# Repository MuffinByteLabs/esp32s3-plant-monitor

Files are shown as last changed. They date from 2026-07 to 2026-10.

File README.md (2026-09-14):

# ESP32-S3 Plant Monitor — Rev A

**Ray Malik** · [muffinbytelabs.com](https://muffinbytelabs.com) · [muffinbytelabs@gmail.com](mailto:muffinbytelabs@gmail.com)

A solo hardware project taken the whole way: requirements → schematic capture → 4-layer layout → DFM → fab and assembly order → bring-up. Every schematic, review, waiver and decision in this repo is my own work.

Wi-Fi plant monitor: soil moisture, temperature / humidity / pressure, and ambient light, USB-C powered with 1-cell LiPo charging and automatic USB↔battery hand-over. Native-USB programming, no bridge chip. KiCad 10 hierarchical schematic, **4-layer board** (signal / GND / GND / signal, JLC04161H-7628), 62.5 × 44.5 mm, ordered fabricated and assembled at JLCPCB on **2026-08-21**.

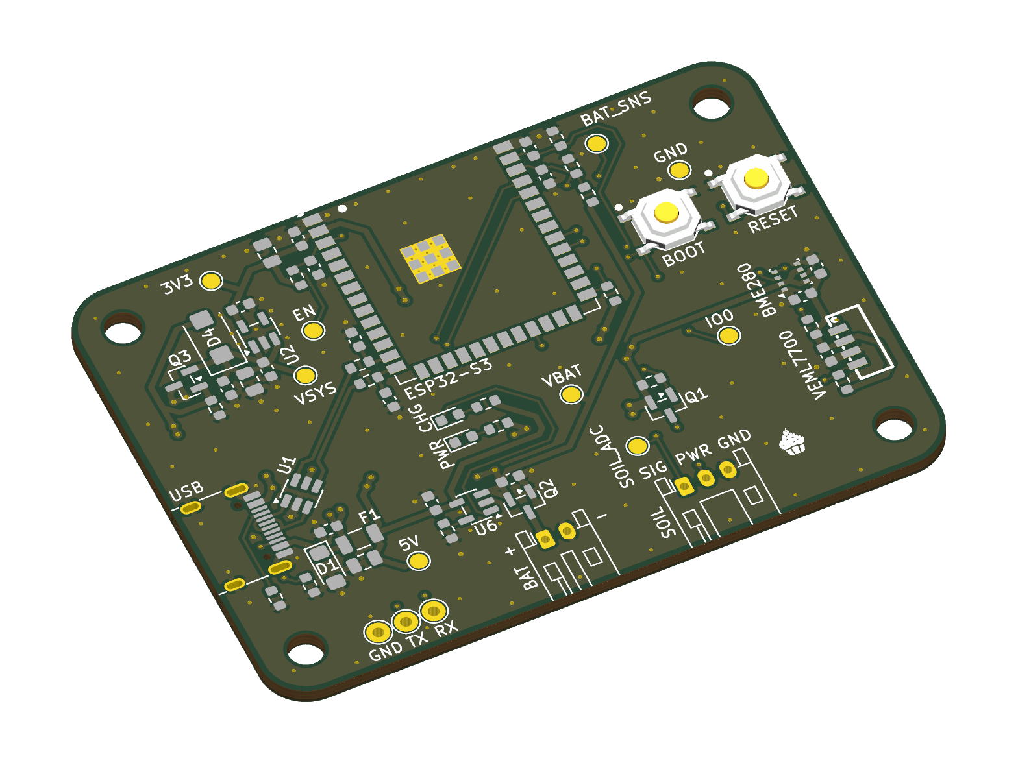
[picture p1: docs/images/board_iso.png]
ESP32-S3 Plant Monitor Rev A — 3D render


| | |
|---|---|
| **MCU** | ESP32-S3-WROOM-1-N8, native USB — no bridge chip |
| **Sensors** | BME280 (temperature / humidity / pressure) · VEML7700 (ambient light) · DFRobot SEN0193 capacitive soil probe |
| **Power** | USB-C 5 V → PPTC + TVS → AP2112K-3.3 (600 mA) · MCP73831 1S LiPo charger · discrete USB↔battery load share, hand-over in ≈50–100 ms |
| **Sleep** | ≈210 µA as built (≈90 µA with the power LED unfitted) ⇒ ~100 days on a 500 mAh cell |
| **Board** | 62.5 × 44.5 mm · 4-layer, JLC04161H-7628 · 1.6 mm · lead-free HASL · 404 track segments, 154 vias |
| **Verification** | 6 written reviews · 20 packages / 69 placements checked against datasheets |
| **Built** | 5 boards fabricated + assembled for ≈$49 after coupons, every part pre-stocked in the JLC library |
| **Tools** | KiCad 10 · JLCPCB Standard PCBA |

## Start here

Everything below opens in the browser — no KiCad install, no downloads.

| | |
|---|---|
| 📐 **[Schematic (PDF, 8 sheets)](docs/ESP32S3_PlantMonitor_RevA_Schematic.pdf)** | The whole design, plotted from the board file that was ordered |
| 📄 **[Design document](docs/ESP32S3_Plant_Monitor_Final_Design_Document.md)** | Every component and why it is there, written to be read by someone who is not a PCB engineer |
| 🔍 **[Design reviews — 6 on file](docs/reviews/)** | Real review records with findings, severities and fixes. The pre-fab review caught **3 blocking errors** — floating USB-C ground pins, a missing battery-sense chain, and a stale BOM — all resolved before ordering |
| 🧭 **[What I'd change in Rev B](docs/RevB_Upgrade_Plan.md)** | Ranked upgrades with a three-way charger-IC comparison and a costed path from 210 µA to 15–35 µA |
| 🧪 **[Engineering notes](docs/Engineering_Notes.md)** | Bench measurements: soil calibration, the three-layer battery-protection analysis, the hand-over walkthrough |
| 🏭 **[Frozen manufacturing package](fabrication/revA/)** | The exact gerber zip, BOM and CPL uploaded to JLCPCB, beside [`ORDER_NOTES.md`](fabrication/revA/ORDER_NOTES.md) — every setting the board was ordered with |
| 🔧 **[Bring-up guide](docs/BringUp_Guide.md)** | First-power procedure, expected voltages, probe points, troubleshooting |
| 🖨 **[Fab layer plots (PDF)](docs/ESP32S3_PlantMonitor_RevA_FabLayers.pdf)** | All four copper layers, both silks, mask and paste — what the fab actually receives |

| Top | Bottom |
|---|---|
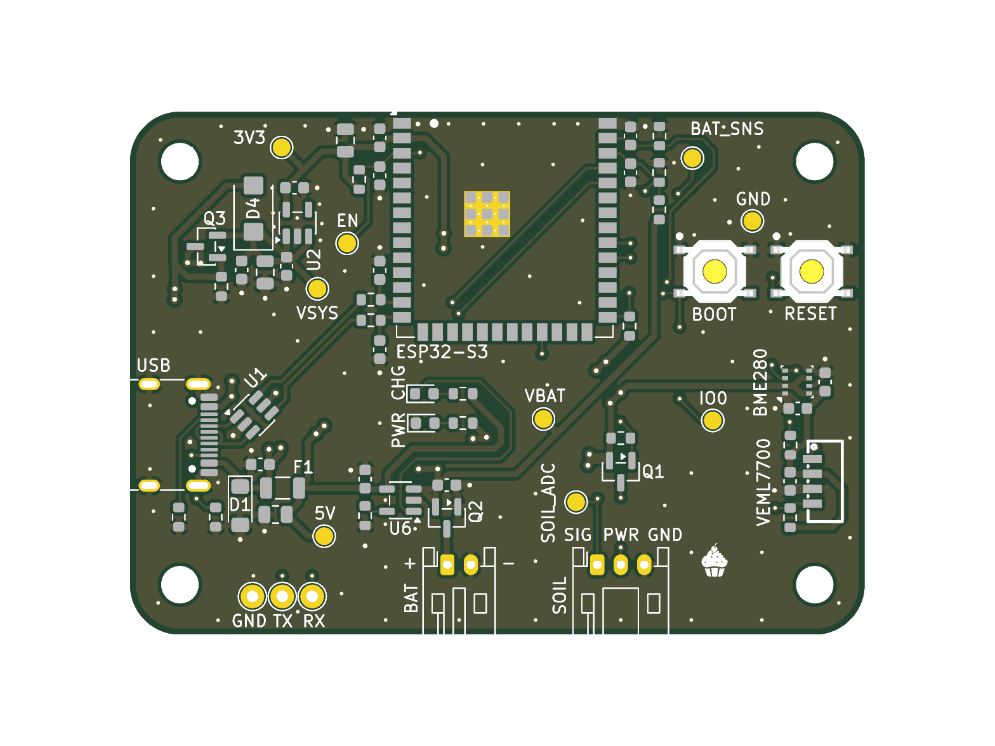
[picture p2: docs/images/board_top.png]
Top
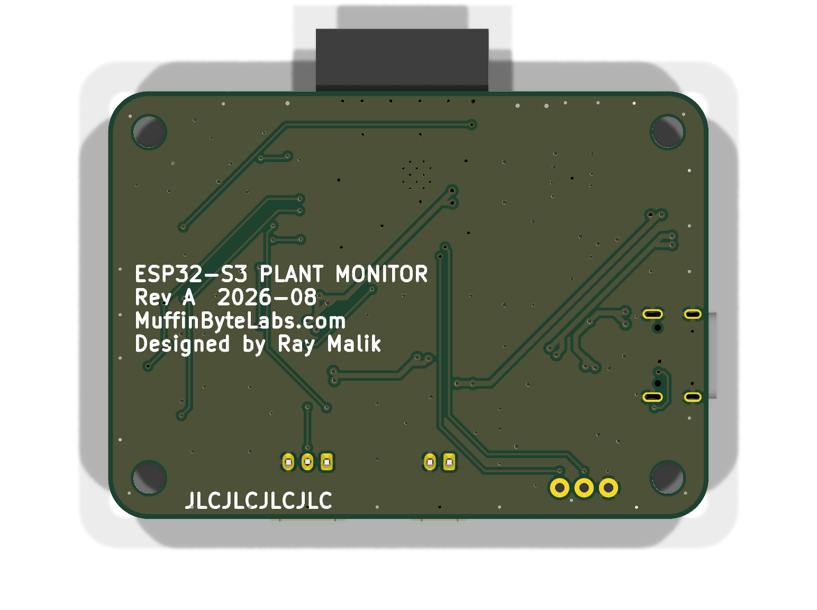
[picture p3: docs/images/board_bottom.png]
Bottom
|  |  |

## What this board demonstrates

- **4-layer discipline** — dual unbroken ground planes, zero signals on the inner layers, a via at every decoupler, stitching around the antenna keep-out.
- **RF module integration** — antenna nose overhanging the board edge, all-layer keepout, ground ring, and a panel-rail instruction written into the fab remark so breakaway tabs cannot sit under the overhang.
- **USB 2.0 pair** at ≈90 Ω coupled geometry, length-matched, no vias, ESD in copper order.
- **Power-path design with numbers** — fuse → TVS → LDO, an automatic USB↔battery hand-over sized so the switch completes in ≈50–100 ms, and a 210 µA sleep budget with a named dominant contributor.
- **Manufacturing fluency** — DFM checked against JLCPCB's live capability pages, part-tier economics understood before ordering, pre-stocked parts library, DDP tariff handling.
- **A documentation trail** — two design reviews, a placement review, a finishing review, a final layout audit, and order notes, all on record here.

## What I'd change in Rev B

- **The power path is discrete, and it shows.** MCP73831 + Schottky + P-FET load-sharing works, but it has a ≈50–100 ms body-diode notch at USB unplug, a Vgs-dependent switch point, and no charge safety timer. Rev B replaces the four-part cluster with one IC — [BQ24075 vs MCP73871 vs TPS2113A, compared](docs/RevB_Upgrade_Plan.md#1-integrated-power-path-the-headline-upgrade).
- **210 µA of sleep current is too high**, and the power LED alone is 120 µA of it. LED on a solder jumper, a nanopower LDO, and a switched sense divider get it to 15–35 µA — months to years of standby instead of weeks.
- **No series element on the soil-probe ADC input.** The probe cable is a metre-long antenna into a bare pin; Rev A has only a parallel pull-down. Series resistor plus TVS at J2 next time.
- **Four layers were bought for margin, not for speed.** The fastest signal on this board is USB Full Speed — a disciplined 2-layer board would have worked. The reasoning for spending the extra layers is written down in [`docs/KiCad_Settings_RevA.md`](docs/KiCad_Settings_RevA.md).

<details>
<summary><strong>Repository map</strong> — 24 documents, KiCad sources, frozen fab package, datasheets</summary>

| Path | What |
|---|---|
| [`hardware/`](hardware/) | KiCad 10 project — root sheet + sheets 02–08, libraries in `hardware/libs/`. Library paths are `${KIPRJMOD}`-relative; keep `libs/` inside `hardware/`. |
| [`fabrication/revA/`](fabrication/revA/) | The frozen order package: gerber zip, BOM, CPL, and `ORDER_NOTES.md` (§7 = the as-ordered record) |
| **Documents** | |
| [`docs/ESP32S3_PlantMonitor_RevA_Schematic.pdf`](docs/ESP32S3_PlantMonitor_RevA_Schematic.pdf) | All 8 schematic sheets, plotted from the ordered board file |
| [`docs/ESP32S3_PlantMonitor_RevA_FabLayers.pdf`](docs/ESP32S3_PlantMonitor_RevA_FabLayers.pdf) | Layer-by-layer fab plots |
| [`docs/ESP32S3_Plant_Monitor_Final_Design_Document.md`](docs/ESP32S3_Plant_Monitor_Final_Design_Document.md) | The full design document — as-built designators throughout; Addendum A holds the renumbering record |
| [`docs/PROJECT_STATUS.md`](docs/PROJECT_STATUS.md) | Rev A order and build log: what was ordered, what it cost, order-day problems and fixes, waivers on record |
| [`docs/BringUp_Guide.md`](docs/BringUp_Guide.md) | First-power procedure, expected voltages, probe points |
| [`docs/PinMap_CheatSheet.md`](docs/PinMap_CheatSheet.md) | GPIO / net / connector map, as built |
| [`docs/Engineering_Notes.md`](docs/Engineering_Notes.md) | Bench notes: calibration values, battery-protection analysis, hand-over walkthrough |
| [`docs/ESP32S3_PlantMonitor_RevA_BOM.md`](docs/ESP32S3_PlantMonitor_RevA_BOM.md) | BOM as a readable table (the [`.xlsx`](docs/ESP32S3_PlantMonitor_RevA_BOM.xlsx) is the editable source) |
| **Layout rulebooks** | |
| [`docs/Hard_Rules_Layout_RevA.md`](docs/Hard_Rules_Layout_RevA.md) | The graded rulebook — LAW vs STRONG PRACTICE, plus 4-layer amendments |
| [`docs/Routing_Guide_RevA_4Layer.md`](docs/Routing_Guide_RevA_4Layer.md) | Layer strategy, net-by-net routing order, via craft |
| [`docs/KiCad_Settings_RevA.md`](docs/KiCad_Settings_RevA.md) | Every board-setup value and the reasoning behind it |
| [`docs/Layout_Readiness_and_Placement_Guide_RevA.md`](docs/Layout_Readiness_and_Placement_Guide_RevA.md) | Footprint verification + placement playbook |
| [`docs/Footprint_Check_ESP32S3_PlantMonitor_RevA.md`](docs/Footprint_Check_ESP32S3_PlantMonitor_RevA.md) | All 20 packages / 69 placements, each checked against its datasheet |
| [`docs/Footprint_Terms_and_Leeway_Guide.md`](docs/Footprint_Terms_and_Leeway_Guide.md) | Plain-English footprint terms and how much tolerance actually matters |
| [`docs/Fabrication_File_Primer.md`](docs/Fabrication_File_Primer.md) | What each gerber and drill file is, and why |
| [`docs/Finishing_Guide_RevA.md`](docs/Finishing_Guide_RevA.md) | Silkscreen, branding and pre-order finishing pass |
| [`docs/RevB_Upgrade_Plan.md`](docs/RevB_Upgrade_Plan.md) | Ranked upgrades, integrated power path first |
| **Reviews** | |
| [`docs/reviews/`](docs/reviews/README.md) | All six reviews, [indexed here](docs/reviews/README.md) with date, scope, method and outcome |
| **References** | |
| [`references/datasheets/`](references/datasheets/) | Vendor datasheets for every part — [indexed here](references/datasheets/README.md) |
| [`references/JLCPCB_Capabilities_2026-08.md`](references/JLCPCB_Capabilities_2026-08.md) | Capability quick-sheet used for DFM |
| [`references/reference-designs/`](references/reference-designs/) | Espressif DevKitC-1 schematic |
| [`firmware/`](firmware/) | The hardware→firmware contract: thresholds, sequences and pin duties the board imposes |

</details>

## What's next

Boards arrive early September. Bring-up follows [`docs/BringUp_Guide.md`](docs/BringUp_Guide.md) — measured results go into its record sheet, and a photograph of the working board replaces the render above.

Questions, or hiring: **[muffinbytelabs@gmail.com](mailto:muffinbytelabs@gmail.com)** · [muffinbytelabs.com](https://muffinbytelabs.com)

## License

Hardware design files and documentation are released under the **CERN Open Hardware Licence v2 — Permissive** (see [`LICENSE`](LICENSE)). Vendor datasheets in `references/datasheets/` remain the property of their respective manufacturers and are included for convenience only.

## Safety notes for anyone building this board

1. **Meter the battery plug polarity** before it ever touches J3 — the charge LED is not proof of polarity.
2. **Protected cells only**, and never store the board with a battery attached (≈210 µA sleep floor).
3. **Firmware enforces the battery limits**: no Wi-Fi TX below ~3.5 V, deep sleep at 3.0 V.

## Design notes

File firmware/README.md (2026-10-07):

# Firmware — Rev A

The sketch lives in [`plant_monitor/`](plant_monitor/). It is written for the
Arduino IDE, because that is what I code in, and it is split across a handful of
files in one sketch folder — the IDE opens them as tabs, so it is still one
thing to open and one button to press.

**Status: running on Rev A board #1.** It came through an 11-hour battery soak
(249 wake cycles, no resets), and as of 2026-09-13 it runs the full cycle on a
30-minute interval, logging every wake to ThingSpeak. The soil calibration is
now the board's own, re-recorded through this probe and cable at bring-up step
D-11. Bring-up is not finished: the charge-termination check, the hand-over
scope test, the battery-only cold boot and the sleep-current measurement are
still open, and [`BringUp_Progress_RevA_Board1.md`](../docs/BringUp_Progress_RevA_Board1.md)
tracks every step.

It builds for the ESP32-S3 against Arduino-ESP32 2.0.17 with Adafruit BME280
2.3.0, Adafruit VEML7700 2.1.6 and PubSubClient 2.8.0; the HTTP clients the
ThingSpeak and ntfy paths use come with the core. The 2026-08-24 build, before
those two paths went in, was warning-free at 750 kB of flash and 48 kB of RAM,
about a fifth of the app partition.

---

## The hardware contract

This is what the *board* requires of the firmware. It was written down before
any code existed, so the safety and measurement behaviour would be on record
either way. Pin assignments are in
[`../docs/PinMap_CheatSheet.md`](../docs/PinMap_CheatSheet.md).

| Duty | Rule | Why, and where it comes from |
|---|---|---|
| **Wi-Fi TX cutoff** | No transmit below **≈3.5 V** battery | A regulator rule, not a battery rule: the AP2112K needs ≈200 mV of headroom to hold 3.3 V through a 355 mA TX peak — [`Engineering_Notes.md`](../docs/Engineering_Notes.md) §4 |
| **Deep-sleep cutoff** | Shut everything down at **3.0 V** | The pack's protection module does not trip until 2.5 V. That half-volt gap belongs to firmware and nothing else — [`Engineering_Notes.md`](../docs/Engineering_Notes.md) §3 |
| **Battery reporting** | Gate battery percentage on **USB absent** | With USB connected and no cell fitted, the charger floats VBAT to ≈4.2 V and BAT_SENSE reads "full" |
| **Soil measurement** | GPIO21 LOW → wait ≥200 ms → read GPIO1 → GPIO21 HIGH | The probe is firmware-switched so it does not drain the cell between readings |
| **Soil calibration** | Dry **2267** raw, wet **1229** raw (12-bit, ATTEN=3) | Re-recorded on board #1 through its own probe and cable at bring-up step D-11, 2026-09-13. The breadboard values (2900 / 1465) left the scale without its bottom half — [`Engineering_Notes.md`](../docs/Engineering_Notes.md) §1 |
| **I²C** | BME280 at **0x76**, VEML7700 at **0x10**; `Wire.begin(38, 39)` — SDA first | Bus re-pinned to IO38/IO39 during layout — [`PinMap_CheatSheet.md`](../docs/PinMap_CheatSheet.md) |
| **Brown-out** | Expect a ≈50–100 ms dip on VSYS at USB unplug | Discrete load-sharing hand-over. If a reset appears there at low battery, relax the brown-out detector across the transition — [`BringUp_Guide.md`](../docs/BringUp_Guide.md) step 9 |

Every one of those rows is enforced somewhere in the code, and the code says so
at the point it does it.

---

## What one wake cycle does

There is no `loop()` in the usual sense. The board wakes from deep sleep, runs
`setup()` once, and sleeps again at the end of it.

1. **Read the battery first**, before anything expensive has loaded the cell.
2. **Below 3.0 V, stop.** No readings, no radio — sleep 6 hours and check again.
   I keep waking, rarely, because a board that stopped waking entirely could
   never notice it had been put on the charger.
3. **Switch the soil probe on** and start its 250 ms settle clock.
4. **Read the BME280 and VEML7700 while that clock runs.** The settle time has
   to be spent either way, so it may as well be spent working.
5. **Read the probe, switch it off.** Releasing GPIO21 rather than driving it
   high lets R10 hold Q1 off with no drive current, through sleep and through
   the next boot.
6. **Below 3.5 V, skip the radio** and keep the readings to myself this cycle.
   Otherwise associate, log the readings to ThingSpeak, send an ntfy push
   notification only when an alert appears, clears or is due a reminder, and
   disconnect. MQTT with Home Assistant discovery is still in the code, switched
   off with `USE_MQTT`.
7. **Sleep 30 minutes.**

A hard 30-second deadline sits over the whole thing. Any stage that finds it
gone gives up rather than starting something new — losing one reading is much
cheaper than sitting at 80 mA on a cell I want to last a hundred days.

---

## The files

| File | What is in it |
|---|---|
| [`plant_monitor.ino`](plant_monitor/plant_monitor.ino) | The wake cycle, in order, and the alert rules it applies |
| [`config.h`](plant_monitor/config.h) | Every number the board imposes — pins, thresholds, calibration, timing — with the document each came from |
| `secrets.h` | Wi-Fi credentials, the ntfy topic, and the ThingSpeak and broker keys. **Gitignored.** Never committed |
| [`secrets.h.example`](plant_monitor/secrets.h.example) | The template to copy |
| [`power.h`](plant_monitor/power.h) / [`.cpp`](plant_monitor/power.cpp) | Battery reading, the two thresholds, the discharge curve, and the only route to deep sleep |
| [`sensors.h`](plant_monitor/sensors.h) / [`.cpp`](plant_monitor/sensors.cpp) | The three measurements, each allowed to fail without costing the cycle |
| [`net.h`](plant_monitor/net.h) / [`.cpp`](plant_monitor/net.cpp) | Wi-Fi, ThingSpeak logging, ntfy push notifications, and MQTT with the Home Assistant discovery payloads |
| [`adc.h`](plant_monitor/adc.h) | The one place either analogue input gets read |
| [`log.h`](plant_monitor/log.h) | Printing that compiles away entirely when it is switched off |

The bring-up helpers sit beside the sketch: [`bringup_check`](bringup_check/) for
steps 4–6, [`sensor_check`](sensor_check/) for a plain sensor read, and
[`handover_check`](handover_check/) for steps 9 and 10.

---

## Building it

### 1. Board support

Arduino IDE → **File → Preferences → Additional board manager URLs**, add:

```
https://espressif.github.io/arduino-esp32/package_esp32_index.json
```

Then **Tools → Board → Boards Manager**, install **esp32 by Espressif Systems**.

### 2. Libraries

**Tools → Manage Libraries**, install:

* **Adafruit BME280 Library** (pulls in Adafruit Unified Sensor and Adafruit BusIO)
* **Adafruit VEML7700 Library**
* **PubSubClient** by Nick O'Leary

### 3. Credentials

Copy `plant_monitor/secrets.h.example` to `plant_monitor/secrets.h` and fill it
in. The IDE will not show `.example` as a tab, so do this in a file manager or a
terminal, then reopen the sketch.

```
copy plant_monitor\secrets.h.example plant_monitor\secrets.h     :: Windows
cp   plant_monitor/secrets.h.example plant_monitor/secrets.h     #  macOS/Linux
```

`secrets.h` is in [`.gitignore`](../.gitignore) and stays there. If it is
missing the build stops with a message saying so rather than failing somewhere
confusing.

### 4. Board settings

**Tools → Board → esp32 → ESP32S3 Dev Module**, then:

| Setting | Value | Why |
|---|---|---|
| USB CDC On Boot | **Enabled** | `Serial` is the native USB. There is no bridge chip on this board |
| USB Mode | **Hardware CDC and JTAG** | IO19/IO20 go straight to the USB Serial/JTAG peripheral |
| Upload Mode | **UART0 / Hardware CDC** | |
| Flash Size | **8MB (64Mb)** | The module is a WROOM-1-**N8** |
| PSRAM | **Disabled** | N8 has none. N8**R2** would |
| Partition Scheme | **8M with spiffs (3MB APP/1.5MB SPIFFS)** | |
| CPU Frequency | 240 MHz | Finishing the wake cycle sooner beats running it slower |

If it will not enter the bootloader on its own: hold **SW1 (BOOT)**, tap
**SW2 (RESET)**, release SW1, then upload.

---

## Things I know are not right yet

* **There is no VBUS sense line on Rev A.** I never brought +5V_PROT to a GPIO,
  so the firmware cannot actually tell whether USB is supplying the board. What
  it can tell is whether a USB *host* has opened the CDC port, and it uses that
  as a stand-in for gating the battery percentage. That is right at the bench
  and wrong on a phone charger, which supplies VBUS and never opens a port. A
  divider from +5V_PROT to a spare pin fixes it properly — it is on the Rev B
  list.
* **No OTA.** Every update is over the USB cable. On a board that spends 99.9 %
  of its life in deep sleep, an OTA window costs more current than it saves me
  walking over to it.
* **Nothing is written to flash between wakes.** If I later want gap-free
  history through a Wi-Fi outage, the readings would have to go somewhere that
  survives sleep. Right now a missed publish is simply a missed reading.

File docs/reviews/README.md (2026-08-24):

# Design Reviews — ESP32-S3 Plant Monitor Rev A

Six reviews on file, running from schematic capture to the last check before the order went to JLCPCB. Each one is a real record: what was examined, how, what was found, and what changed as a result. Nothing here is a summary written after the fact.

| Date | Review | Method | Outcome |
|---|---|---|---|
| 2026-07-20 | [Pre-fabrication design review](Design_Review_RevA_2026-07-20.md) | Netlist parsed from the `.kicad_sch` sources to pin level, cross-checked against every datasheet in `references/` | **3 blocking findings**, all resolved the same day — see below |
| 2026-07-22 | [Pre-layout review: netlist re-extraction](Design_Review_RevA_2026-07-22_Netlist_Reextraction.md) | Netlist rebuilt from source a second time, independently of the first pass, plus a full datasheet cross-check | No blocking or functional findings. Cleared for layout |
| 2026-08-10 | [Placement review](Placement_Review_RevA_2026-08-10.md) | Component-by-component against the placement rulebook, with an [annotated map](Placement_Review_RevA_2026-08-10_map.png) | Outline shrink, module re-centring and connector clearances; [v2 status](Placement_Review_RevA_2026-08-12_v2_status.md) confirms each item landed |
| 2026-08-12 | [Placement review v2 status](Placement_Review_RevA_2026-08-12_v2_status.md) | Re-check of every 08-10 item against the revised board, with an [annotated map](Placement_Review_RevA_2026-08-12_v2_map.png) | All items closed; outline down to 62.5 × 44.5 mm with R4.25 corners |
| 2026-08-16 | [Finishing review](Finishing_Review_RevA_2026-08-16.md) | Scripted geometry pass over the saved board file — silkscreen, branding, zone fills, LCSC coverage | Silkscreen and DNP/BOM-exclusion fixes before the final audit |
| 2026-08-17 | [Final layout audit](Final_Layout_Review_RevA_2026-08-17.md) | KiCad 10.0.5 headless DRC with zone refill and schematic parity, plus an s-expression geometry audit of every rule in the rulebook | **0 errors · 0 unconnected · 0 parity differences.** Cleared to order |

## The three blocking findings, 2026-07-20

These are the reason the review process exists, and all three were caught before any money was spent:

1. **USB-C ground pins were no-connected.** J1's A1/B1/A12/B12 carried an explicit no-connect flag and touched no copper — ERC was clean precisely *because* the flag told it the omission was intentional. Those four pins are the DC return for every milliamp of VBUS current and the reference for D+/D−; the shield is a separate EMI screen, not a supply return. Symptoms would have ranged from "works with cable A, dead with cable B" to a defeated ESD strategy. Fixed and re-verified the same afternoon.
2. **The saved files were missing the battery-sense chain.** Battery monitoring existed in the design document but not in the committed schematic — the board would have shipped with no way to read its own battery voltage.
3. **The BOM was stale.** Designators no longer matched the schematic, which for an assembled order means parts placed at the wrong references.

A fourth finding, ranked RISKY rather than blocking, changed R16 from 100 kΩ to 10 kΩ: at 100 kΩ the USB-unplug hand-over took 0.5–1 s of body-diode sag, long enough to brown out the MCU on every unplug at mid-battery. At 10 kΩ it completes in ≈50–100 ms.

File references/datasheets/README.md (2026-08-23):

# Datasheet index

Every part on the board, mapped to the document it was designed against. Reference designators are
as-built and match the [schematic](../../docs/ESP32S3_PlantMonitor_RevA_Schematic.pdf) and the
[ordered BOM](../../fabrication/revA/BOM-ESP32S3_PlantMonitor.csv).

## On the board

| Ref | Part | JLC # | Datasheet |
|---|---|---|---|
| U1 | USBLC6-2SC6 USB ESD array | C7519 | [ESD_ST_USBLC6-2SC6](ESD_ST_USBLC6-2SC6_USB2_DataLine_Protection_Datasheet.pdf) |
| U2 | AP2112K-3.3 LDO | C51118 | [LDO_Diodes_AP2112K-3.3](LDO_Diodes_AP2112K-3.3_600mA_3V3_Regulator_Datasheet.pdf) |
| U3 | ESP32-S3-WROOM-1-N8 module | C2913198 | [ESP32S3_Espressif_WROOM-1](ESP32S3_Espressif_WROOM-1_WROOM-1U_Module_Datasheet_v1.8.pdf) |
| U4 | BME280 temp / humidity / pressure | C92489 | [SENSOR_Bosch_BME280](SENSOR_Bosch_BME280_Temperature_Humidity_Pressure_Datasheet_Rev1.24_2024.pdf) |
| U5 | VEML7700-TT ambient light | C1850416 | [SENSOR_Vishay_VEML7700](SENSOR_Vishay_VEML7700_Ambient_Light_I2C_Datasheet_Rev1.8_2024.pdf) |
| U6 | MCP73831 LiPo charger | C424093 | [CHARGER_Microchip_MCP73831](CHARGER_Microchip_MCP73831_LiPo_Linear_Charger_Datasheet_DS20001984H.pdf) |
| Q1–Q3 | AO3401A P-channel MOSFET | C15127 | [MOSFET_AlphaOmega_AO3401A](MOSFET_AlphaOmega_AO3401A_PchannelMOSFET_Datasheet.pdf) |
| D1 | SMF5.0A TVS | C2980403 | [TVS_MDD_SMF5_0A](TVS_MDD_SMF5_0A_5V_Unidirectional_Datasheet.pdf) |
| D2 | Yellow-green LED 0603 (power) | C2289 | [LED_XINGLIGHT_XL-0603QYGC](LED_XINGLIGHT_XL-0603QYGC_YellowGreen_0603_C2289_Datasheet.pdf) |
| D3 | Red LED 0603 (charge) | C2286 | [LED_KENTO_KT-0603R](LED_KENTO_KT-0603R_Red_0603_C2286_Datasheet.pdf) |
| D4 | SS14 Schottky 1 A / 40 V | C2480 | [DIODE_SS14](DIODE_SS14_Schottky_1A40V_Family_Datasheet.pdf) |
| F1 | 1206L075/16WR resettable PPTC fuse | C371166 | [FUSE_Littelfuse_1206L](FUSE_Littelfuse_1206L_Resettable_PPTC_Datasheet_2024.pdf) |
| J1 | TYPE-C-31-M-12 USB-C receptacle | C165948 | [USBC_TYPE-C-31-M-12](USBC_TYPE-C-31-M-12_Receptacle_C165948_Footprint_Drawing.pdf) |
| J2, J3 | JST PH 2.0 mm headers | C157929 / C173752 | [CONN_JST_PH_2.0mm](CONN_JST_PH_2.0mm_Crimp_Connector_Family_Datasheet.pdf) |
| SW1, SW2 | XKB TS-1187A tactile switch | C318884 | [SWITCH_XKB_TS-1187A](SWITCH_XKB_TS-1187A_Tactile_SMD_5.1x5.1_H1.5_C318884_Datasheet.pdf) |
| C1–C18 | Samsung MLCC 0603 / 0805 | various | [CAP_Samsung_MLCC_Catalogue](CAP_Samsung_MLCC_Catalogue_2015-11.pdf) — general catalogue, covers both C19666 (4.7 µF 0603) and C45783 (22 µF 0805) |
| R1–R16 | Chip resistors 0603 | various | Generic 0603 thick-film; values and JLC numbers in the [BOM](../../docs/ESP32S3_PlantMonitor_RevA_BOM.md) |

## Off-board — bought separately

| Part | Plugs into | Datasheet |
|---|---|---|
| DFRobot SEN0193 capacitive soil probe | J2 | [SENSOR_DFRobot_SEN0193](SENSOR_DFRobot_SEN0193_Capacitive_Soil_Moisture_Module_Web_Datasheet.pdf) |
| PKCell LP503035 500 mAh 1S LiPo with PCM | J3 | [BATTERY_C1854_PKCell](BATTERY_C1854_PKCell_Datasheet_Li-Polymer_503035_500mAh_3.7V_with_PCM.pdf) |

## Design guidance

| Document | Used for |
|---|---|
| [ESP32-S3 Hardware Design Guidelines](ESP32S3_Espressif_Hardware_Design_Guidelines_2026-06-23.pdf) | Power entrance, decoupling, strapping pins, antenna keep-out, ADC handling — the rules in `docs/Hard_Rules_Layout_RevA.md` trace back here |
| [DevKitC-1 reference schematic](../reference-designs/ESP32S3_Espressif_DevKitC-1_Schematic_v1.1_2022-04-13.pdf) | Reference implementation cross-check |

---

All datasheets remain the property of their respective manufacturers and are included here for
convenience. Copyrighted standards are **not** redistributed — see [`../standards/`](../standards/).

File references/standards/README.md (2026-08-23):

# Standards & reference texts

These are **deliberately not in the repository** — they are copyrighted works that cannot be
redistributed. They are listed here so the sources behind this board's rules are on the record, and
kept locally outside the repo tree.

| Work | What this project uses it for |
|---|---|
| **IPC-2221** — Generic Standard on Printed Board Design | Conductor sizing and clearance/creepage numbers; the trace widths in `docs/Hard_Rules_Layout_RevA.md` were checked against it |
| **Ritchey, *Right the First Time: A Practical Handbook on High-Speed PCB and System Design*, Vol. 1** (Speeding Edge) | The return-current and stackup reasoning behind this board's 4-layer strategy — see `docs/Routing_Guide_RevA_4Layer.md` |

Vendor datasheets, which *are* freely redistributable, live in
[`../datasheets/`](../datasheets/) and are indexed there.

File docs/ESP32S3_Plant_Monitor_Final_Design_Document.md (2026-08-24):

# ESP32-S3 Plant Monitor — Rev A Design Document

**Board:** 62.5 × 44.5 mm · 4-layer (signal / GND / GND / signal, JLC04161H-7628) · 1.6 mm · lead-free HASL

**Status:** ordered at JLCPCB 2026-08-21 · **Written** 2026-07-04 · **Revised to as-built** 2026-08-23

> **Every reference designator below is as-built.** They match the KiCad schematic, the
> [schematic PDF](ESP32S3_PlantMonitor_RevA_Schematic.pdf) and the
> [ordered BOM](../fabrication/revA/BOM-ESP32S3_PlantMonitor.csv). Earlier drafts of this document
> used planning-stage designators; the full renumbering record is in **Addendum A**.

*This document is the single complete description of the board: what it does, how the circuitry works, every component and why it is there, and how the design will be captured, manufactured, assembled, and brought to life. It is organized to match the KiCad hierarchical schematic sheets, so each section of this document becomes one sheet of the schematic.*

*Plain-language rule used throughout: every abbreviation is expanded where it appears, and repeated later, so no section requires remembering a definition from another section.*

## 1. Project Overview

Goal: a small, manufacturable Wi-Fi plant monitor. It sits by a plant, measures soil moisture, air temperature, humidity, barometric pressure, and ambient light, and reports the readings over Wi-Fi. It is powered by USB-C, and it also runs from a rechargeable single-cell lithium-polymer battery when USB is unplugged. The same USB-C port charges the battery.

The board is a portfolio project: every choice below follows industry-standard practice for a first-spin four-layer board, and every deviation from standard practice is called out openly in Section 15.

### What the board does

- Reads soil moisture with an external capacitive probe (DFRobot SEN0193) plugged into a connector.

- Reads air temperature, relative humidity, and barometric pressure with one on-board sensor (BME280).

- Reads ambient light with a second on-board sensor (VEML7700).

- Connects to Wi-Fi and is programmed over its USB-C port — no external programmer needed.

- Charges a 1-cell lithium-polymer battery and automatically runs from it when USB power is removed.

- Measures its own battery voltage so the firmware can report battery percentage.

- Switches power to the soil probe on and off in firmware, so the probe does not drain the battery between readings.

### Success criteria

- Board powers up on USB-C, enumerates as a USB device, and accepts firmware.

- All sensors read correctly; soil readings are calibrated (dry value and wet value recorded).

- Unplugging USB while running does not reset the board — it hands over to the battery seamlessly.

- Battery charges at roughly 100 mA and the charge LED behaves as described in Section 8.

- Deep sleep current is low enough for multi-week battery operation (estimate in Section 2).

## 2. System Architecture — Sheet 01_System

The top schematic sheet (01_System) holds no components. It contains the hierarchy: one block per sub-sheet, connected by named nets. A net is simply a named wire; two points with the same net name are electrically the same wire, even across sheets.

### Power flow, in one paragraph

USB-C delivers 5 V. That 5 V passes a surge-protection diode and a resettable fuse and becomes the protected 5 V rail, called +5V_PROT. From +5V_PROT, two things happen: the battery charger charges the battery, and a Schottky diode feeds the system supply node, called VSYS. When USB is present, VSYS is about 4.6 V and the battery is disconnected from the load. When USB is removed, an automatic MOSFET switch connects the battery to VSYS instead — with no gap the processor can notice. VSYS feeds a 3.3 V regulator, and the regulator's output rail, +3V3, powers everything that thinks or senses: the ESP32-S3 module, both I2C sensors, and (through its own switch) the soil probe.

### The two working voltages

- 5 V side (+5V_PROT): the battery charger, the charge LED, and the input of the power path. Everything upstream of the regulator.

- 3.3 V side (+3V3): the ESP32-S3 brain, the BME280, the VEML7700, the soil probe, all pull-up resistors, and the power LED. Everything that runs code or measures.

- GND (ground, 0 V): the single shared reference every voltage is measured against. All grounds on the board are one net.

### Net name glossary

| Net name | Meaning |
|---|---|
| USB_VBUS | Raw 5 V at the USB-C connector, before the fuse. |
| +5V_PROT | Protected 5 V, after the fuse. The 5 V rail everything actually uses. |
| VSYS | System supply node: 5 V (minus a diode drop) when USB is present, battery voltage when it is not. Feeds the regulator. |
| +3V3 | The regulated 3.3 V rail from the AP2112 regulator. |
| VBAT_RAW | Battery connector positive pin, before reverse-polarity protection. |
| VBAT | Protected battery rail, after the reverse-protection MOSFET. The charger and power path connect here. |
| BAT_SENSE | Divided-down battery voltage (half of VBAT) going to an analog input for battery-percentage measurement. |
| USB_DP / USB_DN | USB data plus / data minus, from the connector to the ESP32-S3's native USB pins. |
| SCL / SDA | The shared two-wire sensor bus: clock line and data line. |
| SOIL_PWR | Switched 3.3 V that powers the soil probe only when firmware enables it. |
| SENS_PWR_EN | The control signal (from GPIO21) that turns the soil-probe power switch on and off. |
| ADC_SOIL | Soil-probe output going to an analog input — direct, no divider (see §7); R11 (100 kΩ) holds the pin down while the probe is off. |

### Current budget (worst case, everything peaking at once)

A current budget is a list of every load and its worst-case draw, added up, to prove the supply and the fuse can cover it. Values verified against each part's datasheet.

| Load on +3V3 | Peak current | Notes |
|---|---|---|
| ESP32-S3 module (Wi-Fi transmit peak) | 355 mA | Budgeted as 500 mA supply capability per Espressif. |
| Soil probe SEN0193 | ≈5 mA | Only while switched on by firmware. |
| Power LED D2 | ≈0.12 mA | On whenever +3V3 is up. |
| I2C pull-ups (both lines held low) | ≈1.4 mA | Brief, during bus traffic. |
| BME280 (measuring) | ≈1 mA | Micro-amps between measurements. |
| VEML7700 | ≈0.05 mA | Tiny. |
| Total 3.3 V side | ≈365 mA | Regulator capability: 600 mA — passes. |

On the 5 V side, the fuse additionally carries the battery charge current (about 100 mA) at the same time. Worst simultaneous case is therefore roughly 465 mA. The fuse holds 750 mA at room temperature and 650 mA at 40 °C — comfortable margin either way.

### Power modes

- USB plugged, battery present: board runs from USB; battery charges; charge LED lights until full.

- USB plugged, no battery: board runs from USB normally; charger sits idle (its status pin floats — the charge LED may flicker faintly; this is expected and harmless).

- USB unplugged, battery present: board runs from the battery. The 3.3 V rail stays clean while the battery is above roughly 3.6 V, then gracefully follows the battery downward. The firmware reads BAT_SENSE and reports the level.

### Estimated battery life (deep sleep)

Baseline sleep current: regulator quiescent ≈55 µA, battery-sense divider ≈21 µA, power LED ≈120 µA (dominant — remove D2 for battery-life tests), ESP32-S3 deep sleep ≈10–20 µA — call it ≈210 µA floor as built (≈90 µA with the LED off). The bench cell is a 500 mAh PKCell (halve any 1000 mAh estimates): ≈100 days of pure sleep, and firmware must stop discharge at 3.0 V because the pack’s own protection lets it fall to 2.5 V. This is an estimate to verify at bring-up with a current meter, not a datasheet guarantee.

## 3. USB-C Input & Protection — Sheet 02_USB_C_Input

This sheet brings 5 V power and USB data onto the board safely. Every part here exists to protect something or to satisfy the USB-C specification.

### J1 — USB-C receptacle (TYPE-C-31-M-12, JLCPCB part C165948)

A 16-pin USB-C connector that carries power and USB 2.0 data only (no high-speed lanes — this board does not need them). The connector has two of every contact so the plug works in either flip orientation:

- VBUS pads (A4, B4, A9, B9) are all tied together — this is the incoming 5 V, net USB_VBUS.

- Data pads are tied in pairs at the connector: A6+B6 form D+ (data plus), A7+B7 form D− (data minus).

- CC1 and CC2 (Configuration Channel pins) each get their own 5.1 kΩ resistor to ground (R4, R3). These two resistors are how the board announces 'I am a power-consuming device, please give me 5 V.' One resistor per pin, never shared — sharing breaks orientation detection. Source: ST application note TA0357.

- SBU pins (sideband use): not connected — unused in USB 2.0 designs.

- GND pads (A1, B1, A12, B12): all tied directly to board ground — these carry the return current for VBUS and reference the data lines (fixed 2026-07-20; an early capture left them floating). Shield: connected directly to ground for this revision (standard practice for a small self-contained device).

### D1 — TVS diode on the power input (SMF5.0A, Goodwork, C2980403)

TVS = Transient Voltage Suppressor: a diode that does nothing at normal voltage but clamps hard when a fast voltage spike (static discharge, cable surge) arrives. D1 sits right at the connector across USB_VBUS to ground. Ratings: stands off 5 V, starts conducting at ≈6.4 V, clamps at ≈9.2 V. This satisfies the Espressif hardware-design-guideline recommendation for surge protection at the main power entrance.

### F1 — resettable fuse (PPTC, Littelfuse 1206L075/16WR, C371166)

PPTC = Polymeric Positive Temperature Coefficient device, commonly 'polyfuse.' It is a resettable fuse: too much current heats it, its resistance jumps, current stops; when it cools, it resets itself. F1 sits between USB_VBUS and +5V_PROT, so every milliamp the board uses passes through it.

- Hold current (passes forever without tripping): 0.75 A at 20 °C, derating to 0.65 A at 40 °C.

- Trip current (definitely cuts off): 1.5 A.

- Sized so the worst simultaneous load (≈465 mA: Wi-Fi peak plus battery charging) fits under the hold current even warm.

### U1 — USB data-line ESD protection (USBLC6-2SC6, ST, C7519)

ESD = Electrostatic Discharge, the static zap from a hand or a cable end. U1 is a purpose-built protection array for high-speed data lines: extremely low capacitance so it does not distort USB signals, but it clamps zaps on D+ and D− before they reach the ESP32-S3. It is a flow-through part: connector-side data enters pins 1 and 3, protected data exits pins 6 and 4, so the layout naturally passes the signals through the chip. Its VBUS pin (pin 5) connects to USB_VBUS with a local 100 nF capacitor (C1).

### R1, R2 — 22 Ω series resistors, and C3, C4 — reserved capacitors (DNP)

The Espressif design guidelines ask for series resistors on the USB data lines close to the chip (starting value 22–33 Ω) and reserved capacitor footprints to ground that are left unpopulated. DNP = Do Not Populate: the footprint is on the board, but no part is soldered at the factory. These give tuning options if USB signal quality ever needs adjustment, at zero cost if it does not.

Nets leaving this sheet: +5V_PROT (to power sheets), USB_DP and USB_DN (to the ESP32-S3 core sheet).

## 4. 3.3 V Regulator — Sheet 03_3V3_Power

This sheet turns the system supply node VSYS into the clean 3.3 V rail that everything intelligent runs on.

### U2 — low-dropout linear regulator (AP2112K-3.3, Diodes Inc., C51118, orderable code AP2112K-3.3TRG1)

LDO = Low-DropOut regulator: a linear regulator that makes a lower, steady voltage from a higher one by burning the difference off as heat, and that keeps regulating even when its input is only slightly above its output. Key numbers, all from its datasheet:

- Output: fixed 3.3 V. Guaranteed capable of at least 600 mA — a ceiling, not a constant output. The load draws what it draws; 600 mA is the most the regulator can supply while still holding 3.3 V.

- Dropout: ≈250 mV typical at heavy load. Meaning: input must stay above ≈3.55 V for a clean 3.3 V out.

- Enable pin (EN): has an internal 3 MΩ pull-down. Left unconnected, the regulator stays OFF. It is therefore tied directly to VIN so the regulator is always enabled. This tie is mandatory — a floating EN is a dead board.

- Protection built in: current limiting that folds back to ≈50 mA into a dead short, and thermal shutdown at ≈160 °C.

### Capacitors on this sheet

- C2 — 10 µF at +5V_PROT: the power-entrance bulk capacitor recommended by the Espressif guidelines. A local tank that steadies the 5 V side.

- C6 — 1 µF at the regulator input (VSYS). C7 — 1 µF at the regulator output. Both are the datasheet's specified stability capacitors.

### D2 — power LED (green, 0603) with R5 (10 kΩ, as built)

Lights whenever +3V3 is alive — on USB or on battery. At 10 kΩ it draws ≈120 µA — deliberately dim to protect the sleep budget; even so it is the largest single sleep-mode drain. Note for battery testing: D2 may be left unsoldered on boards used for battery-life measurements; ≈120 µA is large next to the ≈90 µA the rest of the board draws asleep.

### Behavior on battery — documented design decision

On battery power, VSYS equals the battery voltage (4.2 V full → 3.0 V empty). While the battery is above ≈3.6 V, the regulator holds a clean 3.3 V. Below that, the 3.3 V rail sags gracefully along with the battery; the ESP32-S3 keeps running (its supply range is 3.0–3.6 V) but Wi-Fi transmit margin shrinks near empty. This is accepted for Rev A: it is the same trade-off used by mainstream hobby boards of this class, the battery monitor reports the state, and the practical usable battery range is 4.2 V down to ≈3.5–3.6 V. A future revision may use a buck-boost converter (a switching regulator that holds 3.3 V across the whole battery range) if full-range operation is ever needed.

Thermal note: worst sustained dissipation in the regulator is about (4.6 V − 3.3 V) × 0.2 A ≈ 0.26 W. The layout gives U2 generous copper area as a heatsink (Section 9).

## 5. ESP32-S3 Core — Sheet 04_ESP32S3_Core

U3 is the ESP32-S3-WROOM-1-N8 (Espressif, C2913198): a module containing the ESP32-S3 dual-core processor, 8 MB of flash memory, the Wi-Fi/Bluetooth radio, the antenna, and the radio shielding — all pre-certified. Using the module instead of the bare chip removes the hardest parts of radio design from a first board. N8 decodes as: 8 MB quad-SPI flash, no PSRAM, −40 to +85 °C.

### Power and reset

- 3V3 (module pin 2): fed from +3V3 with C9 (22 µF bulk) and C10 (100 nF) placed at the pin. The module needs a supply able to deliver at least 0.5 A; its own worst peak is 355 mA during Wi-Fi transmit.

- EN (pin 3) is the chip-enable/reset input and must never float. It gets the standard reset network: R7 (10 kΩ) pull-up to +3V3, C8 (1 µF) to ground, and SW2 (RESET button) across the capacitor. The resistor-capacitor pair (an RC delay) holds the chip off for a few milliseconds while power stabilizes, exactly as the Espressif guidelines require.

- GND: module pins 1, 40, and the large exposed pad 41 all go to ground; the pad also pulls heat out of the module.

### Boot control and strapping pins

Strapping pins are pins the chip reads once, in the first instant after reset, to decide how to boot. Their state at that instant must be correct. The ESP32-S3's strapping pins are GPIO0, GPIO3, GPIO45, and GPIO46 (GPIO = General-Purpose Input/Output).

- GPIO0 (pin 27): 10 kΩ pull-up (R6) to +3V3 and SW1 (BOOT button) to ground. Held low during reset, it forces firmware-download mode. Per the guidelines: no large capacitor is allowed on this pin.

- GPIO3, GPIO45, GPIO46 (pins 15, 26, 24): left completely unconnected. Their internal defaults are correct; nothing may load them at boot.

- All other unused GPIO pins are left unconnected in this revision.

### USB connection

The ESP32-S3 has native USB: GPIO19 (pin 13) is USB D− and GPIO20 (pin 14) is USB D+. They connect to nets USB_DN and USB_DP from the USB sheet. Programming and the serial console run over this native USB — no separate USB-to-serial bridge chip exists on this board, and none is needed: the chip's built-in USB Serial/JTAG controller lets the flashing tool reset the chip into download mode in software. The BOOT and RESET buttons remain as the manual fallback for recovering from broken firmware.

### Complete pin map (every used module pin)

| Module pin | Pin name | Net | Role |
|---|---|---|---|
| 1, 40, 41 | GND / pad | GND | Ground and thermal pad. |
| 2 | 3V3 | +3V3 | Module power input (C9 22 µF + C10 100 nF at the pin).  |
| 3 | EN | EN | Reset network R7 + C8 + SW2. |
| 13 | IO19 | USB_DN | Native USB data minus. |
| 14 | IO20 | USB_DP | Native USB data plus. |
| 23 | IO21 | SENS_PWR_EN | Drives the soil-probe power switch Q1 (low = probe on). |
| 27 | IO0 | BOOT | Boot strap: R6 pull-up + SW1 to ground. TP10. |
| 31 | IO38 | SDA | I²C data to both sensors. |
| 32 | IO39 | SCL | I²C clock to both sensors. |
| 36 | RXD0 | RXD0 | UART fallback receive. TP12. |
| 37 | TXD0 | TXD0 | UART fallback transmit. TP11. |
| 38 | IO2 (ADC1_CH1) | BAT_SENSE | Battery voltage reading (half of VBAT). |
| 39 | IO1 (ADC1_CH0) | ADC_SOIL | Soil probe analog reading. |

> **As-built note:** I²C moved to IO38/IO39 during capture — earlier drafts of this document said
> IO4/IO5. Every other unused GPIO is left unconnected.

ADC = Analog-to-Digital Converter, the circuit that turns a voltage into a number the firmware can read. Both analog inputs sit on ADC1, the converter Espressif recommends, and both use attenuation setting 3, whose usable range is 0–2900 mV. Each ADC pin gets a 100 nF capacitor to ground at the pin (C14 for soil, C17 for battery) per the guidelines.

## 6. Environmental Sensors — Sheet 05_I2C_Sensors

I2C (Inter-Integrated Circuit) is a two-wire shared bus: one clock line (SCL), one data line (SDA). Many chips share the same two wires; each has an address. Both lines idle high through pull-up resistors, and chips only ever pull the lines low — which is why the pull-ups are required.

- R8, R9 — 4.7 kΩ pull-ups, one per line, from the bus to +3V3. One pair serves the whole bus; adding more pairs would over-strengthen the pull and is a common beginner error.

### U4 — BME280 (Bosch, C92489): temperature, humidity, pressure

- Address 0x76, set by wiring its SDO pin to ground. SDO must never float — a floating SDO makes the address undefined.

- CSB pin wired to VDDIO (the 3.3 V rail): this permanently locks the chip into I2C mode instead of SPI mode.

- Decoupling: 100 nF at VDD (C11) and 100 nF at VDDIO (C12), per the datasheet.

- Placement cautions from the datasheet: the metal lid has a small vent hole that must never be covered (it is how pressure and humidity reach the sensing element), the package pin numbering runs clockwise in top view (opposite of most chips — checked during footprint work), and the part should sit away from heat sources (the regulator, the module) so it reads air temperature, not board temperature.

### U5 — VEML7700-TT (Vishay, C1850416): ambient light

- Address 0x10, fixed in silicon — no address pin. No conflict with the BME280's 0x76, so both share the bus happily.

- The -TT suffix is the top-view package: the light-sensing window faces up. It needs a clear view of the room and should sit away from the board's own LEDs.

- Decoupling: 100 nF at VDD (C13). Supply range 2.5–3.6 V — the 3.3 V rail fits.

## 7. Soil Probe Input — Sheet 06_Soil_Probe_Input

The soil probe (DFRobot SEN0193) is an external wand that plugs into the board. It outputs an analog voltage that falls as soil moisture rises. It is bought separately and never assembled onto the board.

- Probe specs, from its datasheet: supply 3.3–5.5 V, output 0–3.0 V, current ≈5 mA, connector interface PH2.0-3P.

### J2 — probe connector (JST S3B-PH-K-S(LF)(SN), C157929)

A 3-pin side-entry header from the JST PH family (2.0 mm pitch). 'PH2.0-3P' on the probe side means exactly this family, 3 positions — the mating plug housing is JST PHR-3. The family is rated 2 A, four hundred times the probe's needs. Pin assignment on the board (as built, matching the metered probe / DFRobot Gravity order): pin 1 = probe output (ADC_SOIL), pin 2 = SOIL_PWR — power on the middle pin, pin 3 = GND. (The originally planned order would have reverse-powered the probe.)

- Build-time check #1: the cable shipped with the probe has a PH plug on the probe end, but its other end is often a DuPont-style connector meant for Arduino headers. If so, a PH-to-PH 3-wire cable (about one dollar) replaces it.

- Build-time check #2: before soldering anything, buzz out the actual cable with a multimeter to confirm which wire lands on which J2 pad. Probe cables have no guaranteed color standard.

### Q1 — soil-probe power switch (AO3401A, C15127) with R10 (100 kΩ)

A P-channel MOSFET used as a high-side switch. MOSFET = Metal-Oxide-Semiconductor Field-Effect Transistor — here, simply a voltage-controlled switch. 'High-side' means it switches the power wire, not the ground wire. Its three pins: source (connected to +3V3), drain (connected to SOIL_PWR, the probe's power pin), gate (the control input, driven by net SENS_PWR_EN from GPIO21).

- Gate pulled high to +3V3 through R10 (100 kΩ): the default state is OFF, including during boot before firmware runs.

- Firmware drives the gate LOW to turn the probe ON, waits a moment for the reading to settle, samples the ADC, then drives the gate high again.

- Why it exists: the probe draws ≈5 mA continuously — about 120 mAh per day, enough to kill a 1000 mAh battery in roughly a week on its own. Switched, the probe costs almost nothing.

### The soil input, as built — direct connection, 100 kΩ pull-down, and C14 (100 nF) [2:1 divider removed 2026-07]

As built, the probe's output pin drives net ADC_SOIL into GPIO1 directly. R11 (100 kΩ) sits from ADC_SOIL to ground and C14 (100 nF) sits at the ESP32-S3 pin. The originally planned 2:1 divider (two equal series resistors halving the input) was deleted after bench measurement — see below.

- Why the divider was removed: bench measurement showed the probe tops out at ≈2.2 V from a 3.3 V supply (raw ≈2900 counts fully dry, ≈1465 in water, 12 dB attenuation) — already inside the ADC's 0–2900 mV range, so the halving stage added error without adding safety. A 100 kΩ pull-down to ground keeps the pin from floating while the probe is switched off, and even an accidental 5 V probe supply (output ≤3.0 V) stays below the pin's 3.6 V absolute maximum.

- C14 sits at the ESP32-S3 pin and steadies the reading, per the Espressif ADC guidance.

- Calibration plan: the raw numbers for 'dry' and 'in water' were recorded on the breadboard through the same direct (no-divider) chain the PCB uses — ≈2900 dry, ≈1465 in water — and must be re-recorded on the assembled board at bring-up. Note: at a 3.3 V supply the probe's real output span sits lower than the headline 0–3.0 V (that figure is at 5 V supply); calibration absorbs this completely.

## 8. Battery, Charger & Power Path — Sheet 07_Battery_PowerPath

This sheet does three jobs: protects against a backwards battery, charges the battery from USB, and automatically selects USB or battery as the source that actually runs the board.

### The battery itself (bought separately)

- Type: single-cell lithium-polymer (LiPo), '1S'. Nominal 3.7 V; 4.2 V full; ≈3.0 V empty.

- MUST have a built-in protection circuit (over-discharge / over-current cutoff) — the board deliberately has no battery-protection chip of its own. Note the protection is a last resort (disconnects at ≈2.5 V / ≈4.33 V); day-to-day limits are enforced by the charger (4.20 V) and by FIRMWARE: stop transmitting below ≈3.5 V (regulator headroom rule) and shut down at 3.0 V (battery floor). See Addendum A.

- Terminated in a JST-PH 2-pin plug, matching J3. Capacity 500–1200 mAh; the bench pack is a PKCell 503035 500 mAh (its protection IC is an ABLIC S-8261 per the pack drawing).

- First-connect ritual: measure the plug polarity with a multimeter before plugging in. LiPo leads have no universal color/polarity standard. Q2 makes a mistake survivable; the ritual makes it a non-event.

### J3 — battery connector (JST S2B-PH-K-S(LF)(SN), C173752)

The 2-pin side-entry sibling of J2, same JST PH family. Pin 1 = VBAT_RAW (battery positive), pin 2 = GND.

### Q2 — reverse-polarity protection (AO3401A, C15127)

A P-channel MOSFET wired as a one-way gate on the battery's positive line: drain to VBAT_RAW (the connector), source to VBAT (the protected rail), gate tied to ground.

- Battery correct: the MOSFET's internal body diode first lets current through, which raises the source voltage; the gate is then several volts below the source, the switch turns fully on, and current flows with only milliohms of loss — in BOTH directions, so charging current passes through it too.

- Battery reversed: the body diode faces the wrong way and blocks, and the gate-to-source voltage never turns the switch on. Nothing downstream ever sees the reversed voltage.

### U6 — battery charger (MCP73831T-2ACI/OT, Microchip, C424093)

A single-chip linear charge controller for one LiPo cell. The -2ACI code is the 4.20 V full-charge version in the SOT-23-5 package. It runs the industry-standard charge sequence (gentle preconditioning, constant current, constant voltage, automatic stop) with no firmware involvement.

- Powered from +5V_PROT (C15, 4.7 µF at its input). It only operates when USB is present; with USB gone it is unpowered and its built-in reverse blocking stops the battery from leaking back into it.

- Charge current is set by one resistor: R13 = 10 kΩ on the PROG pin gives ≈100 mA (the formula is I = 1000 V ÷ R). PROG must never be left floating. 100 mA is a gentle, safe rate for any cell 500 mAh and up.

- Output to VBAT with C16 (4.7 µF).

- D3 — charge LED (0603) with R12 (470 Ω, as built; ≈6 mA), wired from +5V_PROT through the LED into the STAT pin: the chip pulls STAT low while charging (LED on) and releases it when full (LED off). With no battery connected STAT floats and the LED may flicker faintly — expected, harmless.

### The automatic power path — D4, Q3, R16

This is the circuit that answers 'how does the board know to switch to the battery?' with physics, not decisions. Three parts:

- D4 — Schottky diode (SS14, MDD, C2480; SMA package, 1 A / 40 V). A Schottky diode is a one-way valve for current with an unusually small toll (≈0.4 V). It sits between +5V_PROT and VSYS. When USB is present, 5 V flows through it and VSYS sits at ≈4.6 V.

- Q3 — the source-select switch (AO3401A, C15127): a P-channel MOSFET with drain on VBAT, source on VSYS, and gate wired to +5V_PROT. R16 (10 kΩ, as built — changed from 100 kΩ after the 2026-07-20 review) pulls the gate to ground fast enough for a clean hand-over; it costs ≈0.5 mA only while USB is present.

- USB present: the gate sits at 5 V while the source sits at 4.6 V. The gate is ABOVE the source, so the switch is off, and Q3's internal diode also faces away from the higher VSYS — the battery is fully disconnected from the load. The board runs on USB; the charger has the battery all to itself.

- USB removed: the board's load drains +5V_PROT until Q3's body diode catches VSYS about 0.65 V below the battery; from that instant only R16 discharges the gate, so R16's value sets the hand-over speed. At 10 kΩ (as built) the body-diode phase lasts ≈50–100 ms, which the VSYS-side capacitors (C5, 10 µF and C18, 1 µF) and the processor's brown-out margin ride through; Q3 then turns fully on and VSYS becomes battery voltage with almost no loss. Correction to the original text: the capacitors on +5V_PROT do NOT bridge the gap — they sit behind D4 and actually hold Q3's gate up, delaying the switch; the bridging is done by the VSYS capacitors and the body diode. Full walkthrough: docs/Engineering_Notes.md, section 6. No firmware, no decisions — just two voltages racing and a switch that responds to their difference.

### Battery voltage monitor — R14, R15 (100 kΩ + 100 kΩ, 1%), C17 (100 nF)

An always-on voltage divider from VBAT to ground; the midpoint, net BAT_SENSE, is exactly half the battery voltage and goes to GPIO2 (ADC channel ADC1_CH1). A full battery reads 2.1 V — inside the ADC's 0–2900 mV range. The divider's constant drain is ≈21 µA, accepted as part of the ≈210 µA sleep floor. Firmware converts the reading to a percentage using a small lithium-cell voltage table.

## 9. Mechanical & Layout Rules — Sheet 08_Mechanical

This sheet holds the non-electrical realities: board outline, mounting, the antenna's demands, and the layout rules the electrical sheets impose.

- Board: **4 layers** (signal / GND / GND / signal on JLCPCB's JLC04161H-7628 stackup), 1.6 mm thick, 1 oz outer copper, lead-free HASL finish (HASL = Hot Air Solder Leveling), green solder mask. Two unbroken ground planes on the inner layers; no signals on the inner layers.

- Mounting: four M3 holes, one per corner, per the project plan.

- Antenna: the module's antenna end must protrude past the board edge (preferred) or sit at the edge with copper cut away beside and beneath it, at least 15 mm from any enclosure wall. No copper, no traces, no silkscreen under the antenna zone on any layer. Dense ground stitching vias surround (but never enter) the keep-out.

- USB data pair: routed as a short, tightly-coupled pair over the unbroken inner ground plane, with no vias. On the 4-layer stackup the pair geometry (0.29 mm trace / 0.20 mm gap over the 0.21 mm prepreg) lands at ≈90 Ω differential without paying for controlled-impedance fabrication; length-matched to 0.42 mm. The board is ordered as plain 4-layer — the geometry is right, the fab tolerance is simply not guaranteed, which is the correct trade at USB full speed.

- Regulator U2 gets a generous copper pour on its tab/ground for heat spreading (worst case ≈0.26 W sustained).

- BME280 placed away from U2 and U3 (heat), lid vent hole kept exposed. VEML7700 placed with a clear sky view, away from D2/D3.

- The two ADC traces (ADC_SOIL, BAT_SENSE) routed short, away from the USB pair and the antenna.

- Fuse F1, TVS D1, and ESD chip U1 all placed immediately at the USB connector — protection parts protect nothing if the zap passes them by on the way in.

- Trace widths: power nets (USB_VBUS, +5V_PROT, VSYS, VBAT, +3V3) at least 0.5 mm; signals 0.2–0.25 mm; verified with the Saturn PCB Toolkit against IPC-2221 before layout is finalized.

## 10. Complete Bill of Materials (BOM)

BOM = Bill of Materials: the complete shopping list the assembler builds from. JLCPCB part numbers ('C' numbers) are the definitive identifiers — search these on jlcpcb.com/parts. All C-numbered parts below were verified in stock and assemblable during design. Passive values are final; their exact catalog numbers are chosen from JLCPCB's Basic library (their always-stocked core catalog) at BOM upload.

### Semiconductors and modules

| Ref | What it is | Exact part | JLC # | Library | Job on the board |
|-----|---|---|---|---|---|
| U1  | USB data-line ESD protection array | USBLC6-2SC6 (ST) | C7519 | Extended | Clamps static zaps on D+/D−. |
| U2  | 3.3 V low-dropout linear regulator (LDO) | AP2112K-3.3TRG1 | C51118 | Extended | Makes the +3V3 rail from VSYS. |
| U3  | Wi-Fi microcontroller module | ESP32-S3-WROOM-1-N8 | C2913198 | Extended | The brain: firmware, sensors, USB, Wi-Fi. **Standard-PCBA tier only.** |
| U4  | Temp / humidity / pressure sensor (I²C) | BME280 (Bosch) | C92489 | Extended | Environment readings, address 0x76. **Standard-PCBA tier only.** |
| U5  | Ambient light sensor (I²C) | VEML7700-TT (Vishay) | C1850416 | Extended | Light level, address 0x10. |
| U6  | 1-cell LiPo linear charge controller | MCP73831T-2ACI/OT | C424093 | Extended | Charges the battery at ≈100 mA from USB. |
| Q1  | P-channel MOSFET (switch) | AO3401A | C15127 | Basic | Soil-probe power switch (high side). |
| Q2  | P-channel MOSFET (switch) | AO3401A | C15127 | Basic | Battery reverse-polarity protection. |
| Q3  | P-channel MOSFET (switch) | AO3401A | C15127 | Basic | USB/battery source-select switch. |
| D1  | TVS surge-protection diode, 5 V | SMF5.0A | C2980403 | Extended | Clamps spikes on the USB power line. |
| D2  | LED, yellow-green, 0603 | KT-0603YG | C2289 | Extended | Power indicator on +3V3 (Vf 2.0–2.2 V — the right chemistry for a 3.3 V rail). |
| D3  | LED, red, 0603 | KT-0603R | C2286 | Basic | Charging indicator on the charger's STAT pin. |
| D4  | Schottky diode, 1 A / 40 V, SMA | SS14 (MDD) | C2480 | Basic | Feeds VSYS from USB. |

### Connectors, protection, switches

| Ref | What it is | Exact part | JLC # | Library | Job on the board |
|-----|---|---|---|---|---|
| J1  | USB-C receptacle, 16-pin, USB 2.0 | TYPE-C-31-M-12 | C165948 | Extended | Power in + programming/data. Small per-piece handling fee at JLC. |
| J2  | JST PH 3-pin side-entry header | S3B-PH-K-S(LF)(SN) | C157929 | Verify | Soil probe. Pin 1 = signal, pin 2 = power, pin 3 = GND — **buzz out the cable first.** |
| J3  | JST PH 2-pin side-entry header | S2B-PH-K-S(LF)(SN) | C173752 | Verify | Battery. Pin 1 = +. **Meter plug polarity before first connect.** |
| F1  | Resettable PPTC fuse, 0.75 A hold | 1206L075/16WR | C371166 | Verify | Current ceiling on the 5 V input. |
| SW1 | Tactile switch, SMD 5.1 × 5.1 mm | TS-1187A-B-A-B | C318884 | Basic | **BOOT** button. Project footprint, pads renumbered 1/1/2/2. |
| SW2 | Tactile switch, SMD 5.1 × 5.1 mm | TS-1187A-B-A-B | C318884 | Basic | **RESET** button. |

### Passive components (resistors and capacitors, 0603 unless noted)

| Ref | Value | JLC # | Purpose |
|-----|---|---|---|
| R1, R2 | 22 Ω | C23345 | USB data series resistors, placed near the module. |
| R3, R4 | 5.1 kΩ | C23186 | USB-C CC pull-downs — one per CC pin; announces the board as a 5 V sink. |
| R5 | 10 kΩ | C98220 | Power-LED (D2) current limit — ≈120 µA, deliberately dim. |
| R6 | 10 kΩ | C98220 | GPIO0 (boot) pull-up to +3V3. |
| R7 | 10 kΩ | C98220 | EN (reset) pull-up to +3V3. |
| R8, R9 | 4.7 kΩ | C23162 | I²C bus pull-ups, one pair for the whole bus. |
| R10 | 100 kΩ | C25803 | Q1 gate pull-up — soil probe stays OFF until firmware says otherwise. |
| R11 | 100 kΩ | C25803 | ADC_SOIL pull-down — holds the pin steady while the probe is unpowered. |
| R12 | 470 Ω | C23179 | Charge-LED (D3) current limit, ≈6 mA. |
| R13 | 10 kΩ | C98220 | Charger PROG resistor → ≈100 mA charge current. |
| R14, R15 | 100 kΩ 1% | C25803 | Battery-sense 2:1 divider to GPIO2. |
| R16 | 10 kΩ | C98220 | Q3 gate pull-down — makes the battery take over when USB leaves. 10 kΩ (was 100 kΩ) for a fast hand-over. |
| C1 | 100 nF | C14663 | U1 (ESD chip) VBUS-pin decoupling. |
| C2 | 10 µF, 25 V (0805) | C15850 | Power-entrance bulk on +5V_PROT. |
| C3, C4 | 100 nF — **DNP** | C14663 | Reserved USB tuning capacitors. Footprints only, not assembled. |
| C5 | 10 µF, 25 V (0805) | C15850 | VSYS bulk — half of what bridges the USB→battery hand-over. |
| C6 | 1 µF | C15849 | Regulator input stability capacitor (VSYS). |
| C7 | 1 µF | C15849 | Regulator output stability capacitor (+3V3). |
| C8 | 1 µF | C15849 | EN reset-delay capacitor. |
| C9 | 22 µF, 25 V (0805) | C45783 | Bulk at the module's 3V3 pin. |
| C10 | 100 nF | C14663 | Module bypass at the 3V3 pin. |
| C11, C12 | 100 nF | C14663 | BME280 VDD and VDDIO decoupling. |
| C13 | 100 nF | C14663 | VEML7700 decoupling. |
| C14 | 100 nF | C14663 | ADC filter at the soil input pin. |
| C15, C16 | 4.7 µF | C19666 | Charger input / output capacitors. |
| C17 | 100 nF | C14663 | ADC filter at the battery-sense pin. |
| C18 | 1 µF | C15849 | VSYS decoupling — the other half of the hand-over bridge. |

> Passive JLC numbers are the ones **actually consumed on the 2026-08-21 order**. Basic-tier staples
> cycle in and out of stock weekly — re-verify every line on the JLC matching page at order time.
> The 10 kΩ line moved from C25804 to **C98220** after a JLC pre-order failed on 2026-08-18.

### Not assembled — bought separately

- DFRobot SEN0193 capacitive soil probe (plugs into J2). Sold by DigiKey/DFRobot/Amazon. Not waterproof past its marked line.

- 1S protected LiPo battery, 3.7 V nominal, JST-PH plug, 1000 mAh class (plugs into J3). The cell used for Rev A bring-up is a 500 mAh PKCell LP503035, so halve any 1000 mAh runtime estimate.

- If the probe's included cable ends in a DuPont-style connector: one PH-to-PH 3-pin cable.

## 11. Test Points

TP = Test Point: a bare copper pad, labeled on the silkscreen, where a multimeter or oscilloscope probe lands. They cost nothing and make bring-up and debugging enormously faster.

| TP | Net | What I check there |
|----|-----|---|
| TP1  | +5V_PROT  | 5 V present after the fuse. |
| TP2  | VSYS | System node — watch the USB↔battery hand-over here. |
| TP3  | +3V3 | Regulator output alive and at 3.3 V. |
| TP4  | VBAT | Protected battery rail; charge-voltage check. |
| TP5  | BAT_SENSE | Half-battery voltage into the ADC. |
| TP6  | ADC_SOIL  | Soil-probe voltage at the ADC pin. |
| TP7  | GND | Meter/scope ground reference. |
| TP8  | GND | Second ground reference — scope probe spring, opposite corner. |
| TP9  | EN | Reset line high; reset-button action. |
| TP10 | BOOT | Boot strap state; boot-button action. |
| TP11 | TXD0 | UART fallback transmit (recovery flashing / logs). Through-hole. |
| TP12 | RXD0 | UART fallback receive. Through-hole. |

TP11, TP12 and the adjacent GND pad are through-hole — the UART recovery trio, so a header can be
soldered in if USB is ever bricked. All other test points are 1.5 mm bare pads.

> **As-built note:** earlier drafts of this document planned TP1–TP15, including probe points on the
> USB pair and the I²C lines. The board carries **TP1–TP12** as listed above; the USB and I²C test
> points were dropped to keep the pair short and the antenna keep-out clear. TP3, TP5 and TP9 sit
> inside the self-imposed 15 mm antenna ring — waived for Rev A with probe-lead discipline during
> RF-active tests (see `docs/PROJECT_STATUS.md`, *Waivers on record*).

## 12. Firmware Plan (summary)

- Wake on a timer (deep sleep between cycles). Deep sleep = the processor mostly off, only a tiny wake-up clock running.

- On wake: drive GPIO21 low → soil probe powers up; wait ≈200 ms to settle; read ADC_SOIL (average several samples); drive GPIO21 high → probe off.

- Read BME280 (temperature, humidity, pressure) and VEML7700 (light) over I2C.

- Read BAT_SENSE, double it, convert to percentage via a lithium voltage table.

- Join Wi-Fi, publish the readings (MQTT or HTTP), disconnect, return to deep sleep.

- Soil calibration constants (dry value, wet value) are compiled in from the breadboard measurements taken through the identical direct, no-divider chain (≈2900 dry / ≈1465 in water).

- Serial console and flashing over native USB; TXD0/RXD0 test points are the recovery path if firmware ever bricks USB.

## 13. Bring-Up Plan (first power, in order)

- 1. Visual inspection against the schematic: orientations of U3–U5, D2–D4, Q2–Q3, electrolytic-style markings, no bridges.

- 2. Meter checks, no power: no short between GND and +5V_PROT, VSYS, +3V3, VBAT.

- 3. USB in through a current-limited source if available. Check TP1 ≈5 V, TP2 ≈4.6 V, TP3 = 3.3 V. Power LED on.

- 4. Enumeration: the board appears as a USB serial device. Flash a blink/hello firmware.

- 5. I2C scan: devices found at 0x76 and 0x10.

- 6. Battery (polarity verified with a meter first!) into J3, USB still in: charge LED on, TP4 climbs toward 4.2 V, charge current ≈100 mA.

- 7. The hand-over test: board running, scope or meter on TP3 — unplug USB. The board must keep running; TP2 snaps to battery voltage; TP3 stays at 3.3 V.

- 8. Battery-only boot test: power up from battery alone.

- 9. Probe in J2 (after cable buzz-out): dry reading and water reading recorded; compare to breadboard constants.

- 10. Sleep-current measurement in series with the battery: expect ≈210 µA floor as built (≈90 µA with D2, the power LED, unsoldered).

- 11. Wi-Fi range sanity check and a 24-hour soak run.

## 14. Manufacturing & Assembly

- Fab + assembly at JLCPCB: **4-layer PCB, Standard PCBA**, top side only, SMT assembly plus through-hole service for the two JST connectors. SMT = Surface-Mount Technology (parts sit on the surface); THT = Through-Hole Technology (leads pass through the board). Standard tier is forced by two parts, not by choice: the ESP32-S3 module (C2913198) and the BME280 (C92489) are both Standard-only.

- Most ICs are 'Extended' catalog parts, each carrying a one-time feeder-loading fee; the AO3401A, SS14, and most passives come from the free 'Basic' library. **Actual Rev A run (5 boards):** setup $25.56 · stencil $8.21 · feeder loading $38.25 (13 Extended lines) · SMT $2.04 · hand-soldered J2/J3 $4.04 · X-ray on the module pad $8.20 · packaging $0.49 — PCBA $86.79, PCB $12.10, components $0.00 (all 27 unique parts consumed from a pre-stocked JLC Parts Library). See `fabrication/revA/ORDER_NOTES.md` §7.

- The USB-C connector carries a small per-piece special-handling fee at JLC — expected.

- If any part is ever out of stock at order time: JLCPCB's Global Sourcing / pre-order service buys the identical part from DigiKey, Mouser, Arrow, or Verical into the account's parts library for assembly — the design never changes. Consignment (shipping parts to JLC) is the further fallback.

- The soil probe and the battery are never part of the assembly order.

## 15. Known Limitations & Accepted Risks (stated openly)

- Regulator sag on a low battery: below ≈3.6 V battery, the 3.3 V rail follows the battery down. Accepted for Rev A; battery monitor reports it; buck-boost is the Rev B path if ever needed.

- Linear regulator heat: ≈0.26 W sustained worst case — handled with copper pour; verified at bring-up.

- Fuse derating: the 0.75 A hold falls to 0.65 A at 40 °C; margins were sized against the derated number.

- USB differential impedance: the pair is at the ≈90 Ω geometry over the inner ground plane, but the board is ordered as plain 4-layer, so the impedance is designed-for rather than fab-guaranteed. Correct trade at USB full speed; controlled-impedance fabrication is available if a future revision ever needs the guarantee.

- Probe output span at 3.3 V supply is smaller than the headline 0–3.0 V figure; the calibration procedure absorbs it.

- The probe is not waterproof past its marked line; the board itself is not weatherproof.

- Charge LED may flicker faintly with no battery connected (charger status pin floats) — cosmetic only.

- The board has no on-board battery-protection chip; the REQUIREMENT to use protected cells covers it.

## 16. Build-Time Checklist

*Status as of 2026-08-23. Rev A is ordered; the items below are what the build still owes.*

**Still open — for the bench, when the boards land:**

- [ ] Buzz out the soil-probe cable wire order before soldering / first use.
- [ ] Confirm the probe cable's board-end connector; buy a PH-to-PH cable if needed.
- [ ] Meter-check battery plug polarity before first connection. The charge LED does **not** prove polarity.
- [ ] Re-record the soil calibration constants (dry / in water) on the assembled board.

**Closed during design:**

- [x] Basic-library catalog numbers picked for every passive, LED and tactile switch — see the BOM tables in Section 10, and `fabrication/revA/BOM-ESP32S3_PlantMonitor.csv` for what was actually ordered.
- [x] SS14 Schottky datasheet added — `references/datasheets/DIODE_SS14_Schottky_1A40V_Family_Datasheet.pdf`.
- [x] SMF5.0A TVS datasheet added — `references/datasheets/TVS_MDD_SMF5_0A_5V_Unidirectional_Datasheet.pdf`.
- [x] Duplicate SEN0193 file consolidated — `references/datasheets/SENSOR_DFRobot_SEN0193_Capacitive_Soil_Moisture_Module_Web_Datasheet.pdf`.

## Addendum A — Renumbering & As-Built Record

This document was written before schematic capture. During capture and the 2026-07-20 design review
the board picked up KiCad's own reference designators, which did not match the planning-stage
designators used in the original draft. **On 2026-08-23 the body of this document was renumbered to
the as-built designators**, so the text, the schematic, the schematic PDF and the ordered BOM now
agree. This addendum keeps the record of what moved and what changed electrically.

### Designator renumbering applied to this document

| Planning draft | As built | Part |
|---|---|---|
| U1 | **U3** | ESP32-S3-WROOM-1 module |
| U2 | **U1** | USBLC6-2SC6 USB ESD array |
| U3 | **U2** | AP2112K-3.3 LDO |
| U4 | **U6** | MCP73831 charger |
| U5 | **U4** | BME280 |
| U6 | **U5** | VEML7700 |
| Q1 | **Q2** | Reverse-polarity guard |
| Q2 | **Q1** | Soil-probe power switch |
| Q3 | Q3 | Source-select switch |
| R1, R2 | **R4, R3** | USB-C CC pull-downs |
| R3, R4 | **R1, R2** | USB 22 Ω series |
| R5 | **R7** | EN pull-up |
| R6 | R6 | IO0 pull-up |
| R7, R8 | **R8, R9** | I²C pull-ups |
| R9, R10 | **deleted** | The removed soil 2:1 divider |
| — | **R11** | New: 100 kΩ ADC_SOIL pull-down that replaced the divider |
| R11 | **R13** | Charger PROG |
| R12 | R12 | Charge-LED limit, 470 Ω |
| R13 | **R5** | Power-LED limit, 10 kΩ |
| R14 | **R16** | Q3 gate pull-down, 10 kΩ |
| R15 | **R10** | Q1 gate pull-up |
| R16, R17 | **R14, R15** | Battery-sense divider |
| D1 | **D2** | Power LED |
| D2 | **D3** | Charge LED |
| D3 | **D1** | TVS |
| D4 | D4 | Power-path Schottky |
| SW1 | **SW2** | RESET button |
| SW2 | **SW1** | BOOT button |
| C1 | **C2** | +5V_PROT bulk |
| C2, C3 | **C6, C7** | Regulator in / out |
| C4 | **C9** | Module bulk |
| C5 | **C10** | Module bypass |
| C6 | **C8** | EN delay |
| C7, C8 | **C3, C4** | Reserved USB caps (DNP) |
| C9 | **C1** | ESD-chip VBUS decoupling |
| C10, C11 | **C11, C12** | BME280 decoupling |
| C12 | **C13** | VEML7700 decoupling |
| C13 | **C14** | Soil ADC filter |
| C14, C15 | **C15, C16** | Charger in / out |
| C16 | **C17** | Battery-sense ADC filter |
| — | **C5, C18** | New: 10 µF + 1 µF VSYS bulk (added after the review) |

The I²C pull-up pair (planning R7/R8 → as-built R8/R9) was missing from the original cross-map and
was recovered from the schematic netlist. Test points were re-derived the same way: the planning draft
listed TP1–TP15, the board carries TP1–TP12, and the mapping is in Section 11.

### Electrical changes made after the 2026-07-20 review

1. **Soil 2:1 divider removed.** The probe drives the ADC directly; R11 (100 kΩ) pulls the pin down and C14 (100 nF) filters it. Bench measurement showed the probe tops out at ≈2.2 V from a 3.3 V supply — already inside the ADC's 0–2900 mV window, so the halving stage added error without adding safety.
2. **J2 pin order** is signal / power / GND, matching the metered DFRobot probe. The originally planned order would have reverse-powered it.
3. **Power-LED resistor is 10 kΩ** (≈120 µA) — deliberately dim, to protect the sleep budget.
4. **Charge-LED resistor is 470 Ω** (≈6 mA).
5. **10 µF added on VSYS (C5).** The body text's original claim that the +5V_PROT capacitors bridge the hand-over was wrong and is corrected in Section 8: those capacitors sit behind D4 and actually hold Q3's gate *up*, delaying the switch. The bridging is done by the VSYS capacitors and Q3's body diode.
6. **Q3 gate pull-down is 10 kΩ**, changed from 100 kΩ, so the USB-unplug hand-over completes in ≈50–100 ms instead of ≈1 s — this is what prevents brown-out resets at mid battery.
7. **USB-C GND pins A1/B1/A12/B12** are explicitly tied to ground (an early capture left them floating).
8. **I²C moved to IO38/IO39** from the planned IO4/IO5.
9. **Board went from 2 layers to 4** (signal / GND / GND / signal, JLC04161H-7628). Sections 9, 14 and 15 are written to the 4-layer build.

### Firmware protection duties

Hardware only reports; firmware must act. Stop Wi-Fi transmission below ≈3.5 V battery (the AP2112K
needs ≈200 mV headroom at the 355 mA TX peak — a regulator rule); enter permanent deep sleep at
3.0 V (the PKCell floor — a battery rule). Deep sleep still draws ≈210 µA as built (≈90 µA with the
power LED removed): about 100 days from full to the pack protector's 2.5 V disconnect on the 500 mAh
bench cell. **Never store the board with a battery attached** — the pack cannot be recovered from 0 V.

### Companion documents

| Document | What it carries |
|---|---|
| [`PROJECT_STATUS.md`](PROJECT_STATUS.md) | The live hand-off: current state, waivers, standing facts |
| [`BringUp_Guide.md`](BringUp_Guide.md) | First-power procedure, expected voltages, probe points |
| [`PinMap_CheatSheet.md`](PinMap_CheatSheet.md) | GPIO / net / connector map, as built |
| [`Engineering_Notes.md`](Engineering_Notes.md) | Bench notes, battery-protection analysis, hand-over walkthrough |
| [`RevB_Upgrade_Plan.md`](RevB_Upgrade_Plan.md) | Ranked upgrades, integrated power path first |
| [`reviews/Design_Review_RevA_2026-07-20.md`](reviews/Design_Review_RevA_2026-07-20.md) | The full pre-fab review record this addendum came from |
| [`../fabrication/revA/ORDER_NOTES.md`](../fabrication/revA/ORDER_NOTES.md) | Every setting the board was ordered with, and the as-ordered cost record |

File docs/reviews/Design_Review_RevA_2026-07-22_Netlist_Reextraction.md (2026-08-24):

# Pre-Layout Design Review: Netlist Re-Extraction — ESP32-S3 Plant Monitor, Rev A

**Method:** the netlist was rebuilt from the `.kicad_sch` sources rather than read off the drawing, then every connection cross-checked against the datasheets in `references/`. Reviewing the parsed source instead of the schematic view is what makes this a second opinion rather than a second look.
**Date:** 2026-07-22
**Board:** ESP32S3_PlantMonitor Rev A · KiCad 10.0.2 · 2-layer at the time of review
> *Historical note: reviewed pre-layout, when the board was still planned as 2-layer. The move to 4 layers was decided 2026-08-06 and applied to the board file 2026-08-12 — reasoning in [`../KiCad_Settings_RevA.md`](../KiCad_Settings_RevA.md).*
**Files reviewed:** all 8 schematic sheets, the project file, the custom symbol/footprint library, the BOM, and the full design document + prior review.

---

## Bottom line

**This schematic is ready for PCB layout.** I did not find a single blocking or functional error. Every net I traced matches what the design intends, every part has a footprint, the power path works, and the design follows Espressif's official ESP32-S3 guidelines. I can confidently run **"Update PCB from Schematic" (F8)** and start placing parts.

The items below are *refinements, layout-time cautions, and things to double-check on the bench* — not reasons to stop. I've sorted them by how much they matter so it's clear at a glance that nothing is urgent.

Think of the verdict as: **green light, with a short pre-flight checklist.**

---

## How I checked this

Rather than just read the schematic pictures, I wrote a program that re-parsed the raw KiCad files and rebuilt the **netlist** from scratch — the list of which component pins are electrically joined into each "wire." A netlist is the real truth of a schematic; the pretty drawing can hide mistakes that the netlist exposes. I then:

- **Traced the whole power path by hand** — USB in → fuse → 5 V → charger, Schottky diode, and the two MOSFETs that hand power between USB and battery — and confirmed every diode and transistor is turned the right way around. (This is the part most likely to have a silent error, so I verified the orientation of all 4 diodes/LEDs and all 3 MOSFETs individually against their datasheets.)
- **Confirmed the ESP32-S3 pin map** matches my `PinMap_CheatSheet.md` exactly.
- **Checked every component has a footprint** (69/69) and that the transistor's schematic symbol matches the real AO3401A pin order (Gate-Source-Drain), so the MOSFETs will be correct on the copper, not just on paper.
- **Cross-checked the design against Espressif's ESP32-S3 Hardware Design Guidelines** for USB, reset, and boot pins.
- Read my design doc, BOM, engineering notes, and the 2026-07-20 review, and **verified that the fixes from that review are actually in the current files.**

---

## What's correct (the reassuring part)

Everything structural checks out. Verified from the re-extracted netlist:

**Power & protection**
- USB-C sink wiring is textbook: both CC pins get their own 5.1 kΩ resistor to ground (R3, R4 — one per pin, never shared), all four VBUS pads tied, and — importantly — **all four USB-C ground pins (A1/B1/A12/B12) plus the shield connect to ground.** (This was the big fix from the last review; it's confirmed present.)
- TVS (D1) and ESD array (U1) are oriented correctly and sit at the connector; the polyfuse (F1) carries the full board current with margin.
- The 3.3 V regulator (U2) has its enable tied to its input (so it's always on — a floating enable would be a dead board), and the correct input/output capacitors.
- **The automatic USB↔battery power path is wired correctly** — the Schottky D4 points the right way (5 V → system), the source-select MOSFET Q3 has source→VSYS, drain→VBAT, gate→+5 V with the 10 kΩ pull-down to ground, and the reverse-polarity MOSFET Q2 is oriented to block a backwards battery.
- The battery charger (U6, MCP73831) has the right program resistor for ≈100 mA and correct input/output caps.

**Brain & sensors**
- ESP32-S3 reset network (10 kΩ + 1 µF + RESET button) and boot strap (GPIO0 with 10 kΩ pull-up + BOOT button, **no capacitor** — exactly as Espressif requires) are both correct.
- Native USB goes to GPIO19/20 through the ESD chip and 22 Ω series resistors, with unpopulated tuning caps — this matches Espressif's recommended USB circuit precisely.
- I²C has **exactly one pull-up pair** (R8/R9, 4.7 kΩ) for the whole bus — the most common beginner mistake is adding extra pull-ups, and there are no extras here.
- BME280 address is locked to 0x76 (SDO→GND) and forced into I²C mode (CSB→3.3 V); VEML7700 is at its fixed 0x10. No address conflict.
- Both analog inputs (soil, battery-sense) have their 100 nF filter caps at the pin, and unused pins are properly marked no-connect.

**Housekeeping**
- All 69 components have footprints. 12 test points and 4 mounting holes are present. Power-flag symbols are placed on exactly the three rails that need them for the electrical-rules check to pass.

---

## Findings, by priority

| # | Priority | Item | Type |
|---|---|---|---|
| — | **Blocker** | *(none found)* | — |
| 1 | Watch at bring-up | USB→battery hand-over can dip close to brown-out **at low battery** | Verify on bench |
| 2 | Keep in mind | Reversed battery **while USB is plugged in** can trickle backwards | Accepted risk / procedure |
| 3 | Layout-critical | LDO needs a copper "heat-spreader" pour | Do during layout |
| 4 | Layout-critical | Double-check the 4-pad tactile-switch footprint mapping | Verify during layout |
| 5 | Optional (Rev B) | No ESD protection on the soil/battery connectors | Nice-to-have |
| 6 | Nitpick | Custom VEML7700 symbol uses generic pin types | Cosmetic/ERC hygiene |
| 7 | Process | Push the git commit; re-verify JLC stock at order time | Not a schematic issue |

Details below, in plain language.

### 1 — Watch the USB-unplug hand-over at low battery *(bench check, not a fix)*

When I pull the USB cable, the board has to hand power from the 5 V rail over to the battery. For a few tens of milliseconds during that switch, the system rail is fed through a "body diode" inside Q3, which drops it to roughly **(battery voltage − 0.65 V)**. Do the arithmetic:

- Full battery (4.2 V) → rail ≈ 3.55 V during the switch → fine.
- Nearly empty (3.6 V) → rail ≈ 2.95 V → this is right at the ESP32-S3's default brown-out reset threshold (~3.0 V).

So the *only* scenario with any risk is "unplug USB at the exact moment the battery is nearly flat." The previous review already improved this a lot by changing R16 from 100 kΩ to 10 kΩ (I confirmed it's 10 kΩ), which shortens the switch to ~50–100 ms so the bulk capacitors can ride through it. This is genuinely fine on paper — but hand-over timing depends on real capacitor and transistor behavior, so **put a scope on the VSYS test point (TP2) and unplug USB at a low battery voltage during bring-up** (my bring-up guide already lists this as step 7 — just pay special attention to the low-battery case). If I ever see a reset, the firmware can briefly relax the brown-out detector during the transition.

### 2 — Reversed battery + USB = slow reverse trickle *(known, accepted)*

My reverse-polarity MOSFET (Q2) protects the board when running on battery. But there's a subtle corner the last review already flagged and accepted: if someone plugs the battery in **backwards** *and* USB is also connected, the charger can push a small current that turns Q2 on into the reversed cell. It's a slow trickle (not a bang), the board itself is unharmed, and the charge LED will misleadingly look "normal."

There's no cheap fix in this exact topology, so the mitigation is procedural and it's the right call for Rev A: **always meter the battery plug's polarity before the first connection**, and remember that *the charge LED lighting does NOT confirm correct polarity.* My bring-up guide already says this. If I want it gone in Rev B, that's what an integrated power-path/charger IC (e.g. MCP73871, BQ24075) or a dedicated protection FET solves. I'd keep it as-is for this spin.

### 3 — Give the regulator a copper heat-spreader *(do at layout)*

The 3.3 V regulator (U2) is a small SOT-23-5 part. In the worst case (USB power + Wi-Fi running hard) it burns off about **0.26 W as heat**. That's fine *if* it can shed heat into the board. During layout, pour a generous copper area connected to its ground pin/tab on both layers with a few stitching vias. My design doc already plans this — it's a real requirement, not optional, and worth a thermocouple check at bring-up during a long Wi-Fi session.

### 4 — Re-verify the tactile-switch footprint *(do at layout)*

My two buttons (SW1 = BOOT, SW2 = RESET) use a **custom 4-pad footprint** from my project library. Physical tactile switches have 4 pins that are internally two pairs; the footprint pads were renumbered to 1/1/2/2 to match the 2-pin schematic symbol. The netlist is correct (SW1 connects GPIO0↔ground, SW2 connects EN↔ground), but **4-pad switch footprints are a classic source of "it's mirrored/rotated wrong" mistakes.** My BOM says this was verified against the datasheet's A-B / C-D pairing — just give it one more look in the footprint editor and on the placed part, since it's cheap insurance and hard to fix after fab.

*(Side note: the schematic, BOM, and pin-map all agree SW1 = BOOT and SW2 = RESET. The main design document's body text has these two swapped — the schematic is the correct source of truth, so just make sure the silkscreen labels follow the schematic, which they will automatically.)*

### 5 — Consider ESD protection on the external connectors *(optional, Rev B)*

The soil probe (J2) and battery (J3) plug in with external wires that a person will touch. Right now the soil signal line has only its filter cap and pull-down; there's no ESD clamp on J2 or J3. For a device that sits by a plant and gets handled, a small TVS/ESD diode on the ADC_SOIL line (and optionally the battery line) would make it more rugged. It's genuinely optional — plenty of hobby boards ship without it — and it's already on my Rev B list, so I'd leave Rev A alone unless I have board space to spare.

### 6 — Custom VEML7700 symbol pin types *(cosmetic)*

In my custom `PlantMonitor_JLC` library, the VEML7700 symbol's power pins (VDD, GND) are typed as generic "input/passive" rather than "power." Everything connects correctly, so this changes nothing electrically — but it means KiCad's electrical-rules-check won't actively watch those pins as power pins. Purely a library-hygiene nitpick; fix it whenever I next touch that symbol, or ignore it.

### 7 — Process items (not schematic problems)

From my own notes, these are still open and worth closing before I order:

- **Push the git commit.** My `PROJECT_STATUS.md` notes the last milestone commit was made in an environment with no network, so `git push` still needs to run from a normal terminal. My work isn't backed up until I do.
- **Re-verify JLCPCB stock and Basic/Extended status at upload.** Stock is a live value; the BOM even notes the 10 kΩ (C25804) hit zero stock once and lists an alternate. Re-check every line at order time.
- **The usual build-time rituals** I've already documented: buzz out the soil-probe cable wire order before soldering, and meter the battery plug polarity before first connection.

---

## Layout-phase checklist (my next stage)

Since the schematic is done, here's what actually matters when I place and route — most of it is already in my design doc's Section 9; this is the short version:

1. **Protection parts first, right at the USB-C connector:** fuse F1, TVS D1, ESD chip U1. They only work if the surge hits them *before* reaching anything else.
2. **USB data pair (D+/D-):** keep the two traces short, side-by-side, and over a solid unbroken ground area with no vias between them. A 2-layer board can't hit the textbook USB impedance — "short and clean" is the accepted compensation, and full-speed USB tolerates it well.
3. **Regulator U2:** the copper heat pour from finding #3.
4. **Antenna:** the module's antenna end must overhang the board edge (or have all copper cut away under and beside it), kept ≥15 mm from any enclosure wall, with no copper/traces/silkscreen underneath on either layer.
5. **Sensor placement:** BME280 away from the regulator and the module (so it reads air temperature, not board heat) with its vent hole unobstructed; VEML7700 with a clear view up and away from the two LEDs.
6. **Analog traces (ADC_SOIL, BAT_SENSE):** keep them short and away from the USB pair and the antenna.
7. **Trace widths:** power nets (VBUS, +5V_PROT, VSYS, VBAT, +3V3) ≥0.5 mm; signals ~0.2–0.25 mm.
8. **Run DRC** (design-rule check) with JLCPCB's 2-layer capabilities set, and re-run **ERC** one final time after any last schematic tweak.

---

## Accepted trade-offs (fine for Rev A — just know they're there)

These are deliberate, documented choices, not mistakes:

- **On battery, the 3.3 V rail follows the battery down once it drops below ~3.6 V.** Firmware stops Wi-Fi transmit at 3.5 V and sleeps at 3.0 V to manage it. A buck-boost regulator would fix it in Rev B if I ever need the full battery range.
- **The power LED is the biggest sleep-mode drain** (~120 µA). It's deliberately dim; leave it unpopulated on any board I use to measure true sleep current.
- **I must use a *protected* lithium cell** — the board has no on-board battery-protection chip by design. This is stated as a hard requirement, which covers it.
- **Charge LED may flicker faintly with no battery connected** — cosmetic, harmless.

---

## Summary

| Question | Answer |
|---|---|
| Any electrical errors? | **No** |
| Any missing footprints? | **No** (69/69 assigned) |
| Power path correct? | **Yes** — traced and verified pin-by-pin |
| Matches Espressif guidelines? | **Yes** (USB, reset, boot pins all conform) |
| Prior review's fixes present? | **Yes** — all confirmed in the current files |
| **Ready for PCB layout?** | **Yes — go.** |

Rev A closes with no blocking or functional findings. Run F8 and start placing parts — and keep the bring-up guide handy, because the two things worth watching (the low-battery hand-over and the reverse-battery procedure) are behaviors to confirm with a meter, not schematic changes.

---

*Sources: Espressif ESP32-S3 Hardware Design Guidelines & Schematic Checklist (docs.espressif.com). Findings verified against the project's own datasheets (AO3401A, MCP73831, AP2112K, USBLC6-2SC6, BME280, VEML7700) and the as-built KiCad netlist.*

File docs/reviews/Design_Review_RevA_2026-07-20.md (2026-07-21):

# Pre-Fabrication Design Review — ESP32-S3 Plant Monitor Rev A
**Date:** 2026-07-20 · **Updated:** same day, after my 16:07 save (battery-sense verified) and BOM regeneration. · **Scope:** full schematic, netlist-level, against all datasheets in `references/`, the Final Design Document, Espressif hardware design guidelines, and the Zak Kemble load-sharing reference topology. The deleted "Rev A.2" reference PDF is **not** used as evidence anywhere in this report; all findings trace to the parsed `.kicad_sch` files, my screenshots, and the datasheets.

**Method.** I did not review from the screenshots alone. I parsed the actual `.kicad_sch` s-expression sources into a pin-level netlist (symbol transforms validated against wire/junction geometry three independent ways), and cross-checked every claim against the PDFs in `references/`. Reference designators below are the **current-schematic** ones (my screenshots); the doc↔schematic cross-map is in §8.

---

## VERDICT (summary — details and ranked list below)

**The circuit as drawn in my screenshots is electrically sound and will work** — power-up, charge, battery operation, sensors, and native-USB programming are all correctly wired, **except**:

1. ~~BLOCKING — USB-C GND pins no-connected~~ → **RESOLVED 2026-07-20 16:29.** Re-parsed after my fix: A1/B1/A12/B12 now net to GND; the only remaining no-connects on the sheet are SBU1/SBU2 (correct).
2. ~~BLOCKING (process) — saved files missing the battery-sense chain~~ → **RESOLVED 2026-07-20 16:07.** I re-parsed my save: IO2 → `BAT_SENSE` on sheet 04, and `VBAT` → R14 100 k 1 % → `BAT_SENSE` (R15 100 k 1 % → GND, C17 100 nF at the pin) on sheet 07; labels merge across sheets. Battery monitoring is correct in the saved files. Remaining step: commit to git (the last commit still lacks it).
3. ~~BLOCKING (for assembly) — BOM stale~~ → **RESOLVED 2026-07-20.** `references/ESP32S3_PlantMonitor_RevA_BOM.xlsx` was regenerated from the saved schematic (designators now match the schematic; 51 placed + 2 DNP = 53 footprints). Re-verify JLC stock/Basic-Extended status at upload.
4. ~~RISKY — USB-unplug hand-over brown-out~~ → **RESOLVED 2026-07-20 18:52.** R16 verified changed to 10 k in the saved schematic; BOM updated to match. Residual behavior to confirm at bring-up: a brief (~50–100 ms) dip to VBAT−0.65 V on VSYS during unplug — pass criteria and procedure are in `docs/BringUp_Guide.md`. Integrated power-path options are documented in `docs/RevB_Upgrade_Plan.md`.

Remaining before layout: add test points (or accept the pad-level probe points listed in the bring-up guide), commit.

---

## 1. File & folder audit (everything in the folder)

| File | Status |
|---|---|
| `ESP32S3_PlantMonitor/*.kicad_sch` (re-saved 2026-07-20, latest 16:29) | **Verified after my saves:** BAT_SENSE subcircuit present and correctly netted; USB-C GND pins now grounded (fix verified 16:29); refs match my screenshots (R12=470 LED, R13=10 k PROG, R14/R15 divider, R16 rail pull-down, U6 charger). R16 still 100 k (Risky #4 — decision pending). |
| `ESP32S3_PlantMonitor/.history/*.kicad_sch` | Autosave snapshots; now match the saved files. No further action. |
| Git working tree | Dirty — every sheet modified vs. last commit (`a520f59 starting last stages`); the last *commit* still lacks BAT_SENSE. **Action: commit the saved state (ideally after fixing Blocking #1 and R16).** |
| ~~`ESP32S3_PlantMonitor_RevA2_Schematic (1).pdf`~~ | I deleted it; I'd already flagged it as unreliable. **No finding in this review depends on it** — everything was re-derived from the `.kicad_sch` sources, my screenshots, and the datasheets. |
| `ESP32S3_PlantMonitor.kicad_pcb` | 79-byte stub — layout not started (fine; this review is pre-layout). |
| `08_Mechanical.kicad_sch` | **Empty.** Doc §9 promises 4× M3 mounting holes here. Add before layout. |
| `references/ESP32S3_PlantMonitor_RevA_BOM.xlsx` | **Regenerated 2026-07-20 from the saved schematic** (this review): schematic designators, corrected values (10 k power-LED, 470 charge-LED, no soil divider, 3×100 k + 2×100 k 1 %), working summary formulas, carried-over JLC part numbers, notes flagging the J1-GND and R16 open items. Original backed up in session scratch. |
| Bring-up checklist + pin-map PDFs | **Superseded 2026-07-20** by `docs/BringUp_Guide.md` and `docs/PinMap_CheatSheet.md` (both PDFs were stale: TP references, deleted soil divider). Safe to delete the PDFs. |
| Design doc | **Updated 2026-07-20** (`references/` copy): soil section rewritten to as-built, LED resistors, R14→10 k, hand-over explanation corrected, USB GND bullet, 500 mAh cell + firmware duties, BOM-table rows fixed, plus "Addendum A — As-Built Updates" with the doc↔schematic refdes map. The duplicate in the project root is now outdated — delete it. |
| Datasheets | All present and correct for the chosen parts, two housekeeping notes: `ss14.pdf` is a generic "SS12–SS1200" family sheet (not MDD-branded) and still has its unrenamed filename (doc §16 open item); the TVS sheet is MDD-named for a Goodwork part (doc §16 asks for the Goodwork doc). |
| **IPC-2221** | **Not in the folder** (I'd noted it should be there). Only relevant at layout (trace widths), but re-add it. |
| `libs/` | VEML7700 symbol/footprint/3D present; footprint-vs-symbol pin mapping should be spot-checked at layout (BME280's clockwise pin numbering is called out in the doc — good). |

---

## 2. Block-by-block, net-by-net findings

### Sheet 02 — USB-C input & protection
Verified correct against J1 (16-pin C165948), USBLC6-2SC6, SMF5.0A, 1206L075/16WR datasheets:

* VBUS: all four pads (A4/B4/A9/B9) tied → `USB_VBUS`; C1 100 n at connector; D1 TVS **cathode to VBUS, anode to GND** (correct clamp direction; verified from symbol transform math, not the picture); F1 in series → `+5V_PROT` with C2 10 µF after the fuse. Matches Espressif guideline "ESD diode + ≥10 µF at main power entrance."
* CC1→R4 5.1 k→GND, CC2→R3 5.1 k→GND — one resistor per pin, correct UFP advertisement, never shared. ✔
* Data path has **no polarity swap**: J1 D− (A7+B7) → U1 pin 1 (I/O1) ⇒ pin 6 → R1 22 Ω → `USB_DN` → IO19 (USB_D−); J1 D+ (A6+B6) → U1 pin 3 ⇒ pin 4 → R2 22 Ω → `USB_DP` → IO20 (USB_D+). USBLC6 used flow-through exactly per ST datasheet; VBUS pin 5 powered, GND pin 2 grounded. C3/C4 100 n correctly DNP. ✔
* SBU1/SBU2 NC ✔. Shield → GND directly ✔ (doc-sanctioned for Rev A).
* **✘ BLOCKING — FIXED 2026-07-20 16:29 (verified: all four pins now net to GND).** Original finding, kept for the record: J1's GND pins A1/B1/A12/B12 carried an explicit no-connect flag and touched no copper (visible as the ✕ on the stacked GND pin in my own screenshot; confirmed in the parsed netlist of the 16:07 save). These four pins are where the cable's ground *conductor* lands — they are the DC return for every milliamp of VBUS current and the reference for D+/D−. The shield (SH) is a separate EMI screen bonded to the connector shells; the USB spec treats shield and GND as distinct networks, shell bonding quality varies wildly between cables, and returning supply current through the braid is out of spec even when it happens to work. Consequences range from "works with cable A, dead with cable B" to flaky enumeration to a defeated ESD strategy (USBLC6 clamps into a ground the cable ground never reaches). ERC is clean because the explicit NC flag tells it this is intentional. **Fix: delete the NC marker, wire the stacked GND pin to GND (one wire grounds all four pads — KiCad stacks them).**
* Minor: D1's schematic value is generic `D_Zener` and F1's is `Fuse` — set them to `SMF5.0A` and `1206L075/16WR 0.75A` so BOM export can't pick the wrong part. Minor: TVS sits before the fuse — perfect for ESD (its job), but a sustained-overvoltage event cooks it with no fuse protection; moving it after F1 is slightly more robust (optional). Minor: with D4 conducting at plug-in, VBUS sees ≈25 µF of downstream ceramic (USB spec inrush guidance is 10 µF); the polyfuse and Schottky soften this — accepted practice at this board class.

### Sheet 03 — 3.3 V regulator
Verified against AP2112K-3.3 datasheet:

* VSYS → C5 10 µF + C6 1 µF → VIN; EN tied to VIN (mandatory — internal 3 MΩ pull-down otherwise holds it off ✔); VOUT → C7 1 µF → `+3V3`. Datasheet requires 1 µF/1 µF ceramic minimum — met, plus the added 10 µF VSYS bulk (my intentional change #4 — present and correct). ✔
* 600 mA min guaranteed ≥ Espressif's 500 mA supply requirement ✔. Dropout (3.3 V grade): 250 mV typ / 400 mV max at 600 mA ⇒ ~150/240 mV at the 355 mA Wi-Fi peak. Iq 55 µA typ.
* Power LED: `+3V3` → R5 10 k → D2 (anode→cathode) → GND. Direction correct. **I = (3.3−2.1)/10 k ≈ 120 µA.** It will stay green (color doesn't shift with current) but on many 0603 greens 120 µA is *barely* visible in daylight — bench-check one before committing; 2.2 k (~550 µA) is a middle ground. Also note 120 µA is now the **largest single sleep-mode drain** (see §5) — the doc's "unsolder D1 for battery tests" advice still applies.
* Thermal (linear, worst sustained USB case): (4.6−3.3) V × 0.2 A ≈ 0.26 W → ~65–90 °C rise in SOT-23-5. Survivable, has thermal shutdown, doc's copper-pour mitigation stands — keep it. Sustained OTA/Wi-Fi at peak on USB is the case to watch at bring-up.

### Sheet 04 — ESP32-S3 core
Verified against WROOM-1 datasheet v1.8 and the 2026-06-23 hardware design guidelines:

* EN: R7 10 k pull-up + C8 1 µF + SW2 (reset) — exactly the guideline RC (10 k/1 µF, ~10 ms) ✔. IO0: R6 10 k pull-up + SW1 (boot) to GND, no capacitor on the strap ✔.
* 3V3 pin: C9 22 µF + C10 100 n at the pin ✔ (≥ guideline 10 µF + 0.1 µF; adding a parallel 1 µF is optional polish).
* GND pins 1, 40, EPAD 41 all grounded ✔.
* Straps: IO3, IO45, IO46 no-connected per guidelines/doc ✔ (IO45 floating ⇒ VDD_SPI = 3.3 V, correct for the N8 module). IO35/36/37 NC'd with a "PSRAM" note — on the **N8 (no PSRAM)** these pins are actually free, so the annotation is misleading but harmless; NC is fine.
* Periphered pins: IO4=`SCL`, IO5=`SDA`, IO1 (ADC1_CH0)=`ADC_SOIL`, IO2 (ADC1_CH1)=`BAT_SENSE` *(current version)*, IO21=`SENS_PWR_EN`, IO19/20=`USB_DN`/`USB_DP` — all match the doc's pin plan; both analog inputs are on **ADC1** ✔ (ADC2 is Wi-Fi-unusable, correctly avoided).
* TXD0/RXD0 no-connected. The doc promises TP12/TP13 pads as the UART recovery path — see Risky #3 (no test points exist).
* ✘ In the **saved** file only: IO2 is no-connected (the missing-divider problem, Blocking #2).

### Sheet 05 — I2C sensors
Verified against BME280 rev 1.24 and VEML7700 rev 1.8 datasheets:

* One pull-up pair for the whole bus: R8 (SCL) + R9 (SDA) 4.7 k to +3V3 ✔ (0.7 mA per line when low; fine to 400 kHz with usual bus capacitance).
* BME280 (U4): VDD (8) and VDDIO (6) → +3V3 with **two** 100 n caps (C12, C11) per datasheet ✔; GND 1/7 ✔; **SDO (5) → GND ⇒ address 0x76** ✔ (datasheet: 111011**0**); **CSB (2) → +3V3 ⇒ I2C mode locked** ✔; SCK (4) → SCL, SDI (3) → SDA ✔.
* VEML7700 (U5): pinout 1=SCL, 2=VDD, 3=GND, 4=SDA per datasheet — wired exactly so ✔; C13 100 n at VDD ✔; address fixed 0x10 ✔ (no conflict with 0x76); VDD 2.5–3.6 V range fits 3.3 V ✔.
* Layout reminders from the datasheets (doc already has them): BME vent hole exposed, clockwise pin numbering, away from heat; VEML clear sky view, away from LEDs.

### Sheet 06 — Soil probe input
Verified against SEN0193 web datasheet and AO3401A datasheet:

* Q1 high-side switch: **S(2) → +3V3, D(3) → `SOIL_PWR` → J2.2, G(1) → `SENS_PWR_EN` with R10 100 k gate-to-source pull-up.** Default off (boot, deep sleep — GPIO floats, R10 holds Vgs=0) ✔; GPIO21 low ⇒ Vgs = −3.3 V ⇒ Rds(on) ≈ 70 mΩ at −2.5…−4.5 V spec ⇒ µV-level drop at the probe's 5 mA ✔. Body diode points load→rail, never forward ✔.
* J2 order (my intentional change #2): pin 1 = `ADC_SOIL`, pin 2 = `SOIL_PWR` (**power on the middle pin**), pin 3 = GND. This matches the DFRobot Gravity analog convention (signal / VCC / GND) and my metered probe. The doc's original order (power/GND/signal) would indeed have reverse-powered the probe — the change is right. Cable buzz-out before first use stays mandatory (probe cables have no color standard — doc §16 ✔).
* ADC net: R11 100 k pull-down (added, correct — pin can't float with probe off) + C14 100 n filter at the pin (guideline: 0.1 µF at ADC pins ✔).
* Range check (guideline: ATTEN=3 effective range **0–2900 mV**, ±50 mV): probe outputs ≤3.0 V at a 5 V supply and **~2.2 V max at 3.3 V supply (my bench value — plausible against the datasheet's 0–3.0 V @5 V spec)** ⇒ inside range with ~0.7 V margin ✔. Even the "accidental 5 V" case (3.0 V) is below the 3.6 V pin abs-max — reading saturates but nothing is damaged. Removing the doc's 2:1 divider is sound *given my measurement*; re-verify max (dry, in air) at bring-up before trusting calibration.

### Sheet 07 — Battery, charger & power path
Verified against MCP73831 DS20001984H, AO3401A, SS14-family, PKCell 503035 datasheets. **This sheet is correct** — including all four things I flagged as visually unverifiable:

1. **D4 polarity: anode on `+5V_PROT`, cathode on `VSYS`** — current flows USB → VSYS. Confirmed from the parsed geometry (symbol at 215.9/76.2, rot 90; pin-map validated against three other diodes whose orientation is functionally provable). ✔
2. **Q3 gate connects to the `+5V_PROT` net itself** — a dedicated vertical wire at x=207.01 up to the rail junction, *not* through D4 and not a stray local net. R16 100 k pulls that same net to GND. ✔ (but see Risky #1 — the rail's 14.7 µF makes this pull-down slow).
3. **Charger pins, all five:** VDD(4) → +5V_PROT with C15 4.7 µF ✔ (datasheet-recommended value); VSS(2) → GND ✔; VBAT(3) → `VBAT` with C16 4.7 µF ✔; PROG(5) → R13 10 k → GND ✔; STAT(1) ← D3 cathode, D3 anode ← R12 470 Ω ← +5V_PROT ✔ (STAT sinks low while charging ⇒ LED on; tri-states with no battery ⇒ faint flicker, doc-documented).
4. **`BAT_SENSE` spelling is identical on sheets 04 and 07** (in the current/.history version) and the nets merge. ✔ — but it exists **only** there, not in the saved files (Blocking #2).

Other verifications on this sheet:

* **Charger variant/settings:** `MCP73831-2` = 4.20 V regulation (datasheet: 4.168–4.232 V) — correct for the PKCell pack (its PCM overcharge trip sits above 4.2 V; a −3/−4 variant would fight it). PROG 10 k ⇒ I = 1000 V/10 k = **100 mA (datasheet band 90–110)** = 0.2 C for the 500 mAh cell = exactly the pack's *standard charge* rate ✔. Precondition 10 mA below VPTH = 66.5 %·VREG ≈ 2.79 V ✔. Termination ≈7.5 mA vs. pack's 5 mA cut-off spec — terminates slightly early; safe direction ✔. VDD range 3.75–6 V ✔. Charger thermals: ≈0.2 W worst (CC into a 3.0 V cell) → ~+45 °C in SOT-23-5, fine.
* **Q2 reverse protection:** G(1)→GND, S(2)→`VBAT`, D(3)→`VBAT_RAW`(J3.1). Correct topology: correct battery ⇒ body diode conducts first, source rises, Vgs ≈ −VBAT ⇒ fully on (charging current passes backwards through the channel fine); reversed battery ⇒ body diode blocks, Vgs = 0 ⇒ off. Vds worst −8.4 V ≪ −30 V rating; Vgs −4.2 V ≪ ±12 V ✔. **Caveat: protection holds only with USB absent — see Risky #2.**
* **Battery divider:** `VBAT` → R14 100 k 1% → `BAT_SENSE` (→ R15 100 k 1% → GND, C17 100 n at pin). Half of VBAT: 2.10 V full / 1.50 V empty — inside 0–2900 mV ✔; 21 µA constant drain ✔ (doc-accepted); divider correctly taps **VBAT (post-Q2)**, so a reversed battery can't drive the ADC pin negative ✔. 50 k source impedance is fine with the 100 n reservoir cap ✔.
* **J3:** pin 1 = `VBAT_RAW` (+), pin 2 = GND, per doc convention. **The schematic cannot verify my physical pack's plug polarity — the mandatory meter check before first insertion stands** (and see Risky #2 for why it matters even more with USB attached). I could not find the literal "reverse the plug" wording in the PKCell PDF's text layer (it may be in a drawing); the datasheet does confirm 4.2 V charge, 0.2 C standard rate, 3.0 V discharge end, PCM present.
* C18 1 µF on VSYS + C5/C6 on sheet 03 give VSYS ≈ 12.6 µF total bulk ✔ (my intentional change #4 — present; and see §4 for why the *doc's* idea that the +5V_PROT cap bridges hand-over is wrong).

---

## 3. MOSFET proofs (pin-by-pin, per AO3401A datasheet: 1=G, 2=S, 3=D; Vgs(th) −0.5/−0.9/−1.3 V min/typ/max; body diode anode=drain, cathode=source)

**Q3 (source-select):** D=VBAT, S=VSYS, G=+5V_PROT.
| State | V(G) | V(S) | Vgs | Result |
|---|---|---|---|---|
| USB present | 5.0 | ≈4.6 | **+0.4 V** | Off ✔. Body diode: VBAT(≤4.2) at anode < VSYS(4.6) at cathode ⇒ reverse-biased ⇒ **battery fully isolated, no body-diode sneak path** ✔. Charge terminates cleanly (load never loads the charger) ✔ |
| Battery only | ≈0 (via R16) | ≈VBAT | **−3.0…−4.2 V** | Fully enhanced (≪ −1.3 V worst-case threshold) ✔, Rds ≈ 40–60 mΩ ⇒ <25 mV drop at Wi-Fi peak ✔ |
| Hand-over instant | decaying | VBAT−0.65 | crosses −Vth **late** | see Risky #1 |

**Q2 (reverse guard):** D=VBAT_RAW, S=VBAT, G=GND.
| State | Vgs | Result |
|---|---|---|
| Correct battery | −(VBAT−0.7)→−VBAT | On, both directions (charging passes) ✔ |
| Reversed, no USB | 0 | Off; body diode reverse ⇒ blocked ✔ |
| Reversed, USB present | −(node) as charger lifts VBAT | **Turns on ⇒ ~10 mA reverse trickle into the cell — Risky #2** |

**Q1 (soil switch):** S=+3V3, D=SOIL_PWR, G=IO21/R10. Off by default (Vgs=0 via R10, including deep sleep); on at Vgs=−3.3 V ✔.

---
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

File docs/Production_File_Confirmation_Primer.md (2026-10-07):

# Reading What the Factory Sends Back — the Production-File Confirmation

*A primer for the confirmation step, written for someone approving their first board. Companion to `Fabrication_File_Primer.md` (which covers what **I** send) — this one covers what **JLC** sends back and asks me to approve. Worked examples are from the Rev A package, production no. `12792098A_Y3`, 2026-08.*

---

## 0. The single most important idea

**The confirmation package is not my upload — it's what their CAM engineer did to my upload.** A human at JLC opened my gerbers in their CAM tool, cleaned them, compensated them for their process, drew a panel around my board, and exported new files. Those new files — not mine — are what the machines run.

So the question at this step is never "is my design right?" (too late — review that before ordering). It's two narrower questions:

1. Did anything on **my board** change beyond routine process edits?
2. Is the **panel** they drew around it compatible with my board — rails, scores, and marks in the right places?

Rev A passed question 1 completely and failed question 2 (top rail under the antenna overhang). That's typical: the panel is where confirmation problems live, because it's the one thing they created that I never drew.

---
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

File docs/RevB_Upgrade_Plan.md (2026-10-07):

# Rev B Upgrade Plan — ESP32-S3 Plant Monitor
*Living document, started 2026-07-20. Items are ranked by value-per-effort; nothing here blocks Rev A.*

## 1. Integrated power path (the headline upgrade)

Rev A uses the app-note discrete load-sharing circuit (MCP73831 + SS14 + P-FET + pull-down, per Microchip AN1149 / Zak Kemble). With R16 = 10 k it works, but it inherently has a ~50–100 ms body-diode phase (0.65 V sag) at USB unplug, a Vgs-threshold-dependent switch point, and no charge safety timer. Rev B should replace the four-part cluster with one IC:
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

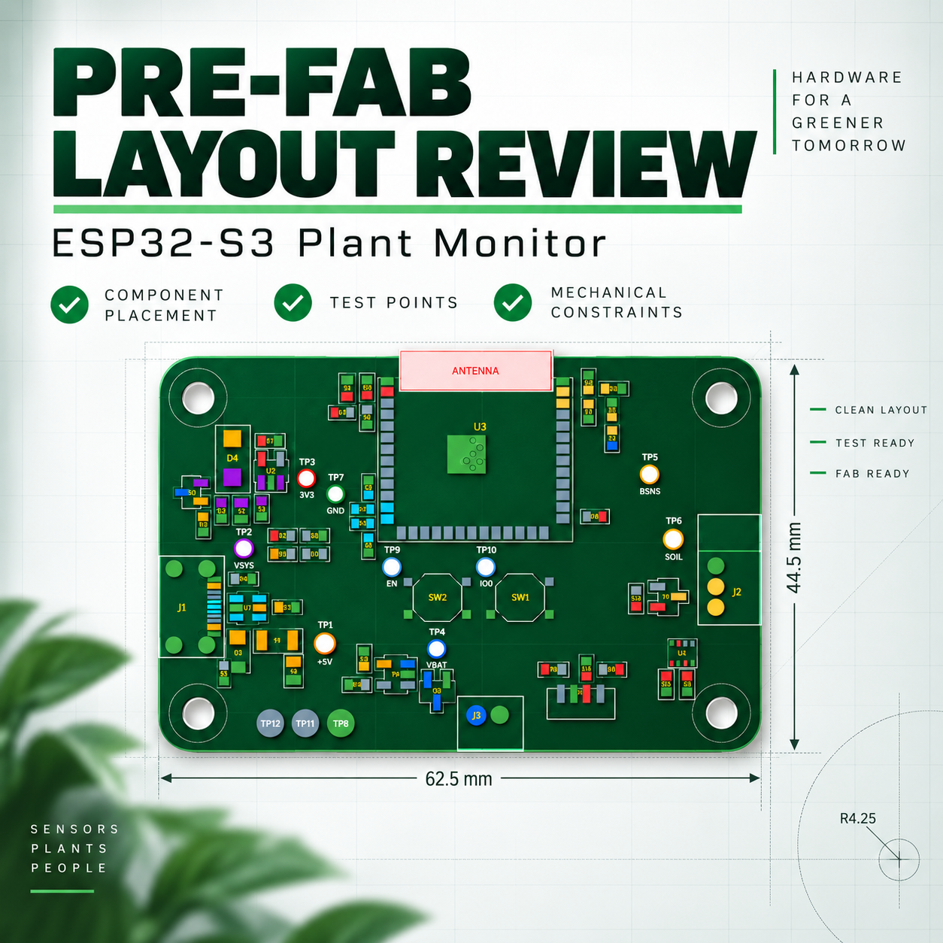
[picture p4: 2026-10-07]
docs/images/design_review.png

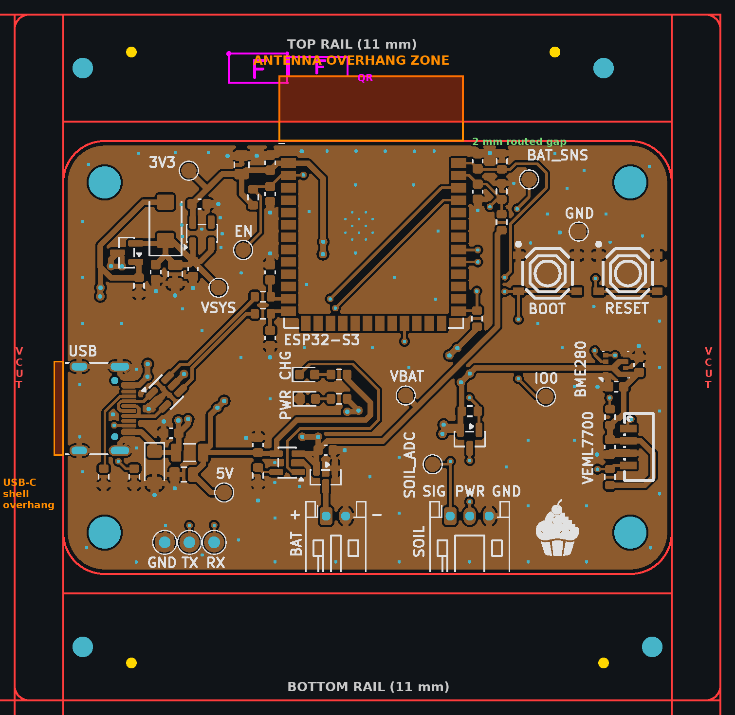
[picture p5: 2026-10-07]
fabrication/revA/production_check/1_panel_overview.png

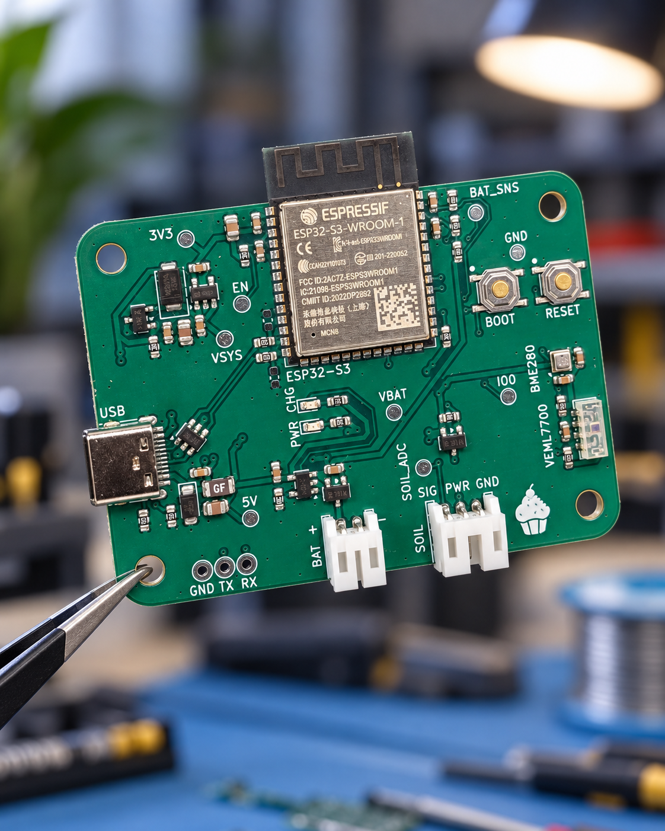
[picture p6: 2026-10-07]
docs/images/Physical board/tweezers.png

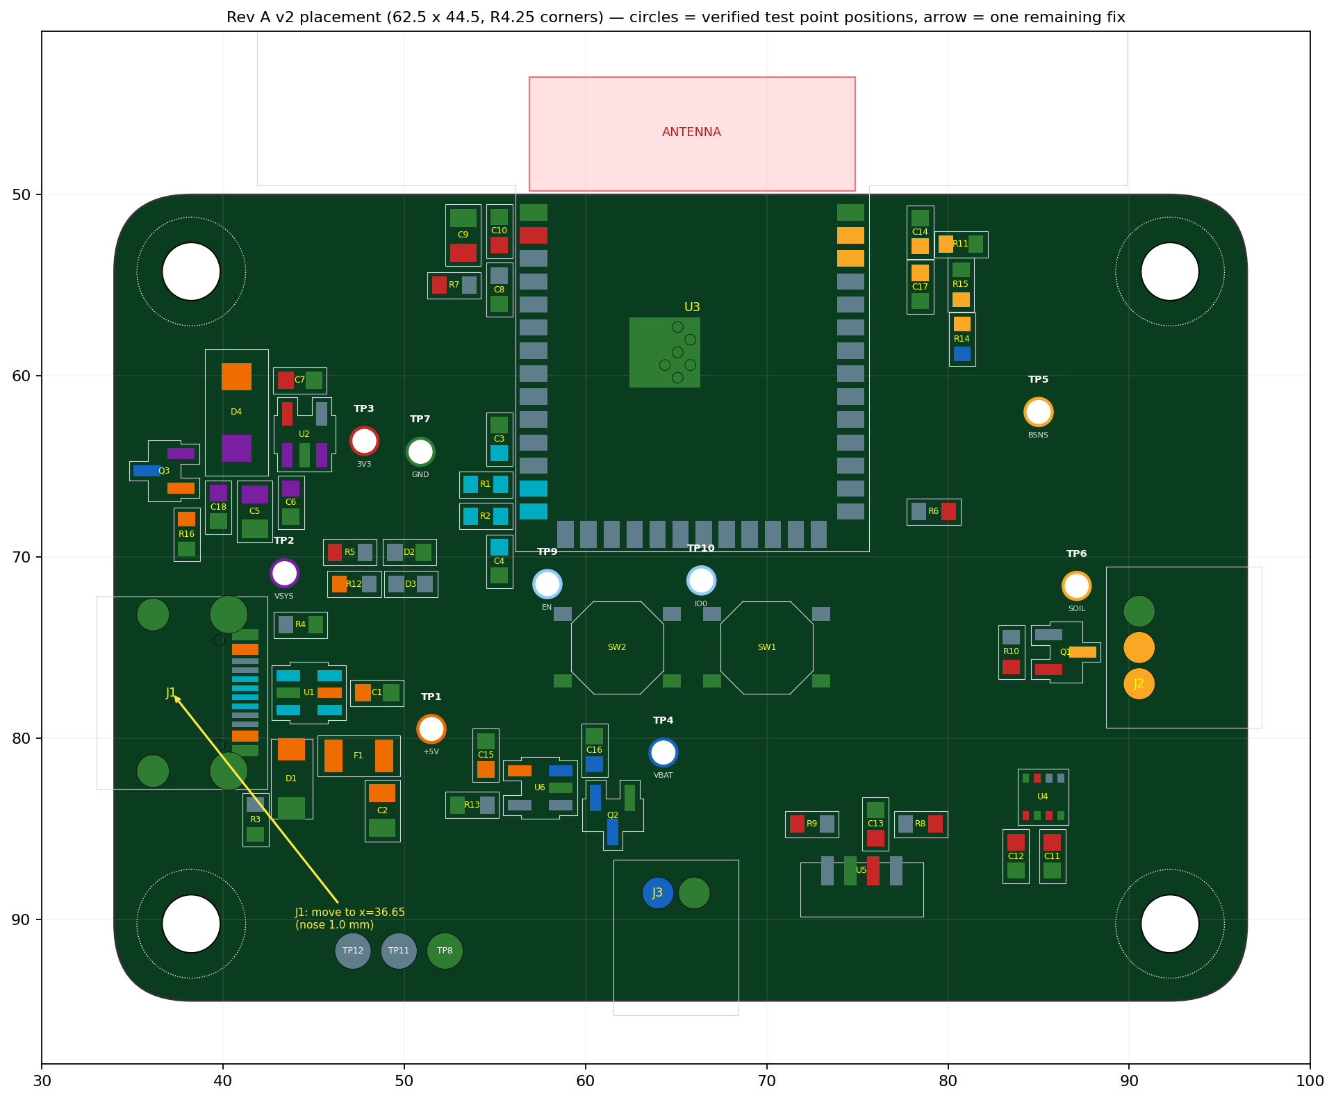
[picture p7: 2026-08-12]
docs/reviews/Placement_Review_RevA_2026-08-12_v2_map.png

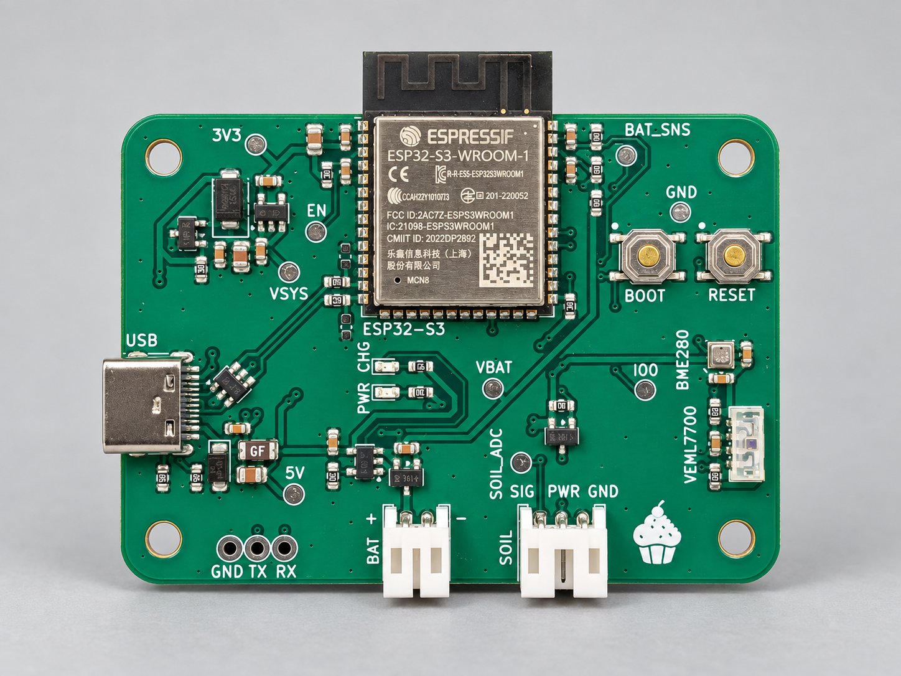
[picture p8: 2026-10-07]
docs/images/Physical board/front.png

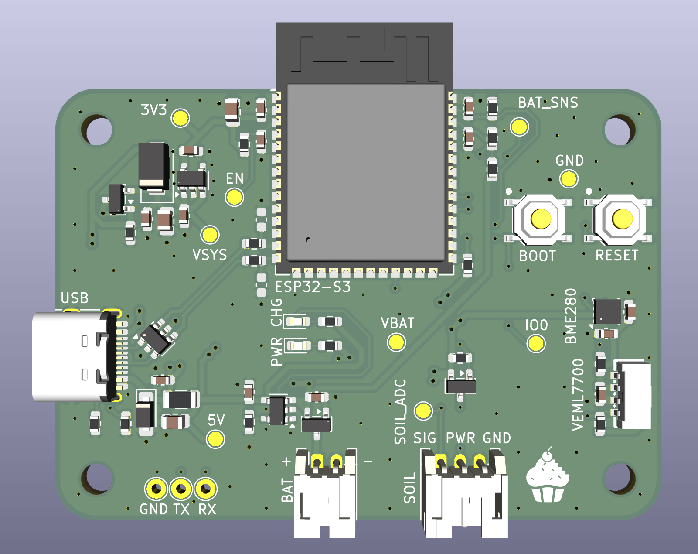
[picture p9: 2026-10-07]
docs/images/Kicad/Screenshot 2026-09-09 121832.png

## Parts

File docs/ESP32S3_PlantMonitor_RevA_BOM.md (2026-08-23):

# ESP32-S3 Plant Monitor — Rev A Bill of Materials

*GENERATED FROM THE SCHEMATIC 2026-07-20 (53 parts / 29 lines; LCSC fields verified in-file). The schematic is the master — regenerate this sheet after any change. Library status (Basic/Extended) and stock are LIVE values: re-verify every line on jlcpcb.com/parts at order time. Test points & mounting holes intentionally excluded (bare copper / holes).*

> The spreadsheet this table is generated from lives beside it as [`ESP32S3_PlantMonitor_RevA_BOM.xlsx`](ESP32S3_PlantMonitor_RevA_BOM.xlsx). For what was **actually ordered** on 2026-08-21 — including the two substitutions made on order day — see [`fabrication/revA/BOM-ESP32S3_PlantMonitor.csv`](../fabrication/revA/BOM-ESP32S3_PlantMonitor.csv).

| # | Category | Designators | Qty | Value | MPN | LCSC # | Footprint (package) | Library | Populate | Notes |
|---|---|---|---|---|---|---|---|---|---|---|
| 1 | 1 ICs & module | U1 | 1 | USBLC6-2SC6 | USBLC6-2SC6 | C7519 | SOT-23-6 | Extended | Yes |  |
| 2 | 1 ICs & module | U2 | 1 | AP2112K-3.3 | AP2112K-3.3TRG1 | C51118 | SOT-23-5 | Extended | Yes | 3.3 V / 600 mA |
| 3 | 1 ICs & module | U3 | 1 | ESP32-S3-WROOM-1 | ESP32-S3-WROOM-1-N8 | C2913198 | ESP32-S3-WROOM-1 | Extended | Yes | Standard PCBA tier only (module size) |
| 4 | 1 ICs & module | U4 | 1 | BME280 | BME280 | C92489 | Bosch_LGA-8_2.5x2.5mm_P0.65mm_ClockwisePinNumbering | Extended | Yes | 0x76; keep vent clear, away from heat |
| 5 | 1 ICs & module | U5 | 1 | VEML7700-TT | VEML7700-TT | C1850416 | SENSOR-SMD_EML7700-TT | Extended | Yes | -TT = top-view window; 0x10 |
| 6 | 1 ICs & module | U6 | 1 | MCP73831-2-OT | MCP73831T-2ACI/OT | C424093 | SOT-23-5 | Extended | Yes | 4.20 V variant; PROG 10k -> ~100 mA |
| 7 | 2 Transistors | Q1, Q2, Q3 | 3 | AO3401A | AO3401A | C15127 | SOT-23 | Basic | Yes | Q1 soil switch / Q2 reverse guard / Q3 source select |
| 8 | 3 Diodes & LEDs | D1 | 1 | SMF5.0A | SMF5.0A | C2980403 | D_SOD-123F | Extended | Yes | TVS on USB_VBUS |
| 9 | 3 Diodes & LEDs | D2 | 1 | LED_YG | KT-0603YG | C2289 | LED_0603_1608Metric | Extended | Yes | Yellow-green Vf 2.0-2.2 V (correct chemistry for 3.3 V rail). 30-42 mcd -> dim at 120 uA by design; bench-check. Went Extended 2026-07. |
| 10 | 3 Diodes & LEDs | D3 | 1 | LED_RED | KT-0603R | C2286 | LED_0603_1608Metric | Basic | Yes | Red, ~6 mA from STAT |
| 11 | 3 Diodes & LEDs | D4 | 1 | SS14 | SS14 | C2480 | D_SMA | Basic | Yes | Power-path Schottky |
| 12 | 4 Connectors & electromech | F1 | 1 | 1206L075/16WR | 1206L075/16WR | C371166 | Fuse_1206_3216Metric | Verify | Yes | 0.75 A hold / 1.5 A trip / 16 V |
| 13 | 4 Connectors & electromech | J1 | 1 | USB_C_Receptacle_USB2.0_16P | TYPE-C-31-M-12 | C165948 | USB_C_Receptacle_HRO_TYPE-C-31-M-12 | Extended | Yes | KiCad ships exact footprint. Small handling fee. |
| 14 | 4 Connectors & electromech | J2 | 1 | Conn_01x03 | S3B-PH-K-S(LF)(SN) | C157929 | JST_PH_S3B-PH-K_1x03_P2.00mm_Horizontal | Verify | Yes | Soil: pin1 sig / pin2 pwr / pin3 GND. Buzz out cable. |
| 15 | 4 Connectors & electromech | J3 | 1 | Conn_01x02 | S2B-PH-K-S(LF)(SN) | C173752 | JST_PH_S2B-PH-K_1x02_P2.00mm_Horizontal | Verify | Yes | Battery: pin1 = +. METER PLUG POLARITY FIRST. |
| 16 | 4 Connectors & electromech | SW1, SW2 | 2 | SW_Push | TS-1187A-B-A-B | C318884 | SW-SMD_4P-L5.1-W5.1-P3.70-LS6.5-TL_H1.5 | Basic | Yes | Project footprint, pads renumbered 1/1/2/2 (verified vs datasheet A-B/C-D pairing) |
| 17 | 5 Resistors 0603 | R1, R2 | 2 | 22 | 0603WAF220JT5E | C23345 | R_0603_1608Metric | Basic | Yes | USB series |
| 18 | 5 Resistors 0603 | R10, R11 | 2 | 100k | 0603WAF1003T5E | C25803 | R_0603_1608Metric | Basic | Yes | All +-1% |
| 19 | 5 Resistors 0603 | R12 | 1 | 470 | 0603WAF4700T5E | C23179 | R_0603_1608Metric | Basic | Yes | Charge-LED limit ~6 mA |
| 20 | 5 Resistors 0603 | R13, R16, R5, R6, R7 | 5 | 10k | RC0603FR-0710KL | C98220 | R_0603_1608Metric | Extended | Yes | Stock was 0 on 2026-07-20 - re-check; alternate: YAGEO RC0603FR-0710KL = C98220 (Extended) — was C25804 (Uni-Royal, Basic) — JLC pre-order failed 2026-08-18, switched to Yageo C98220 |
| 21 | 5 Resistors 0603 | R14, R15 | 2 | 100k 1% | 0603WAF1003T5E | C25803 | R_0603_1608Metric | Basic | Yes | All +-1% |
| 22 | 5 Resistors 0603 | R3, R4 | 2 | 5.1k | 0603WAF5101T5E | C23186 | R_0603_1608Metric | Basic | Yes | CC pull-downs, one per pin |
| 23 | 5 Resistors 0603 | R8, R9 | 2 | 4.7k | 0603WAF4701T5E | C23162 | R_0603_1608Metric | Basic | Yes | I2C pull-ups |
| 24 | 6 Capacitors | C1, C10, C11, C12, C13, C14, C17 | 7 | 100nF | CC0603KRX7R9BB104 | C14663 | C_0603_1608Metric | Basic | Yes |  |
| 25 | 6 Capacitors | C15, C16 | 2 | 4.7uF | CL10A475KO8NNNC | C19666 | C_0603_1608Metric | Basic | Yes | 16 V X5R — charger in/out |
| 26 | 6 Capacitors | C18, C6, C7, C8 | 4 | 1uF | CL10A105KB8NNNC | C15849 | C_0603_1608Metric | Basic | Yes | 50 V X5R |
| 27 | 6 Capacitors | C2, C5 | 2 | 10uF | CL21A106KAYNNNE | C15850 | C_0805_2012Metric | Basic | Yes | 25 V X5R — 5 V-rail & VSYS bulk (alt: Murata C440198) |
| 28 | 6 Capacitors | C3, C4 | 2 | 100nF | CC0603KRX7R9BB104 | C14663 | C_0603_1608Metric | Basic | No (DNP) | DNP - footprint only, not assembled. |
| 29 | 6 Capacitors | C9 | 1 | 22uF | CL21A226MAQNNNE | C45783 | C_0805_2012Metric | Basic | Yes | 25 V X5R — module bulk |

## Not assembled by JLCPCB — to buy and attach myself

| Item | Spec | Plugs into | Where | Notes |
|---|---|---|---|---|
| DFRobot SEN0193 soil probe | 3.3-5.5 V, out 0-3.0 V (~2.2 V max @3.3 V), ~5 mA | J2 | DigiKey/DFRobot/Amazon | Buzz out cable order first. Calibration (direct chain): wet ~1465 / dry ~2900 raw. |
| 1S protected LiPo | 3.7 V, JST-PH; bench cell: PKCell LP503035 500 mAh | J3 | Battery retailer | PCM required. METER PLUG POLARITY BEFORE FIRST CONNECT - charge LED does NOT prove polarity. Never store with battery attached. |
| PH-to-PH 3-pin cable (if needed) | JST PH 2.0 | J2 | ~$1 generic | Only if probe cable ends DuPont-style. |

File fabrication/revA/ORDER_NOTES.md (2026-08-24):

# Rev A — JLCPCB Order Notes
*The Rev A order record. Written 2026-08-17 as the pre-order decision sheet and completed 2026-08-21 when the order was placed. §7 records what was actually ordered; the ordered gerber zip, BOM and CPL are frozen alongside this file.*

*Updated 2026-08-21: the bottom silkscreen is now populated (board ID block + `JLCJLCJLCJLC` order-number token) — B.Silkscreen is a required plot layer; see §1 and §4.*

## 1. PCB settings

| Setting | Value | Why |
|---|---|---|
| Layers | **4** | L1 signal · GND1 · GND2 · L4 signal |
| Stackup | **JLC04161H-7628** | Matches the numbers entered in Board Setup (0.035 / 0.2104 / 0.0152 / 1.065 / 0.0152 / 0.2104 / 0.035, ≈1.6 mm) |
| Thickness | 1.6 mm | — |
| Impedance control | **No** | USB is Full Speed; pair is at the ~90 Ω geometry anyway (0.29/0.2), ordered as plain 4-layer |
| Surface finish | **HASL (lead-free)** | Fine for 0.5 mm-pitch USB-C; ENIG optional if flatness is wanted — pick explicitly, the KiCad stackup metadata (`copper_finish: None`) does not control the order |
| Solder mask | Green (any) | — |
| Via covering | ~~Tented (default)~~ → **Plugged** (as ordered) | "Tented" is no longer offered on 4-layer — Plugged is JLC's 4L standard at $0 and strictly better; the gerbers (no via mask openings) were already correct for it. Test *points* are pads and stay open by design |
| Remove order number | **"Specify a location"** — the `JLCJLCJLCJLC` token is placed (B.Silkscreen, under J2/J3, added 2026-08-21) | JLC prints the order number at the token and nowhere else |

## 2. Remark field — paste this text

> U3 (ESP32-S3-WROOM-1) antenna overhangs the TOP board edge by ~6.5 mm and the USB-C shell overhangs the LEFT edge by ~1 mm. Please keep panel rails and breakaway tabs clear of the top edge (the overhang must sit over empty space during assembly), and place tabs away from the right edge near the sensor components. Thanks.

Mechanism, for the record: the rail is coplanar with the board, and the module's underside sits only ~0.05–0.1 mm above the board surface — a rail under the overhang can stop the module seating flat in paste. The USB (0.96 mm) and JST (~0.4 mm) overhangs clear a standard ~2 mm routed gap on their own; only the antenna outruns it. V-scoring is impossible on this outline anyway (R4.25 corners force tab-routing), hence the tab-location request. Tabs near the right edge risk depanel flex stress on C11 (3.4 mm from the edge).

## 3. Assembly settings

- **Standard PCBA** (the module, C2913198, is Standard tier). Top side only. J2/J3 (JST PH THT) are through-hole — confirm they're included in assembly, or hand-solder them at bring-up (10 minutes, and the TP trio is THT anyway).
- Confirm in the BOM preview: **C3, C4 absent** (DNP, excluded both sides, parity-verified 2026-08-17) · **all 12 TPs and H1–H4 absent** from BOM and CPL.
- **Rotation/polarity check in the placement preview — every polarized part:** D1 D2 D3 D4 · U1 U2 U3 U4 U5 U6 · Q1 Q2 Q3 · J1 J2 J3 · SW1 SW2. Give **U1 two extra seconds — it is placed at 45°**, the exact case importers rotate wrong. LEDs are the classic victims; the preview render is the truth, not the CPL numbers.
- Live stock check at upload. **10 k = C98220** (C25804 pre-order failed 2026-08-18; BOM updated).

## 4. Fabrication files

Preferred: the kicad-jlcpcb-tools plugin (gerber zip + BOM + CPL with LCSC numbers in one step).

Manual fallback — plot **exactly this layer list** (do not upload the default plot-everything set; the saved plot parameters include User.Comments with the floorplan notes, courtyards, and fab layers):

```
F.Cu  In1.Cu  In2.Cu  B.Cu  F.Mask  B.Mask  F.Paste  F.Silkscreen  B.Silkscreen  Edge.Cuts
```

plus Excellon drill files (PTH and NPTH separate). B.Paste may be omitted (verified empty — no bottom-side parts or paste). **B.Silkscreen is required as of 2026-08-21** — it carries the board ID block (name / Rev A / date / MuffinByteLabs.com / designer) and the `JLCJLCJLCJLC` order-number token; the jlcpcb-tools plugin includes it automatically. Before upload, open the zip in a gerber viewer once: four copper layers, both masks, top paste, **both silks** (bottom shows the mirrored ID block + token), outline with the four corner arcs, plated USB shield slots, PTH + NPTH.

## 5. Pre-upload gate — closed 2026-08-21

*State of every item on the 2026-08-17 gate at the moment the order was placed.*

| Item | State at order |
|---|---|
| Name/rev + `JLCJLCJLCJLC` texts | **Done 2026-08-21** — bottom-silk ID block, order-number token, 2× logo as G1, title block filled |
| Zones refilled → DRC | **Done** — 0 errors · 0 unconnected · 0 parity (KiCad 10, verified 2026-08-17 and again on order day) |
| C3/C4 exclusion flags synced to the schematic | **Done** — both carry *dnp* + *exclude from BOM*, which is what took parity to zero |
| J1 GND pads → solid zone connection | **Done** — A1/A12/B1/B12 (and the VBUS pads A9/B9) are `zone_connect = solid`. The four shield slots stay on thermal relief **by decision**, not by omission — see the waiver in `docs/PROJECT_STATUS.md` (barrel grounds into both planes; reliefs keep the connector hand-replaceable) |
| `pre-order baseline` commit, fab files generated from it | **Done** — the frozen package in this folder was generated from that commit |
| Freeze zip/BOM/CPL here | **Done 2026-08-21** — copied from `hardware/jlcpcb/production_files/` |
| Double the VBUS via at (46.40, 73.95) | **Not done — waived.** Marked optional on 08-17; capacity margin ≫ load, consistency-only finding. Waiver recorded in `docs/PROJECT_STATUS.md` |

---

## 6. Live stock check — LCSC retail, 2026-08-17 (re-verify in the JLC library at upload; the two inventories are separate pools)

Healthy (need ≤ 10 of each, stock in the thousands-to-millions): module C2913198 (4.7 k) · BME280 C92489 (10.9 k) · VEML7700 C1850416 (786) · MCP73831 C424093 (4.2 k) · USBLC6 C7519 (27 k) · AO3401A C15127 · SMF5.0A C2980403 · SS14 C2480 · both LEDs C2289/C2286 · fuse C371166 (6.6 k) · USB-C C165948 · JST C157929/C173752 · switches C318884 · 22R C23345 · 100k C25803 · 470R C23179 · 5.1k C23186 · 100nF C14663 · 4.7µF C19666 · 10µF C15850.

Out of stock at LCSC on check date — expect to resolve at upload:

| Part | Refs | Plan |
|---|---|---|
| AP2112K-3.3 (C51118) | U2 | JLC pre-order (~$9 / 67 min, leftovers bank in My Parts Lib) — or DNP + hand-solder from DigiKey if lead time is bad. See §3. |
| 10 k 0603 1% | R5 R6 R7 R13 R16 | **Resolved 2026-08-18: C25804 pre-order FAILED** (JLC could not source a quotation; $8.61 refunded) despite huge displayed group stock. **The 10 k is now C98220** (Yageo RC0603FR-0710KL, Extended, in stock) — bought into Parts Lib, ~35 pcs. Select **C98220** for R5/R6/R7/R13/R16 at assembly BOM matching; accepts one ~$3 Extended feeder fee. BOM updated. |
| 4.7 k 0603 1% (C23162) | R8 R9 | Any in-stock Basic 4.7 k 0603 ±1% equivalent from the JLC matcher. Same value/size/tolerance = not a design change. |
| 1 µF 0603 (C15849) | C6 C7 C8 C18 | Any in-stock Basic 1 µF 0603 X5R/X7R **≥ 16 V** equivalent (rails are ≤ 5 V). |
| 22 µF 0805 (C45783) | C9 | Any in-stock Basic 22 µF 0805 X5R equivalent, **prefer 16–25 V** (DC-bias derating on the 3V3 bulk cap). |

Basic-tier staples cycle in and out weekly — if the JLC library shows the original C-number in stock at upload, use it and ignore this table.

## 7. As ordered — 2026-08-21 ✅

**Order placed 2026-08-21.** 5 boards, fab + Standard PCBA, paid ≈ **$49.26 after coupons** (PCB $12.10 + PCBA $86.79 − ~$49.63 coupons) + **$28.67 DHL Express (DDP — duties prepaid, nothing billed later)**.

**PCB as ordered:** 4L · 1.6 mm · green / white silk · FR4 TG135 · **LeadFree HASL** (+$5.10) · Specify Stackup **No** (JLC standard 4L = the 7628 stackup) · **via covering Plugged** ($0; Tented not offered on 4L) · via plating Not Specified · min-via tier 0.3/(0.4/0.45) · outline ±0.2 · flying probe · **Mark on PCB: Remove Mark** (free; JLC strips the `JLCJLCJLCJLC` token in CAM — token kept in the design as insurance).

**Assembly as ordered:** **Standard PCBA** (Economic refused **U3 AND U4 — both Standard-only parts**) · top side · qty 5 · tooling holes/rails **added by JLCPCB** · parts self-service · high-temp paste · nitrogen reflow · **remark submitted** (antenna/rails text) → "quote after review", expected $0 — **answer any JLC engineer email same-day; production pauses until then**.

**Cost anatomy (PCBA $86.79):** setup $25.56 · stencil $8.21 · feeder loading $38.25 (13 Extended lines) · SMT $2.04 · **hand-soldering J2/J3 $3.58 + manual $0.46 (§3's question: yes, the THT JSTs are assembled by JLC)** · X-ray $8.20 (module EP) · packaging $0.49 · **components $0.00 — all 27 unique parts consumed from My Parts Lib**.

**Order-day lessons (read before the next order):**

- **The JLC BOM-matching page is the only live stock truth.** The plugin's offline DB showed C25803 at 9.3 M; the matching page showed **0** and auto-sourced the two 100 k lines from that empty global stock — re-pointed them to My Parts (30 owned) via the row's search dialog. Same failure mode that killed the C25804 pre-order.
- The five 10 k still carried C25804 in the design fields — reassigned to **C98220** in the jlcpcb-tools plugin pre-generation (the plugin writes the LCSC field back to the board).
- Extended lines reserve extra units for **feeder-loading attrition** (15/15 D1, 20/20 D2, 7/7 U1, 6/6 J2…) — expected, not an error.
- Some part rotations were corrected **inside JLC's placement preview** after CPL upload (pin-1 table derived from the board file; U1's 45° imported correctly; D4 stripe → JST side, LED cathodes → USB side, BME280 dot = pin 1 at the silk triangle, second dot = lid vent). **The uploaded CPL is pre-correction — JLC's order preview / downloadable production files are the rotation truth for Rev A.**
- Checkout shipping list: the "My DHL/UPS/FedEx Account" rows are for holders of their own courier accounts ($2.50 = handling only; freight + duties + ~$35–45 brokerage would bill to that account). Global Standard Direct Line caps declared value at $59 — under this order's value. **DDP courier is the correct pick for US orders.**

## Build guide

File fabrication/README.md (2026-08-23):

# Fabrication packages

Factory output files, one folder per ordered revision. Each folder holds the **exact files uploaded
to the fab** — never a regenerated copy — so what is in here is what was manufactured.

## `revA/` — ordered at JLCPCB 2026-08-21

| File | What |
|---|---|
| `GERBER-ESP32S3_PlantMonitor.zip` | The uploaded gerber set (Excellon drill files inside) |
| `BOM-ESP32S3_PlantMonitor.csv` | The uploaded assembly BOM |
| `CPL-ESP32S3_PlantMonitor.csv` | The uploaded component placement list |
| [`ORDER_NOTES.md`](revA/ORDER_NOTES.md) | Every setting the board was ordered with, the pre-upload gate and how each item closed (§5), and the as-ordered cost and lessons (§7) |

5 boards · 4-layer · lead-free HASL · Standard PCBA · top side only.

**One caveat worth reading before reusing the CPL:** some part rotations were corrected inside
JLCPCB's placement preview *after* CPL upload. The CPL in this folder is therefore pre-correction —
JLC's order preview and their downloadable production files are the rotation truth for Rev A as
built. `ORDER_NOTES.md` §7 lists which parts were touched.

For a browsable view of what these files contain without a gerber viewer, see
[`docs/ESP32S3_PlantMonitor_RevA_FabLayers.pdf`](../docs/ESP32S3_PlantMonitor_RevA_FabLayers.pdf),
and [`docs/Fabrication_File_Primer.md`](../docs/Fabrication_File_Primer.md) for what each file type is.

## Recipe for future revisions

Freeze the exact uploaded zip + BOM + CPL, the order confirmation, and the git tag that produced
them. Tag the commit the fab files were generated from (`revA` marks Rev A) so the package here can
always be traced back to a board file.

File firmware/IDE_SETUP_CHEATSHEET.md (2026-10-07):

# Arduino IDE Setup — ESP32-S3 Plant Monitor Rev A

*Bench card. Started 2026-09-09 after losing time to a fresh IDE session with default settings.*
*The long-form version lives in [`README.md`](README.md) §Building it — this is the part I actually
need in front of me.*

---

## The settings, in one table

Select the board **first**. The Tools menu only grows these options once a board is chosen, and it
fills them with generic defaults that are wrong for this hardware in three places.

| Tools → | Default | **Set to** | Why |
|---|---|---|---|
| Board | — | **ESP32S3 Dev Module** | esp32 by Espressif Systems |
| Port | — | **the Espressif one** (see below) | not the Bluetooth ones |
| **USB CDC On Boot** | Disabled | **Enabled** ⚠️ | **The one that wastes afternoons.** Left disabled, `Serial` goes to the UART0 pins instead of USB. Board runs, uploads, and prints nothing. Looks dead. Is not |
| **Flash Size** | 4MB | **8MB (64Mb)** | the module is a WROOM-1-**N8** |
| **Partition Scheme** | Default 4MB | **8M with spiffs (3MB APP/1.5MB SPIFFS)** | must match the flash size above |
| PSRAM | Disabled | **Disabled** ✓ | N8 has none. N8**R2** would |
| USB Mode | Hardware CDC and JTAG | **Hardware CDC and JTAG** ✓ | IO19/IO20 go straight to the USB Serial/JTAG peripheral |
| Upload Mode | UART0 / Hardware CDC | **UART0 / Hardware CDC** ✓ | |
| CPU Frequency | 240 MHz | **240 MHz** ✓ | finishing a wake cycle sooner beats running it slower |

## Choosing board and port

**IDE 2.x** — the dropdown in the toolbar, next to ✓ and →:
`dropdown → Select other board and port… → type "ESP32S3 Dev Module" → pick the port → OK`

**IDE 1.x** — `Tools → Board → esp32 → ESP32S3 Dev Module`, then `Tools → Port`.

## Finding the right COM port

The dropdown lists Bluetooth serial ports too, and they look just as plausible. Identify the board by
its **USB vendor ID: `VID_303A` is Espressif**. Paste into PowerShell:

```powershell
Get-CimInstance Win32_PnPEntity | Where-Object { $_.Name -match 'COM\d+' } | Select-Object Name, DeviceID
```

The board is the row whose DeviceID contains `VID_303A`. It shows up as a plain
**"USB Serial Device (COMx)"** — Windows has no idea what it is, because this board has no bridge chip
and uses the ESP32-S3's own USB peripheral.

*Was COM5 on 2026-09-09. It can move — re-run the command rather than trusting this line.*

## Libraries

`Tools → Manage Libraries`:

| Library | Needed by |
|---|---|
| Adafruit BME280 Library | all sketches (pulls in Adafruit Unified Sensor + BusIO) |
| Adafruit VEML7700 Library | all sketches |
| **PubSubClient** (Nick O'Leary) | `plant_monitor` — **required even with `USE_MQTT 0`**, because `net.cpp` includes the header unconditionally |

## The sketches

| Sketch | Sleeps? | For |
|---|---|---|
| `sensor_check` | no | quick sensor read. Single ADC sample on soil — do not calibrate from it |
| `bringup_check` | no | fuller diagnostic, 16-sample averaging, reset reason at boot only |
| `handover_check` | no | bring-up steps 9 & 10. Reset reason **and uptime on every line**, mirrored to UART0 |
| `plant_monitor` | **yes** | the real firmware. Deep sleeps between wakes |

---

## Troubleshooting

| Symptom | Cause | Fix |
|---|---|---|
| Uploads fine, serial monitor silent | **USB CDC On Boot = Disabled** | set it to Enabled |
| No COM port in the dropdown | not enumerating | hold **SW1 (BOOT)**, tap **SW2 (RESET)**, release SW1 |
| Port appears and vanishes every second | blank flash — ROM finds no app, resets, retries | hold SW1 while plugging USB in, hold 2 s more, release. Flash once and it never recurs |
| **Port vanishes after ~10 s, comes back later** | `plant_monitor` deep-sleeping. **Not a fault** | to re-flash: hold SW1, tap SW2, release, upload |
| Edits to a file seem to do nothing | **the IDE does not reload files changed on disk** | close the tab and reopen the sketch |
| `secrets.h` tab missing | it does not exist, or the sketch was opened before it did | create it from `secrets.h.example`, then reopen the sketch |
| `PubSubClient.h: No such file` | library not installed | see Libraries above |
| A `#if SOMETHING` block silently vanishes | the macro is used **above** the `#include` that defines it — the preprocessor reads an undefined name as `0` and warns about nothing | move the `#if` below the include, or drop the guard |
| `curl: A positional parameter cannot be found` | PowerShell aliases `curl` to `Invoke-WebRequest` | use **`curl.exe`** — any curl command off the internet needs the `.exe` in PowerShell |

## Board-specific facts worth not relearning

* **There is no GPIO-controlled LED.** D2 is hardwired to +3V3 through R5; D3 belongs to the charger.
  "Is it alive?" is answered over serial, never by blinking something.
* **Silk labels are net names, not TP numbers**: `5V VSYS 3V3 VBAT BAT_SNS SIG GND EN IO0 TX RX`.
* **I²C is IO38/IO39** — `Wire.begin(38, 39)`, SDA first. The old IO4/IO5 numbers appear in retired
  docs and will silently find nothing.
* **SW1 = BOOT, SW2 = RESET.**
* **Recovery UART**: adapter TXD→TP12, adapter RXD→TP11, GND→TP8, 115200.
  **3.3 V logic only — never connect the adapter's 5 V or 3V3 power pin.**

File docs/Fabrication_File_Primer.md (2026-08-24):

# What a Factory Actually Needs to Build My Board

*A primer for Rev A. Written for someone ordering their first board. Companion to `docs/Finishing_Guide_RevA.md` Phase 5, which assumes I already know all of this.*

---

## 0. The single most important idea

**My design files never leave my computer.** JLC never sees `ESP32S3_PlantMonitor.kicad_pcb`. What I send is a set of *derived* files — flattened, dumb, machine-readable descriptions of shapes and coordinates. They contain no nets, no schematic, no design intent, no rules.

This matters because it explains every quirk below. When I wonder "how does the factory know X?", the answer is almost always either *it's in one of these files*, or *I told them in a dropdown at order time*, or — the dangerous one — *it doesn't, and it will guess*.

---

## 1. Two different services, two different file sets

| | Bare board fabrication | Assembly (PCBA) |
|---|---|---|
| What I get | A blank PCB — copper, mask, silkscreen, holes | That board with 51 components soldered on |
| Files needed | Gerbers + drill files (one zip) | BOM + CPL/position file |
| Who does it | The board shop | The assembly line, often a different building |

I can order the first without the second. I cannot order the second without the first. My JLC plugin generates all four things in one click, which hides the distinction — worth knowing it's there.

---

## 2. Gerbers — the board's artwork

### What a Gerber actually is

A Gerber file is a **2D vector image**, one per layer. It's a text file that says "select this aperture (a shape — round, rectangular, custom), move to this coordinate, flash it or drag it." Stack all the layers up in register and the result is a complete picture of the board.

The format is RS-274X, now extended as **Gerber X2**, which adds metadata attributes — the file can now declare "I am the top copper layer" and "this pad is an SMD pad, this one is a via." KiCad exports X2 by default. This is why modern fabs auto-identify my layers instead of demanding specific filenames, and why the old ritual of carefully naming files `.GTL`, `.GBL`, `.GTS` has largely died.

**A Gerber contains shapes and nothing else.** No thickness. No material. No copper weight. No net names. No part numbers. Two boards with identical Gerbers can be 0.8 mm or 2.0 mm thick, 2-layer or 4-layer, ENIG or HASL. All of that comes from the order form.

### The layers my board needs

| Gerber | What it is | Failure mode if wrong |
|---|---|---|
| `F.Cu` | Top copper | — |
| `In1.Cu` | GND1 plane | Omitted → they build a 2-layer board |
| `In2.Cu` | GND2 plane | Layers swapped → stackup inverted |
| `B.Cu` | Bottom copper | — |
| `F.Mask` / `B.Mask` | Solder mask openings | See below |
| `F.Silkscreen` / `B.Silkscreen` | White printed ink | Text over a pad gets clipped by the fab |
| `Edge.Cuts` | Board outline | **The single most common upload rejection** |

### Solder mask is backwards from what I'd expect

The green coating covers the *whole board*. The mask Gerber marks where it is **removed**. So a shape in `F.Mask` is a *hole* in the green, exposing copper so I can solder to it.

The fab also applies **mask expansion** — typically ~0.05 mm larger than the pad all round — so that slight registration error between the copper and mask layers doesn't leave green creeping onto a pad. I don't draw this; KiCad and the fab handle it.

Vias are usually **tented** — mask left over them so they're sealed. That was the plan for my 154 vias, but JLC no longer offers Tented on 4-layer, so Rev A was ordered **Plugged**; untented vias under a component can wick solder.

### Edge.Cuts must be one closed loop

This is where first orders die. The outline has to be a single, continuous, closed shape with no gaps and no double-drawn segments. A 0.01 mm gap between two line endpoints means the fab's software cannot determine what is board and what is not, and my order goes on hold with an email asking me to fix it.

My board is 62.5 × 44.5 mm with R4.25 rounded corners, drawn as four arcs and four lines. If the arcs and lines don't meet exactly, that's the failure. KiCad's DRC has an "unconnected board outline" check — it's worth running deliberately before export.

### Layers I have but won't send

`F.Fab` / `B.Fab` are documentation layers for my own use — assembly drawings, part outlines. `User.Comments`, `User.Drawings` likewise. These never go to the fab. `F.Paste` / `B.Paste` describe stencil openings; I'd need them if I were hand-assembling with a paste stencil, but JLC generates their own for machine assembly.

---

## 3. Drill files — the holes

Separate from Gerbers, in **Excellon** format. Structure is a tool table followed by coordinates:

```
T1C0.200    ; tool 1 = 0.2 mm drill
T2C0.300    ; tool 2 = 0.3 mm drill
...
T1
X64390Y58710   ; drill a 0.2 mm hole here
X64390Y59980
```

### Plated vs non-plated — and why they're separate files

- **PTH (plated through-hole)** — the hole barrel is copper-plated, so it conducts between layers. Every via on my board, plus the J1/J2/J3 connector pins and the THT test points.
- **NPTH (non-plated)** — a bare hole, no copper. My H1–H4 M3 mounting holes.

They're separate files because they happen at different points in the process. PTH holes are drilled before the plating bath; NPTH holes must be excluded from plating, usually by drilling them afterwards. If my mounting holes end up in the PTH file, I get copper barrels in them — which on a grounded board means my M3 screws are now electrically connected to the plane. Sometimes that's wanted; on my board it isn't.

### My board's drill inventory

| Diameter | Count | What |
|---|---|---|
| 0.2 mm | 12 | U3 module thermal vias (PTH) |
| 0.3 mm | 96 | standard vias (PTH) |
| 0.4 mm | 44 | power/doubled vias (PTH) |
| 0.75 mm | 5 | J2/J3 JST pins (PTH) |
| 1.0 mm | 3 | THT test points TP8/TP11/TP12 (PTH) |
| ~3.2 mm | 4 | H1–H4 mounting holes (**NPTH**) |

A **drill map** or drill report is a human-readable PDF/Gerber showing hole locations with symbols and a size table. Optional at JLC; standard practice at traditional fabs.

---

## 4. BOM — what to buy

A CSV. For JLC the columns that matter are:

| Column | Purpose | Example from my board |
|---|---|---|
| Designator | Which parts | `R5,R6,R7,R13,R16` |
| Quantity | How many | `5` |
| Comment / Value | Human sanity check | `10k` |
| Footprint | Human sanity check | `R_0603_1608Metric` |
| **LCSC Part #** | **The actual order** | `C98220` |

Identical parts are grouped onto one line with a comma-separated designator list.

**The LCSC number is the only column that truly binds.** Value and footprint are there so a human reviewer can spot when I ask for C98220 but write 100k — the machine buys whatever the LCSC number says. This is why a typo'd part number produces a board that's fully assembled and completely wrong.

All 51 of my fitted parts already carry LCSC numbers. Parts that must **not** appear here: C3 and C4 (marked DNP), all 12 test points, and H1–H4.

**Stock is checked at order time, not design time.** A part that existed when I drew the schematic may be out of stock today. The 10 k proved it: C25804 was the original choice, it failed JLC's pre-order sourcing check on 2026-08-18, and the BOM moved to C98220 before the order went through. Carrying a named alternate in the BOM notes is what made that a same-day fix instead of a lost week.

---

## 5. CPL / position file — where to put it

Also a CSV. One line per placed component:

| Column | Meaning |
|---|---|
| Designator | `R5` |
| Mid X / Mid Y | Coordinates of the footprint's origin |
| Layer | `top` or `bottom` |
| Rotation | Degrees |

### Rotation is where boards get built backwards

This is the single biggest first-order hazard, so it's worth understanding *why* it happens rather than just being told to check.

KiCad stores a rotation relative to how *KiCad's* footprint library defines pin 1. The assembly machine feeds parts from a reel, and the part's orientation in that reel is defined by *the supplier's* datasheet convention. For many part types those two conventions differ — commonly by 90° or 180°. JLC maintains an internal rotation-offset table for parts in their library, but coverage isn't perfect, and it can't know about my custom footprints.

The consequence is specific and expensive: a diode, LED, electrolytic capacitor, or IC placed exactly where it belongs but rotated 180°, so pin 1 is at the wrong corner. The board looks perfect and doesn't work.

**The only reliable check is their placement preview render** — an actual picture of my board with the parts drawn on. Compare it against my own 3D view, part by part, for everything polarized: D1–D4, U1–U6, J1, Q1–Q3, SW1/SW2. LEDs are the classic casualty.

### The origin question

Coordinates need a reference point. JLC expects them relative to the board's bottom-left corner or a defined origin. KiCad exports relative to its drill/place origin if I've set one, or the page origin if I haven't. My plugin handles the conversion — but if I ever export manually, this is the setting that silently shifts every part by the same offset.

---

## 6. Things that are settings, not files

None of this is in any file I upload. It's all dropdowns.

**Bare board:**

- Layer count — 4
- Dimensions — read automatically from Edge.Cuts
- Thickness — 1.6 mm
- Stackup — `JLC04161H-7628`. Note this means **1 oz (35 µm) outer copper and 0.5 oz (~15 µm) inner** — matching the 0.035 / 0.0152 numbers in my stackup
- Material — standard FR4
- Surface finish — lead-free HASL is fine for my board; ENIG costs more and is flatter (matters for fine-pitch parts)
- Solder mask colour, silkscreen colour
- Minimum track/spacing spec — affects price; my 0.2 mm minimum is well inside the standard tier
- Impedance control — **No**, per my decision (USB is Full Speed, 12 Mbps)
- Via treatment (plugged — Tented is not offered on 4-layer), gold fingers (no), castellated holes (no)
- Electrical test — flying-probe continuity check; standard on multilayer

**Assembly:**

- Which side — top only, all 53 parts are on F.Cu
- Assembly tier — **Standard**, forced by the module (C2913198)
- Quantity
- Tooling holes / edge rails — the machine needs somewhere to grip; JLC adds rails if needed

---

## 7. Optional files I'll hear about

| File | What it does | Do I need it? |
|---|---|---|
| **IPC-D-356 netlist** | Machine-readable "what should connect to what". The fab compares it against my Gerbers and flags mismatches before manufacturing | Optional, genuinely useful insurance, KiCad exports it |
| **ODB++ / IPC-2581** | Single-file formats bundling copper, drill, netlist and stackup together | Some fabs prefer them; Gerbers remain universal |
| **Fabrication drawing** | Dimensioned drawing with hole table and notes | Standard at traditional fabs, not needed for JLC's automated flow |
| **Stencil files** | Paste layers, for hand assembly | Not needed — JLC makes their own |
| **STEP / 3D model** | Not a fab file at all | For designing an enclosure |
| **Panel drawing** | If I want multiple boards in an array | Not for prototype quantities |

---

## 8. What happens after I press upload

1. **Automated DFM check** — software looks for unclosed outlines, clearances below spec, missing layers. Fast, and where most first-timer problems surface.
2. **Engineering review** — a human looks at anything ambiguous. This is where phantom CPL entries with no BOM line generate a query email, and where a 24-hour delay comes from.
3. **Parts sourcing** — they pull my LCSC numbers from stock.
4. **Fabrication** — the bare boards get made.
5. **Assembly** — and this is when my placement preview approval matters, because after this point a wrong rotation is a scrapped board.

---

## 9. My actual sequence

Everything above happens automatically from one plugin run. What I control is the state of the board *before* that run:

1. DRC clean, zones refilled.
2. Silkscreen pass done.
3. Exclusion flags set on C3, C4, TP1–TP12, H1–H4 — **after** my last F8.
4. Run the JLC plugin → gerber zip, BOM, CPL.
5. Upload. Set the board options in §6.
6. **Check the placement preview render for polarity and rotation.** Do not skip this.
7. Confirm live stock on the BOM.
8. Copy the exact files I ordered into `fabrication/revA/`, git commit and push.

Step 8 matters more than it looks. When Rev B happens, or when a board comes back wrong, the only way to know what I actually ordered is to have frozen the files I actually sent.

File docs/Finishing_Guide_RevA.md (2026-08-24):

# Finishing Guide — Rev A: Pours, Stitching, DRC, Silk, Order
*Written 2026-08-15 for the final stretch, with exact KiCad 10 click paths. Board state at writing: routing complete, all 12 TPs placed on-copper, TP courtyards fixed, inner planes filled. Open decisions carried in: the four TPs inside the 15 mm antenna ring (my call — waive with lead discipline, or move TP9/TP3 cheaply), three single-via +3V3 hops (optional doubling), R13 ground via (do it during the stitching pass below).*

---

## Phase 1 — Pour ground on the outer layers (~10 min)

The two inner planes already exist. Now the top and bottom get ground poured into every unused space.

1. Right toolbar → **Add Filled Zone** (or Place → Zone). Click once at a corner *outside* the board outline — the dialog opens before drawing.
2. In the dialog: **Layer: F.Cu** · **Net: GND** · Clearance **0.3** · Minimum width **0.25** · Pad connections: **Thermal reliefs** · Remove islands: **Below area limit** · Fill: solid. OK.
3. Draw a rectangle that completely encloses the board (corners out in the dark area — KiCad clips the fill to my outline minus the 0.5 mm edge rule automatically). Double-click to close it.
4. Repeat for **B.Cu** (same settings). Tip: in the layer list of the zone dialog I can tick F.Cu and B.Cu together and draw once.
5. Press **`B`** (Fill All Zones). The board floods; the pour flows around every trace and pad with 0.3 mm moats.

What I should see: solid copper nearly everywhere, small islands silently deleted, thermal-relief spokes on THT pads. If some region stays empty, it's enclosed by traces with no way in — that's what the stitching vias fix next.

## Phase 2 — Stitching pass (~30–45 min, the meditative part)

Stitching vias tie the outer pours down into the inner planes so every patch of top/bottom copper is real low-inductance ground, not decoration.

**How to place a free via:** Place → **Via**, then click to drop; it takes the GND net from the pour beneath it. Even faster: click an existing GND via, **Ctrl+C**, then **Ctrl+V** repeatedly — pasted vias keep the net. Use my standard 0.6/0.3.

**Where to put them, in priority order for this board:**

1. **Anywhere the fill left a pad on an island or peninsula.** After filling, press B again and look for ratsnest lines still pointing at GND pads — each one gets a via next to it. My SW1/SW2 ground pads and the R13 ground are the known customers.
2. **Along the top edge near the antenna** — a row roughly every 3 mm at y ≈ 51–52, from x ≈ 54 to 78, dodging the module pads and the C9/C10/C14 links. This is straight from Espressif: "sufficient ground copper and dense ground vias near the antenna," on the board side, never past the edge.
3. **A loose ~5 mm grid across any large open pour areas** (my LAW 21) — bottom-left region, center gaps, the sensor corner. Precision is irrelevant; coverage is the point.
4. **Around the LDO's copper** — make sure U2's ground region carries 4–6 vias total into the planes (its heatsink path).
5. **The board perimeter** where pour exists, every ~5 mm — it keeps the outer pours and inner planes acting as one object at the edges.

Rules while stitching: don't line vias into tight rows closer than ~1 mm (hole-to-hole rule, and rows perforate the planes), nothing past the top edge, and refill (**B**) when done — every via punches a clearance hole that the fill must renegotiate.

## Phase 3 — Refill + full DRC loop (~30 min the first time)

1. **B** to refill (always refill before DRC — stale pours make DRC lie).
2. **Inspect → Design Rules Checker.** Tick **"Refill all zones before performing DRC"** and **"Test for parity between PCB and schematic"**. Run.
3. Read the three tabs. My targets: **Errors: 0. Unconnected items: 0.** Warnings: each one either gets fixed or consciously excluded (right-click → Exclude, and keep my habit of knowing why).
4. Expected findings on the first run: silkscreen collisions (fixed in Phase 4), possibly a few zone-clearance nits where a via sits tight. Click any violation to zoom to it; fix; refill; re-run. Loop until clean.
5. Open the schematic once more and run **ERC** — it should still be clean; parity between the two is what step 2's checkbox verified.

## Phase 4 — Silkscreen pass (~45 min)

Set up the view first: in the Appearance panel, dim or hide the copper layers and show **F.Silkscreen** — silk work goes fast when I can see it.

1. **Fix colliding reference designators.** The DRC silk warnings are my worklist (~35 items). Click a refdes, **M** to move, **R** to rotate; park each one beside its part where it's readable. Rotate, don't delete — my own rule. Keep text ≥1.0 mm / 0.15 mm thickness (the JLC legibility floor already in my constraints).
2. **Label the test points by function**, not number: Place → **Text**, layer F.Silkscreen, height 1.0–1.2 mm. Next to each pad: `5V` (TP1), `VSYS` (TP2), `3V3` (TP3), `VBAT` (TP4), `BSNS` (TP5), `SOIL` (TP6), `GND` (TP7, TP8), `EN` (TP9), `BOOT` (TP10), `TX` (TP11), `RX` (TP12). Function labels make the board self-documenting at the bench; a refdes number means nothing with a probe in hand.
3. **The safety silk** (my LAW 27): big unmissable **+** and **−** beside J3's pins — the board's one true hazard is a reversed battery. Pin-1 marks at J2 and J3. `BOOT` beside SW1, `RESET` beside SW2 (schematic refs — SW1 is BOOT). `PWR` at D2, `CHG` at D3. Check D1/D4 cathode marks survived from the footprints.
4. **Nothing over pads, nothing on the BME280** — no silk on or near U4's vent, and DRC's silk-over-pad check catches the rest.
5. Optional flourishes: board name + rev + date somewhere open (`PlantMonitor RevA 2026-08`), and my logo lives at `logos:muffinByteLogo` — Place → Footprint if I want it. If I'd rather JLC's order number not land somewhere ugly, place a text reading exactly `JLCJLCJLCJLC` where I *want* it — their system replaces it and prints nothing elsewhere.
6. Re-run DRC: silk warnings should now be at or near zero.

## Phase 5 — 3D sanity + pre-order gauntlet

1. **Alt+3** for the 3D viewer. Slow lap around the board: USB nose overhang looks right, JST faces flush-ish, antenna hanging clean off the edge, nothing tall crowding the USB plug path, silk readable.
2. **Generate fabrication files with the JLC plugin** (I installed kicad-jlcpcb-tools): toolbar/Tools → External Plugins → JLCPCB Tools → Generate. It produces the gerber zip, BOM, and CPL (placement) files together, with LCSC numbers from my schematic fields. (Manual fallback: File → Fabrication Outputs → Gerbers — include F.Cu, In1.Cu, In2.Cu, B.Cu, both masks, both silks, Edge.Cuts — plus Drill Files. The plugin is easier and JLC-shaped.)
3. **In the plugin/BOM preview, verify the exclusions:** C3, C4 (DNP), all 12 TPs, H1–H4 — none of them on the BOM or placement file.
4. **Upload to JLC.** Board settings: **4 layers · JLC04161H-7628 · 1.6 mm · impedance control: No** · surface finish HASL (lead-free) is fine · everything else defaults.
5. **Assembly settings:** the module (C2913198) is **Standard PCBA tier**, so pick Standard assembly. Then the check my rulebook calls the classic victim-catcher: **in JLC's component placement preview, verify rotation and polarity of every polarized part** — D1, D2, D3, D4, U1–U6, J1, Q1–Q3, SW1/SW2. JLC's rotations sometimes differ from KiCad's by 90°/180°; their preview render is the truth. LEDs especially.
6. **Live stock check** at upload (C25804 failed pre-order on 2026-08-18; the 10 k is now C98220).
7. **Freeze and commit:** copy the ordered gerber zip, BOM, and CPL into `fabrication/revA/`, then git commit and push — my rule 32. The order confirmation email PDF is worth saving there too.

Then the board is out of my hands for a week, `BringUp_Guide.md` becomes the active document, and its step 1 stands: meter the battery plug before it ever touches J3.

---

*Click paths verified against KiCad 10 · companion to `Routing_Guide_RevA_4Layer.md` §8's definition of done.*

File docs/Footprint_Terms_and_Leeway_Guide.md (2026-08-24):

# Footprint terms & how much leeway I actually have

Written for the ESP32-S3 Plant Monitor Rev A footprint check. No jargon assumed — every term is defined with a picture the first time it appears.

The one thing to remember

A footprint is not trying to copy the datasheet drawing. It is trying to make sure **every piece of metal on the part lands on copper, with a little copper sticking out past each end.**

That's what the solder needs. Most of the numbers in a datasheet's suggested layout are one designer's way of achieving that — there are many valid ways. Only a few numbers are actually load-bearing, and this page tells me which.

## 1 The words, with pictures

Start here. Everything else on the page uses these five or six words.

### A part with legs (my SOT-23 parts: the LDO, the charger, the MOSFETs, the ESD chip)

Side view of a component leg sitting on a copper pad

*One leg, seen from the side. The leg bends down out of the body and flattens out — that flat bit is the **foot**. The copper **pad** underneath is longer than the foot, so there's bare copper poking out at each end. Molten solder runs into those gaps and freezes into a wedge. That wedge is the joint.*

- **Pad** — One rectangle of copper on my board. Also called a *land*. — *The metal shape I'm measuring in KiCad.*
- **Footprint** — The whole set of pads for one part, plus its outline and courtyard. — *What I pick in KiCad. It's a pattern, not a part.*
- **Lead** — One leg of the part. — *Just "the leg".*
- **Foot** — The flat underside of the leg — the only bit that actually touches copper. — *Like a human foot: the flat part on the ground.*
- **Heel** — The end of the foot closest to the body. — *Same as my heel — the back.*
- **Toe** — The far tip of the foot, pointing away from the body. — *Same as my toes — the front.*
- **Fillet** — The wedge of solder that forms in the overhang past the heel or toe. — *The bead of solder I can see around a good joint.*

**Why anyone cares about heel vs toe:** the heel wedge is the strong one — it's the part inspectors X-ray and the part that survives being dropped. A pad biased toward the heel (like KiCad's) makes a mechanically stronger joint. A pad biased toward the toe (like Microchip's) makes a joint that's easier to see with a camera. Both work. That's the whole disagreement I found on the SOT-23-5.

### Looking down from above — the words for spacing

Top view of a five pad footprint showing pitch, gap and span

*The same part from above (this is a SOT-23-5, like my AP2112K and MCP73831). Red = the two dimensions that can actually break a board. Blue = the ones with room to move.*

- **Pitch** — The centre-to-centre distance between two neighbouring pads in the same row. — *Fence-post spacing. How far apart the legs are.*
- **Gap** — The bare board *between* two pads. Two kinds matter: between side-by-side neighbours, and between the two rows. — *The empty space. Too small = solder bridges two legs together.*
- **Span** — Total distance across, outer edge to outer edge. — *How wide the whole pad group is.*
- **Courtyard** — An invisible box on its own layer saying "keep other parts out of here." — *Personal space. It doesn't get manufactured — it's just KiCad reminding me not to crowd things.*

### Parts with no legs — my resistors, capacitors, LEDs, fuse

Side and top view of a chip resistor on two pads

*A chip resistor or capacitor has no legs — just a silver metal cap wrapped around each end. Everything works the same: the cap is the "foot", and the pad has to reach under it *and* poke out past it. There's only one gap to worry about, and no pitch at all.*

### Through-hole parts — my two JST battery / sensor connectors

Cross section and top view of a through hole pad

*Through-hole is the one place where a number is a genuine physical limit: **the hole has to be bigger than the pin.** No solder fillet can save me from a hole that's too small — the connector simply will not go in. This is exactly why the Ø0.75 mm drill on my two JST connectors is flagged in the checklist.*

## 2 See it firsthand

*In the original HTML this was an interactive demo: a fixed component foot on a copper pad I could
stretch, shrink and slide, with a live verdict. The foot is **0.45 mm** long and never moves — only
the copper underneath changes. The presets it offered are below, with the same verdict the demo
would have shown.*

The number that decides everything is the **worst-end margin** — how much copper sticks out past the
tighter end of the foot:

```
margin = pad_length / 2 − |offset| − foot_length / 2
```

| Preset | Pad length | Offset | Worst-end margin | Verdict |
|---|---|---|---|---|
| Microchip's SOT-23-5 pad | 1.1 mm | +0.00 mm | +0.325 mm | **GOOD** — copper past both ends with room to spare |
| KiCad's SOT-23-5 pad | 1.325 mm | -0.26 mm | +0.177 mm | **GOOD** — copper past both ends with room to spare |
| Much longer pad | 1.6 mm | +0.00 mm | +0.575 mm | **GOOD** — copper past both ends with room to spare |
| Pad too short | 0.4 mm | +0.00 mm | -0.025 mm | **BROKEN** — metal hangs off the copper; no room for a solder wedge on that side |
| Pad shifted too far | 1.1 mm | +0.38 mm | -0.055 mm | **BROKEN** — metal hangs off the copper; no room for a solder wedge on that side |

Notice what I can and can't break. Making the pad **longer** never breaks it — the "much longer
pad" is as sound as the datasheet's own. Making it much **shorter**, or **sliding it sideways**,
does, because one end of the metal ends up hanging off the copper. That asymmetry is the whole
reason pad length has leeway and pitch doesn't.

Note the second row: KiCad's SOT-23-5 pad is a different length *and* offset from Microchip's
recommendation, and still lands comfortably in GOOD. Two different drawings, one working joint —
which is the point of this whole page.

## 3 What's strict, what's loose

Every dimension I'll measure falls into one of these three buckets.

### EXACT Must match the datasheet, no tolerance

These are the ones where "close enough" isn't a thing. If one of these is wrong, stop and fix it before I do anything else.

| | |
|---|---|
| Pitch | Small errors **add up** along the row. Off by 0.05 mm and by the fifth leg I'm off 0.20 mm — leg 3 lands fine and leg 1 misses entirely. There is no such thing as "roughly the right pitch." |
| Number of pads | Self-explanatory, but worth a glance — a SOT-23-5 footprint under a 6-pin part is a real mistake people make. |
| Which pad is pin 1, and which direction the numbering runs | Not a measurement — it's right or wrong. This is the error that costs a board spin, because the board looks perfect and simply doesn't work. My BME280 is the risky one here (KiCad ships both a clockwise and a counter-clockwise version). |
| Hole diameter, relative to the pin | A physical fit. The pin either goes in or it doesn't. |

### AT LEAST Bigger is fine — smaller is not

One-sided limits. When a datasheet says `MIN` next to a number, it's one of these. My job is just "am I at or above it?"

| | |
|---|---|
| Gap between neighbouring pads | The only dimension that causes solder bridges. If the datasheet says 0.35 min, then 0.35 or more is fine and 0.30 is not. Tightest on my board: the BME280 at 0.15 mm. |
| Annular ring | Set by my fab, not the part. Too thin and the copper collar can tear away from the hole during drilling. JLC wants roughly 0.15 mm minimum. |
| Courtyard | Must at minimum wrap around every pad and the body. Bigger just means I'm being more cautious about neighbours. *My VEML7700 fails this one* — its courtyard doesn't reach the pads. |
| Keepout / clearance zones | The ESP32 antenna area. Bigger is always safer; smaller degrades my Wi-Fi range. |

### LOOSE A few tenths of a millimetre either way is normal

This is where nearly all my datasheet-vs-KiCad differences will land. Difference here is **expected**, not a defect. Record it and move on.

| | |
|---|---|
| Pad length (the heel-to-toe direction) | Any length works as long as copper pokes out past both ends of the metal. Longer usually means a stronger joint. A 0.2–0.3 mm difference from the datasheet is completely routine. |
| How far out the pads sit — span, row spacing | This just moves *where* the overhang goes: more behind the heel, or more past the toe. Both are valid design choices. This is exactly the SOT-23-5 difference I found. |
| Pad width, *as long as the neighbour gap holds* | Wider pads are fine in isolation. The only reason to care is that widening a pad shrinks the gap to its neighbour — so it collapses back into the AT LEAST rule above. |
| Courtyard size beyond the minimum | A spacing hint for me, not something the factory manufactures. |
| Silkscreen lines and outlines | Cosmetic — as long as no silk sits on top of a pad, where it would block solder. |
| Pad corner shape (square vs rounded) | No electrical or mechanical difference at this scale. |

## 4 When a number doesn't match — do this

Work down the list. The moment one fails, that's my answer; I can stop.

**Is the pitch the same?**Compare only the centre-to-centre spacing. If it differs at all — even by 0.05 mm — *the footprint is wrong.* Fix it or pick a different footprint. If it matches, carry on. **Is the gap between neighbouring pads at least as big as the datasheet's?**Equal or bigger is a pass. If mine is *smaller*, I've raised the solder-bridge risk and should widen the gap. Bigger than the datasheet is never a problem. **Does copper stick out past both ends of every piece of metal on the part?**This is the real test, and the sliders above are how I picture it. Sketch the part's metal over my pad. If the metal fits inside the copper with a bit of room at each end, the joint will form — regardless of what the datasheet drew. If the metal *overhangs the copper at either end*, fix the pad. **Is pin 1 in the same place, numbered in the same direction?**Check the datasheet's pin-out table, not just its drawing. If it disagrees, *stop and fix it* — nothing else on the board matters until this is right. **Does the courtyard wrap around all the pads?**If not, extend it. It costs nothing and it's what stops me overlapping parts during layout. **Anything else different?**Write it in the notes field and mark the footprint verified. Pad 0.2 mm longer, pads sitting 0.3 mm further in, a differently-shaped silk outline — none of that needs action. I've already checked the five things that can actually fail.

## 5 My 20 footprints — the one thing to watch on each

Rather than checking every number equally hard, here's the dimension that actually matters per family.

| My footprints | Watch | Because |
|---|---|---|
| 0603 / 0805 / 1206 chips · 36 resistors, caps, LEDs, the fuse | gap | No pitch to get wrong, only two pads. Just confirm the pad reaches under the end cap and out past it. The fuse is the one worth a real look — Littelfuse specs a bigger pad than a generic chip land. |
| SOT-23, SOT-23-5, SOT-23-6 · MOSFETs, LDO, charger, ESD chip  | pitch gap  | Pitch is 0.95 mm on all of them and matches. Neighbour gap is 0.35 mm and matches. Pad length differs from every vendor — that's the LOOSE bucket. **Already resolved: no action.** |
| BME280 LGA-8 | pin 1 dir  | 0.15 mm between pads — tightest copper on the board. But the real risk is numbering direction: KiCad ships a clockwise and a counter-clockwise variant and I've got the clockwise one. Verify against Bosch's pin-out *table*. |
| ESP32-S3-WROOM-1 | keepout | Pads are 1.27 mm pitch and huge — hard to get wrong. The antenna clearance area is the thing that quietly ruins the board. |
| JST PH 2-pin and 3-pin | drill Ø | Physical fit, no solder fillet can rescue it. KiCad uses Ø0.75 mm against a pin that's about 0.71 mm across the diagonal. Check JST's own figure. |
| USB-C receptacle | everything | The exception to this whole page. A connector is a mechanical fit — the shield legs, the locating pegs and the board-edge position all have to match the drawing exactly. Treat every number as EXACT. |
| VEML7700 (custom) | courtyard  | Converted footprint, so nothing is inherited from a trusted library: courtyard extended to enclose the pads, every pad re-derived from the Vishay drawing. Matches to within 5 µm. |
| Tactile switches (custom) | — | Four big pads, wide spacing, no fine pitch. The only real risk is the internal A-B / C-D pairing, verified against the XKB TS-1187A drawing. |
| Test points, mounting holes | — | Nothing to verify against. Just confirm the SMD test points have no solder paste and the M3 holes have room for a screw head. |

Companion to **`Footprint_Check_ESP32S3_PlantMonitor_RevA.md`** · ESP32-S3 Plant Monitor Rev A · both files live in `docs/`

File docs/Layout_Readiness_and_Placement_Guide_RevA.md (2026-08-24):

# Layout Readiness & Placement Guide

ESP32-S3 Plant Monitor — Rev A  ·  footprint verification against datasheets + placement playbook  ·  reviewed 2026-08-02 from the saved KiCad files (post-F8 board, 69 footprints, no placement yet)

**Verdict: clear to start layout.** Every footprint on the board was measured pad-by-pad and compared against the land pattern in its datasheet, and every pad→pin→net assignment was re-checked from the board file. All six of my custom footprints match their datasheet drawings to within 0.01 mm. No blocking problems were found. There are a handful of small housekeeping items (Section 2) worth doing in my first ten minutes — the biggest is a duplicated library entry and finishing the board-setup rules — then I can place parts with confidence.

**Contents**  
[1 · Footprint verification results](#footprint-verification-results)  
[2 · Small fixes before I start](#small-fixes-before-i-start-10-minutes)  
[3 · Suggested floorplan](#suggested-floorplan)  
[4 · Placement guide, part by part](#placement-guide-part-by-part)  
[5 · Routing rules for this board](#routing-rules-for-this-board)  
[6 · My first hour of layout, in order](#my-first-hour-of-layout-in-order)  
[7 · Before I order](#before-i-order)  
[8 · What was checked, and how](#what-was-checked-and-how)

## Footprint verification results

A **land pattern** is the manufacturer's recommended copper pad arrangement for a part. Below, "measured" is what is actually in my KiCad libraries and board file; "datasheet" is the recommended pattern from the PDF in `references/datasheets/`. Center-to-center = distance between pad centers. All numbers in mm.

### My six custom footprints (the ones I edited)

| Part | Footprint | Measured | Datasheet says | Result |
|---|---|---|---|---|
| **J1** — USB-C receptacle · HRO TYPE-C-31-M-12 (C165948) | `USB_C_Receptacle_HRO_TYPE-C-31-M-12` | 8 signal pads 0.3×1.45 @ 0.5 pitch · 4 power/GND pads 0.6×1.45 · VBUS c-c 4.90 · GND c-c 6.50 · peg holes Ø0.65 @ 5.78 · shield slots 0.6×1.7 / 0.6×1.4 @ 8.64 | 8 × 0.30 @ 0.50 pitch ✓ · 4 × 0.60 ✓ · VBUS c-c 4.80 · GND c-c 6.40 · pegs Ø0.60 @ 5.78 ✓ · slots 1.70 / 1.40 @ 8.65 ✓ | MATCHES · two 0.05 notes below |
| **SW1, SW2** — buttons · XKB TS-1187A (C318884) | `SW-SMD_4P-L5.1-W5.1-P3.70-LS6.5` | 4 pads 1.0×0.75 · at x=±3.0, y=±1.85 · numbered 1/1 top row, 2/2 bottom row | 7.0 outer / 5.0 inner → ±3.0, 1.0 wide ✓ · pin pitch 3.70 → ±1.85 ✓ · internal pairing: A-B = top, C-D = bottom ✓ | MATCHES · PAIRING CORRECT |
| **U5** — light sensor · Vishay VEML7700-TT (C1850416) | `SENSOR-SMD_EML7700-TT` | 4 pads 0.7×1.6 · @ 1.27 pitch (±1.90, ±0.63) | "Top view" proposed layout: · 4 × 0.7×1.6 @ 1.27 (±1.905, ±0.635) | MATCHES · 5 µm rounding only |
| **D4** — Schottky diode · SS14, SMA package (C2480) | `D_SMA` | 2 pads 1.52×1.68 @ ±1.97 · span 5.46 · gap 2.42 | B=1.52, A=1.68, C(c-c)=3.93 · E(span)=5.45 · D(gap)=2.41 | EXACT |
| **D1** — TVS diode · SMF5.0A, SOD-123FL (C2980403) | `D_SOD-123F` | 2 pads 1.25×1.5 @ ±1.63 · span 4.51 · gap 2.01 | X=1.25, Y=1.50, C(c-c)=3.25 · X1(span)=4.50 · G(gap)=2.00 | EXACT |
| **F1** — resettable fuse · Littelfuse 1206L075/16WR (C371166) | `Fuse_1206_3216Metric` | 2 pads 1.0×1.8 @ ±1.40 · gap 1.80 | pads 1.00 × 1.80, gap 1.80 · (part body 3.0–3.4 × 1.5–1.8 fits) | EXACT |

**The two 0.05-mm notes on the USB-C** (worth understanding, not worth fixing): (1) my VBUS and GND pads sit at ±2.45 / ±3.25 where HRO's drawing says ±2.40 / ±3.20 — a 0.05 mm outward shift inherited from the KiCad library. The connector's legs are ~0.3 mm wide landing on 0.6 mm pads, so they are still fully covered with margin, and the drawing itself declares "tolerance for PCB layout is ±0.05." (2) My pad length is 1.45 vs the drawing's ~1.6 — the pad toe simply ends a hair earlier; this exact geometry ships on thousands of JLC-assembled boards. Both are textbook examples of acceptable leeway.

### Stock KiCad footprints (checked against the same datasheets)

| Part(s) | Footprint | Measured vs datasheet | Result |
|---|---|---|---|
| **U3** — ESP32-S3-WROOM-1 · (C2913198) | `RF_Module:ESP32-S3-WROOM-1` | 40 pads 1.5×0.9 @ 1.27 pitch = Espressif Fig 11-1 exactly. Center thermal pad 3.9×3.9 (Espressif: 3.7×3.7 — KiCad adds 0.2, standard practice), 9 paste windows, 12 Ø0.2 ground vias in-pad (Espressif asks for thermal vias here ✓). Antenna keep-out zone included in the footprint. | MATCHES |
| **U4** — BME280 · (C92489) | `Bosch_LGA-8_2.5x2.5mm_P0.65mm · _ClockwisePinNumbering` | Pads 0.35×0.5 @ 0.65 pitch, rows ±1.025 = Bosch Fig 21 (0.5×0.35, pitch 0.65, row offset 0.775+0.25) rotated 90°. Clockwise numbering matches Bosch's top view; nets confirm pin 1=GND … 8=VDD. | EXACT |
| **U2** AP2112K · **U6** MCP73831 | `SOT-23-5` | Pitch 0.95 and width 0.6 match both vendors. KiCad's pads are longer toward the part center (1.325 vs vendor 0.8–1.1) — a roomier generic pattern that fully covers the lead feet. Normal and proven; no change. | OK — standard |
| **U1** USBLC6-2SC6 | `SOT-23-6` | ST asks 0.6 wide, 0.95 pitch, rows 2.30 c-c, 3.50 overall; KiCad gives 0.6 / 0.95 / 2.275 / 3.60. Equivalent. | OK — standard |
| **Q1–Q3** AO3401A | `SOT-23` | AOS's datasheet ships no land pattern; KiCad's generic SOT-23 (industry pattern for this JEDEC package) is correct. Pinout 1=G, 2=S, 3=D verified through the netlist for all three. | OK — standard |
| **J2, J3** — JST PH headers | `JST_PH_S3B / S2B-PH-K Horizontal` | 2.0 pitch ✓. Holes drill 0.75 for JST's 0.5 mm square posts (diagonal 0.71) — inside JST's 0.7–0.8 window, on the snug side; fine for hand soldering. | OK |
| **R\*, C\*, D2, D3** — 0603/0805 passives & LEDs | `R_0603 / C_0603 / C_0805 / LED_0603` | Standard 1608/2012-metric patterns; correct for the Samsung MLCCs and 0603 LEDs. LED polarity verified in the netlist (pad 1 = cathode: D2 K→GND, D3 K→STAT ✓). | OK — standard |
| **TP1–TP12, H1–H4** | `TestPoint_Pad_D1.5mm · THTPad_D2.0/1.0 · MountingHole_3.2mm_M3` | As planned: 9 flat pads, 3 through-hole (TP8/11/12 — the UART recovery trio), Ø3.2 unplated M3 holes. | OK |

### Pad → pin → net double-check

Because a footprint can be dimensionally perfect and still wired wrong, every IC's pads were traced to their nets in the board file and compared against the datasheet pinout: **U1** flow-through ESD routing (connector side pins 1/3, module side 6/4, VBUS on 5) ✓ · **U2** VIN/GND/EN/NC/VOUT ✓ (EN tied to VIN ✓) · **U6** STAT/VSS/VBAT/VDD/PROG ✓ · **Q1/Q2/Q3** gate-source-drain all match the working power-path logic from my July reviews ✓ · **D1** cathode→VBUS, anode→GND (correct clamp direction) ✓ · **D4** anode→+5V_PROT, cathode→VSYS ✓ · **J1** all four GND pins grounded, four VBUS pins tied, CC1/CC2 each with their own 5.1 k pulldown, SBU left open, shield→GND ✓ · **J2** signal/power/ground order matches the DFRobot probe ✓ · **J3** pin 1 = battery +, pin 2 = GND ✓ · **SW1** IO0↔GND, **SW2** EN↔GND ✓. The board's embedded footprint copies are also byte-identical in geometry to my `libs/` versions — my latest edits made it into the board, nothing stale.

## Small fixes before I start (10 minutes)

| | What | Why & how |
|---|---|---|
| FIX  | **De-duplicate the footprint library table.** `hardware/fp-lib-table` lists `PlantMonitor_JLC` four times. | Each footprint import appended a fresh entry. Duplicate nicknames cause "duplicate library" warnings and can confuse footprint resolution. Open *Preferences → Manage Footprint Libraries → Project Specific* and delete the three duplicate rows (keep one), or edit the file and keep only one `PlantMonitor_JLC` line plus `logos`. Close KiCad first or expect a reload prompt — there are live `.lck` files, so KiCad is likely open right now. |
| FIX  | **Set the board's minimum clearance.** Board Setup → Design Rules → Constraints currently has minimum clearance = 0. | The Default netclass (0.2 mm) governs routing, but the board minimum is the DRC floor for everything else (zones, footprints). Set it to **0.2 mm** to match my plan (JLC's true floor is 0.127). While there, add track width presets `0.2 / 0.25 / 0.3 / 0.5 / 0.8` and via preset `0.6 / 0.3` so they're one click away while routing. |
| FIX  | **Create the net classes I planned.** Only "Default" exists right now. | Board Setup → Net Classes: add **Power** — track 0.5 mm, clearance 0.2 — and assign `USB_VBUS`, `+5V_PROT`, `VSYS`, `VBAT`, `VBAT_RAW`, `+3V3`. Add **USB** — track 0.25, diff-pair width 0.25 / gap 0.2 — for `USB_DP`, `USB_DN`. Now the correct widths happen automatically instead of by memory. |
| TIDY | **Three courtyard nits in custom footprints.** | A **courtyard** is the invisible "personal space" rectangle DRC uses to stop parts overlapping. On the switch it's drawn at the 5.1×5.1 body only, but the pads span 7.0 — so DRC won't warn if something is placed onto the button's pads. VEML7700's courtyard clips its pad bottoms by 0.34 mm, and D_SOD-123F's pads poke 0.05 mm past. Either stretch the courtyards in the footprint editor (30 s each: cover pads + 0.25 mm) or just eyeball ~1 mm of space around those three parts. Nothing here affects fabrication. |
| KNOW | **C3/C4 (DNP) sit directly on the USB data lines.** | They're correctly marked do-not-populate. Know for later: if I ever fit them, 100 nF would kill USB signalling — data-line filter caps are ≤ 47 pF. Treat them as emergency EMI pads only, and when placing, keep their stub off the D+/D− path as short as possible. |
| KNOW | **The logo footprint isn't on the board.** | `logos:muffinByteLogo` exists in my library but wasn't imported (it's not in the schematic — fine). During layout add it with *Place → Footprint*, or skip it. |

## Suggested floorplan

This is one sensible arrangement that satisfies every constraint at once — antenna off the edge, protection at the connector, sensors away from heat, analog away from USB. Mine doesn't have to match it; use it to sanity-check whatever I draw. A ~52 × 42 mm outline is comfortable for this part count on 2 layers; smaller is possible once I'm happy with the flow.

Suggested floorplan sketch

*Zones, not exact positions. Blue = USB path (enters left, protection immediately, pair runs to the module). Red = power/heat. Green = sensors and connectors. Hatched = antenna keep-out: no copper, traces, or silk on any layer; mounting hardware stays clear of it too.*

## Placement guide, part by part

**Three habits that make all of this easy:** ① Place each chip's decoupling capacitors *with* the chip — chip first, its caps immediately after, before anything else gets that space. A decoupling cap only does its job within a few mm of the pin it serves. ② Think in **current loops**: power flows out and must return through ground right underneath — short loop, quiet board. ③ Rotate parts so traces leave in the direction they need to travel; a good placement nearly routes itself. sheet 02

### J1 — USB-C connector

**Where:** on a board edge, dead center of one side is classic. The metal nose should overhang the edge by ~1 mm so a plug seats fully — per the HRO drawing, the board edge belongs ~1.6 mm in front of the rear shield-slot centers. Set it exactly: select J1, press E, and type the position so the edge lands there, then check side-on in the 3D viewer (Alt-3).

**Why:** recessed connectors don't let the plug latch; too much overhang strains the solder joints. The two Ø0.65 holes are locating pegs — they set alignment, so don't nudge the part off-grid relative to my edge line.

**Watch out:** leave ~10 mm of free space outside the edge for the plug's plastic overmold, and don't put tall parts within ~5 mm of the connector sides. The four shield pads want a solid connection into the ground pour — they take the yank when a cable is pulled. Route nothing on the bottom layer directly under the pad row if I can help it; that area becomes my USB ground reference. sheet 02

### D1 (TVS) · F1 (fuse) · U1 (ESD chip) — the protection cluster

**Where:** immediately behind J1, in the order the electrons arrive: VBUS pin → D1 clamp → F1 fuse → onward as +5V_PROT. U1 sits directly in the D+/D− path between the connector and the module.

**Why:** protection parts only protect what's *behind* them. A surge entering the plug must hit the TVS before anything else, which physically means short, fat copper from the VBUS pads to D1 (0.5 mm+ traces, a few mm long). U1 is a "flow-through" part: pins 1/3 face the connector, pins 6/4 face the module — data enters one side, exits the other, no stubs and no doubling back.

**Watch out:** R3/R4 (the 5.1 k CC pulldowns) belong right at the connector's CC pads with short drops to ground — they're what makes a USB-C charger turn on the 5 V. C1 goes next to U1's VBUS pin. C3/C4 are do-not-populate; give them a home tight against the data path where their stub is a millimetre, not a detour. sheet 02→04

### R1, R2 — the 22 Ω USB series resistors

**Where:** near the *module* end of the data run (close to U3 pins 13/14), not at the connector — my July review flagged this as a layout-time item; now is when it happens.

**Why:** series damping resistors work best close to the signal source — the ESP32 is the transmitter I care about. Keep D+ and D− side-by-side through the resistors with both resistors at the same height, so the pair stays matched.

sheet 03

### U2 — AP2112K 3.3 V regulator

**Where:** in the power zone, roughly between D4/Q3 (its input) and the module (its biggest customer). C5 (10 µF) + C6 (1 µF) at the VIN pin, C7 (1 µF) at VOUT — caps first, millimetres from the pins, each with a ground via right at its ground pad.

**Why:** this little part burns up to ~0.26 W during a long Wi-Fi session — real heat for a SOT-23-5. It sheds heat through its pins into copper: give its GND pin a generous pour (a square centimetre or more if I can) on the top layer, tie it to the bottom-layer ground with 4–6 stitching vias, and let the pour breathe.

**Watch out:** keep U2 (and its warm pour) well away from the BME280 — a couple of degrees of board heat becomes a temperature-reading error. Confirmed requirement from both prior reviews, not optional. Thermocouple-check at bring-up. sheet 07

### U6 (charger) · Q2/Q3 · D4 · R16 — battery & power path

**Where:** cluster them: J3 → Q2 → charger/Q3, with D4 bridging +5V_PROT→VSYS. C15 (4.7 µF) at U6's VDD pin, C16 (4.7 µF) at its VBAT pin, R13 (PROG) short to pin 5 with its far end dropping straight to clean ground. R16 near Q3's gate. Keep the whole VSYS node — D4 cathode, Q3 source, LDO input — physically compact and fat (0.5–0.8 mm).

**Why:** the hand-over between USB and battery lives on these few square centimetres; loose, thin copper here shows up as the brown-out I already engineered against with R16 = 10 k. The charger also dissipates ~0.2 W into a low battery — give its pins copper too. D3 + R12 (charge LED) can trail off toward wherever my LEDs live; STAT is a slow signal and doesn't care.

**Watch out:** J3's silkscreen needs big, unmissable **+** and **−** marks (my own hard rule: meter the pack before it ever touches the board — silk is the second line of defense). Face the connector opening toward the board edge so the battery lead doesn't drape across the board. sheet 04

### U3 — ESP32-S3-WROOM-1 module

**Where:** antenna end hanging past the board edge (Espressif's strongly-recommended option — the footprint's keep-out zone extends off-board), feed point close to the edge. C9 (22 µF) + C10 (100 nF) at pin 2 (3V3) — this is the module's power entrance, treat those two caps as part of the module. R7 + C8 (the EN reset RC) and R6 (IO0 pull-up) close to their pins on the button side.

**Why:** the antenna is the one component I can't fix after fab. No copper, traces, silk, or ground pour under or beside it on *any* layer; no mounting hardware or standoffs in front of it; ≥15 mm from enclosure walls in the final product. Espressif also wants dense ground stitching vias *around* (never inside) the keep-out, and the module's center pad tied down with its ground vias — the footprint already carries 12.

**Watch out:** keep the UART recovery test points (TP11/TP12) and USB traces away from the antenna end — Espressif calls this out explicitly. Anything that leaves the board (probe cable, battery leads) should exit the *opposite* side from the antenna. sheet 05

### U4 — BME280 temperature / humidity / pressure

**Where:** the coolest corner I have — far from U2, U6, and the module; near a board edge with its metal-lid vent hole open to the air. C11 + C12 (100 nF each) at VDD and VDDIO.

**Why:** it measures *air*, but it sits in a bath of *board* heat; every degree the copper under it warms up is a degree of error and a few % RH of error. Distance plus thin connecting copper is the whole game (Rev B can add slots around it; for Rev A, corner placement is enough).

**Watch out:** never put silkscreen ink or the sensor's vent under another part, and don't wash the board's conformal-coat over it later. Route only its own I2C + power underneath — no warm power trunks below the sensor. sheet 05

### U5 — VEML7700 light sensor

**Where:** top side with an unobstructed view of the sky: no tall neighbours (connectors, module, buttons) shadowing it, and away from D2/D3 so the power/charge LEDs don't leak light into the reading. C13 (100 nF) at VDD.

**Watch out:** in the enclosure, this part needs a window or light pipe directly above it — decide its position together with the case, not after. Keep white silkscreen away from its immediate surroundings to reduce reflections. sheet 06

### J2, Q1, R10/R11, C14 — soil probe input

**Where:** J2 on the bottom/left edge (away from the antenna). Q1 with R10 near the 3V3 side it switches; **C14 goes at the *module's* GPIO1 pin — not at J2**, and R11 rides along with it.

CORRECTED 2026-08-08 These two are **not** "the ADC filter" as a pair — nothing here is in series with the signal, so there is no on-board RC low-pass on ADC_SOIL. They are two parts with two different jobs:

**R11 (100 k) is a pull-down.** When the probe is switched off (SENS_PWR_EN high → Q1 off) or the cable is unplugged, nothing drives ADC_SOIL; without R11 the pin floats and reads noise. R11 holds it at a defined ~0 V, and is weak enough not to load the probe when the probe *is* driving. This is a DC job — **its position is electrically free**; it sits with C14 for tidiness and a shared ground via.

**C14 (100 nF) is the ADC input cap, and its position is not free.** The ESP32's SAR converter doesn't "look at" the voltage — it samples by charging a small internal capacitor (~10 pF) from the pin, so a reading really does draw a brief gulp of charge. C14 at the pin is the local tank that supplies that gulp instantly, and because it is ~10 000× larger than the internal cap it gives up only ~0.01 % of its own voltage doing so (≈0.15 mV — under a fifth of one LSB), refilling from the probe between readings. It also shunts pickup from the on-board trace, which a cap sited back at J2 could not do.

**Why the rest of the rule:** ADC_SOIL is my highest-impedance, most-precious analog signal. Short trace, no neighbours: keep it away from the USB pair, the antenna, and the power zone. Ground pour alongside is good company for it.

**Watch out:** connector pin order is signal / power / ground (matches the DFRobot cable) — the silk should label pin 1, and my bring-up ritual buzzes the cable anyway. **BAT_SENSE (R14/R15 + C17) is the case where "filter" is literally correct:** R14 is in series, so the divider's Thévenin impedance (R14‖R15 = 50 k) against C17 is a real RC low-pass, corner ≈32 Hz. That 50 k is also why C17 *must* be at the pin — a 50 k source is far too weak to fill the ADC's sampling cap in time by itself. Divider near the module pin, short run into GPIO2, away from noisy copper. sheet 04

### SW1 (BOOT) · SW2 (RESET) — buttons

**Where:** a reachable edge, side by side, same orientation, ~8–10 mm apart so two fingers fit. Silk labels **BOOT** and **RESET** (SW1 = BOOT, SW2 = RESET).

**Why:** I verified the tricky part already — the footprint's 1/1/2/2 numbering matches the switch's internal A-B (top) / C-D (bottom) pairing, re-checked against the XKB drawing. The legs exit left and right; give them ~1 mm of clear space (the courtyard nit from Section 2).

sheets 03/07

### D2, D3 — indicator LEDs

**Where:** board edge or top face where they're visible in the enclosure; label **PWR** and **CHG**; away from U5.

**Watch out:** LED footprints are the classic backwards-at-assembly part. The netlist is right (pad 1 = cathode on both); before ordering, open JLC's assembly preview and confirm each LED's polarity dot per Section 7. sheet 08

### TP1–TP12 · H1–H4 — test points and mounting holes

**Where:** flat pads (TP1–TP7, TP9, TP10) anywhere probe-able on the top face — spread near the circuits they measure, ≥2.5 mm apart, silk-labelled. The through-hole trio TP8/TP11/TP12 (GND/TXD0/RXD0 — my UART recovery port) clusters at one edge like a tiny header, far from the antenna. Holes in the four corners; M3 screw heads need ~Ø6 mm of part-free space around each.

**Watch out:** label every TP on silk with its name, not just a number — a numbered pad is useless to whoever probes the board later. Don't let a mounting hole (or its metal standoff) sit inside the antenna keep-out.

## Routing rules for this board

- **Ground first, as a plan:** bottom layer stays as unbroken ground as possible; route on top, drop to bottom only when stuck, and never carve long bottom-layer trenches through the USB or power areas. After routing, pour ground on both layers and stitch them with vias every ~5 mm and at every decoupling cap.
- **Track widths:** power nets (VBUS, +5V_PROT, VSYS, VBAT, VBAT_RAW, +3V3) ≥ 0.5 mm — the net classes from Section 2 handle it. Signals 0.2–0.25 mm. Wider is free; use 0.8 mm on short fat power hops if it fits.
- **USB pair:** D+/D− side-by-side, ~0.2 mm apart, matched in length (within a millimetre is plenty at full speed), zero vias, solid ground underneath the whole run, other signals kept ≥ 0.5 mm away. A 2-layer board can't hit the textbook 90 Ω — "short, coupled, clean reference" is the accepted 2-layer compensation and full-speed USB tolerates it well.
- **Analog (ADC_SOIL, BAT_SENSE):** short, guarded by ground, nowhere near the USB pair, the antenna, or under the module.
- **I2C (SCL/SDA):** route as a pair; relaxed otherwise. The single pull-up pair R8/R9 can live anywhere along the bus.
- **Antenna:** the keep-out is absolute — all layers, copper/traces/silk. Stitch ground generously *around* it, never inside it.
- **Thermals:** U2's pour (Section 4). Zone-to-pad connections: the module's big pad and vias are already set to solid connect in the footprint; leave default thermal reliefs on hand-solderable parts (J2/J3, THT test points) so they stay solderable.
- **Silkscreen pass at the end:** readable reference designators (rotate them, don't delete), polarity marks on D1/D4/D2/D3/J3, pin-1 marks on J2/J3, BOOT/RESET, TP names, and the +/− battery marks. Silk never over pads or the BME280 vent.

## My first hour of layout, in order

1.  **Housekeeping:** the three FIX items from Section 2 (library table, minimum clearance, net classes). Re-run ERC once; it was clean at last save and should stay clean.
2.  **Draw a generous outline** on Edge.Cuts (~52 × 42 mm, 1–2 mm corner radius). I can shrink it at the end — boards grow badly but shrink well.
3.  **Lock the two edge-committed parts:** J1 at its edge with the ~1 mm nose overhang; U3 with the antenna past the opposite (or a side) edge. Press L to lock both so I can't nudge them accidentally.
4.  **Place the chains, not the parts:** protection cluster behind J1 → power zone (LDO + charger + FETs + D4) → module decouplers at pin 2 → sensor corner → connectors on the quiet edges → buttons/LEDs → test points last. Every IC brings its capacitors with it before I move on.
5.  **Stare before routing:** ratsnest lines should look combed, not knotted. Untangle by rotating parts (R), not by planning heroic traces.
6.  **Route in priority order:** USB pair first (it has the least freedom), then power spine (VBUS→F1→D4/charger→VSYS→LDO→3V3 trunk), then analog, then everything else.
7.  **Pour ground both layers, stitch, then DRC** with the JLC-shaped rules. Fix, re-pour, repeat until clean.
8.  **3D-view sanity pass** (Alt-3): connector overhang, button reachability, nothing tall by the USB plug, antenna truly clear.

## Before I order

- Re-run **ERC and DRC** after the final save; both must be clean (or every waiver understood and written down).
- In the JLC/kicad-jlcpcb-tools preview, check **rotation and polarity of every polarized part**: D1, D4, D2, D3, U1–U6, J1, SW1/SW2. JLC's part rotations sometimes differ from KiCad's by 90°/180° — the preview render is the truth. LEDs are the classic victim.
- Confirm **C3/C4 stay DNP** (off the BOM and placement file) and the 12 TPs + 4 holes are excluded as intended.
- **Re-verify stock and Basic/Extended status** at upload (my BOM notes the 10 k alternate C98220). Library status is a live value.
- Freeze the ordered files into `fabrication/revA/` per my README, and push the git commits — PROJECT_STATUS still lists the milestone commit as unpushed.

## What was checked, and how

Parsed from disk (not screenshots): all 8 schematic sheets, `ESP32S3_PlantMonitor.kicad_pcb` (post-F8: 69 footprints, 228 pads, nets assigned, no tracks/outline yet), `ESP32S3_PlantMonitor.kicad_pro` (rules & classes), `fp-lib-table`, and all six `PlantMonitor_JLC.pretty` footprints (confirmed byte-equivalent in geometry to the copies embedded in the board — no stale imports). Datasheets measured: HRO TYPE-C-31-M-12 footprint drawing · XKB TS-1187A drawing (pad layout + internal pairing) · Vishay VEML7700 Rev 1.8 p.10 · MDD SS12–SS1200 p.3 (SMA pads) · Goodwork SMF series p.5 (SOD-123FL pads) · Littelfuse 1206L p.4 · Microchip MCP73831 p.24 (OT land pattern) · Diodes AP2112 p.14 (SOT-25) · ST USBLC6-2 p.13 (Fig 19) · Bosch BME280 Rev 1.24 pp.42–43 (Fig 21) · Espressif ESP32-S3-WROOM-1 v1.8 pp.42–45 (Fig 10-1/11-1) · Espressif Hardware Design Guidelines §1.4.7–1.4.8 (module placement, antenna keep-out, USB) · JST PH family sheet · AOS AO3401A Rev 3.1 (no land pattern published; generic SOT-23 applies). Pad→net mapping verified for every IC, diode, LED, connector, switch, and FET against datasheet pinouts. Prior project reviews (2026-07-20, 2026-07-22) incorporated, not repeated.

First-PCB project · this document lives at `docs/Layout_Readiness_and_Placement_Guide_RevA.md`.

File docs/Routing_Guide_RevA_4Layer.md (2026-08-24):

# Routing Guide — ESP32-S3 Plant Monitor Rev A, 4-Layer
*Written 2026-08-12 against the saved board file (placement v3: J1 nose overhang now 0.96 mm ✓, TP10 placed at (83, 92) ✓, TP1–TP7/TP9 still parked, SCL/SDA still on pins 4/5, board file still 2-layer — Section 0 converts it). Stack: **L1 signal · L2 GND · L3 GND · L4 signal.** Companion to `Hard_Rules_Layout_RevA.md`; where a LAW number appears, that's the rule being applied.*

---

## 0 · Setup — do these before the first track

**0.1 Convert the board to 4 layers.** Board Setup → Physical Stackup → set copper layers to 4. Rename `In1.Cu` → `GND1` and `In2.Cu` → `GND2` so I never mistake them for routing layers. Enter JLC's standard 4-layer stack (JLC04161H-7628 — verify at jlcpcb.com/impedance): F.Cu **0.035** · prepreg 7628 **0.2104** (εr 4.4) · GND1 **0.0152** · core **1.065** (εr 4.6) · GND2 **0.0152** · prepreg **0.2104** · B.Cu **0.035** — the "board thickness from stackup" readout should land at ≈1.60 mm. That 0.21 mm prepreg is the star of this whole document: every trace on an outer layer now has a ground plane a fifth of a millimetre away.

**0.2 Create the two plane zones immediately.** Add a zone on GND1, net `GND`, covering the whole board; same on GND2. Solid fill, clearance 0.3, min width 0.25 mm, pad connection **thermal reliefs**, remove islands (same numbers as `KiCad_Settings_RevA.md` §9). Fill them now — from the first track I route, the planes are already real, and KiCad will show me if I ever accidentally cut them.

**0.3 Vias.** Keep my 0.6/0.3 default everywhere; 0.45/0.2 is a comfortable smaller size that stays well inside JLC's 4-layer capability if I'm ever squeezed. **Through-hole vias only** — blind/buried vias exist but jump me into a different (expensive) process for zero benefit here.

**0.4 Impedance control: not needed.** The ESP32-S3's native USB is Full Speed (12 Mbit/s) — it tolerates ordinary traces. Order the board as plain 4-layer, "impedance control: no". (If I ever carry this stackup to a High-Speed design, JLC's calculator gives me the 90 Ω pair geometry; at FS my 0.25/0.2 USB class is fine as-is.)

**0.5 Finish the pre-routing edits while edits are still free:**
- Place the remaining eight test points (table in `Placement_Review_RevA_2026-08-12_v2_status.md` — still valid; my TP10 spot at (83, 92) checks out, feed it with a spur from R6).
- Decide the SCL/SDA re-pin (IO38/IO39) **now** — it's a schematic edit + F8, and F8 after routing means ripping up tracks.
- Lock J1 and U3 (H1–H4 already are).

---

## 1 · The one idea that makes a 4-layer board work: return current

Every signal is a **loop**. Current leaves a pin, travels down my trace, and *must come back* — and at any speed above DC it comes back through the ground plane **directly underneath the trace**, hugging its shadow, because that's the lowest-inductance path. My job when routing is really to route the *loop*, not the trace. On this stackup the return path is 0.21 mm below every trace I draw, which is why 4-layer boards feel like cheating after 2-layer: loop areas shrink ~10×, and with them noise, EMI, and crosstalk.

Everything below falls out of that one idea:

1. **Never route on GND1/GND2.** One trace on an inner layer carves a trench through someone else's return path (LAW 19's "no trenches", now applied to two layers). The planes are load-bearing infrastructure, not spare room.
2. **L1 is home; L4 is the escape hatch.** All parts are on top, so a trace that stays on L1 needs zero vias and references GND1 its whole life. Drop to L4 only to cross something I can't untangle — and come back up.
3. **When a signal changes layers, its return current must change planes too.** The signal via carries the signal from L1 down to L4; the return, which was flowing on GND1 under the old segment, now needs to flow on GND2 under the new one — and the only way current moves between two planes is through a ground via. How much this matters scales with signal speed: **for fast edges (the USB pair, if it ever changed layers) a companion GND via within 1–2 mm is important; for slow nets (I²C, EN, IO0, LEDs, SENS_PWR_EN, charger STAT) it's optional** — their return currents happily spread through the next stitching via a few mm away. In practice my ~5 mm stitching grid means most layer changes get a nearby ground via for free anyway; think of the companion via as mandatory for fast signals and free-but-unnecessary insurance for slow ones.
4. **A solid plane can't be crossed wrongly.** There are no splits to straddle because both planes are pure GND — one of the two reasons GND/GND beats the old signal/GND/power/signal stack. The other: my L4 traces get a real reference too, not a patchy power plane.

**What this retires from my 2-layer rulebook:** LAW 6's "nothing on the bottom layer under the USB pair" is now automatic — there are two solid planes between the pair and L4, so routing under it on L4 is harmless. LAW 19/20/21 now read: *planes stay solid, GND is never a trace, stitch the outer pours to the planes.* Everything else in the rulebook stands unchanged.

---

## 2 · Layer plan for this board

| Layer | Job |
|---|---|
| **L1 (F.Cu)** | ~95 % of all routing: the USB pair (entire run), all power, all analog, most signals. GND pour over the leftovers at the end. |
| **L2 (GND1)** | Solid ground. Nothing else, ever. |
| **L3 (GND2)** | Solid ground. Nothing else, ever. |
| **L4 (B.Cu)** | Full routing layer for anything that's cleaner down there — SENS_PWR_EN crossing the board middle, I²C or LED/EN legs where they'd knot on top. Electrically it's first-class (solid GND2 reference at 0.21 mm); prefer L1 only for *workflow* reasons — every part's pads are on top, so L4 costs two vias per visit. A clean L4 route beats a tangled L1 route. GND pour over the leftovers. |

Keep a mental budget: if a net needs more than one trip to L4 and back, rotate a part or rethink the path instead (my guide's old advice stands — untangle with `R`, not heroics).

---

## 3 · Routing order — nets with the least freedom first

**3.1 USB, first and complete.** The pair owns its corridor before anything else claims it.

- *The crossover at J1* (the pads run B7 D− · A6 D+ · A7 D− · B6 D+, interleaved). **Corrected 2026-08-12:** an earlier revision claimed one layer-hop was topologically forced here. That's wrong — it's only forced if both ties *and* both exits stay on the board side of the pad row. Route around the row instead and the whole breakout stays on L1, zero vias (verified against this footprint at my 0.2 mm clearance — all lanes clear by 0.25 mm):
  1. Tie **B7 → A7 (D−)** *behind* the pad row, between the pad toes and the shell — the span (y 76.75–77.75) clears both Ø0.65 peg holes (y 74.61 / 80.39).
  2. Tie **A6 → B6 (D+)** *in front*: from A6's toe, arc right past A7's toe (apex x ≈ 41.8 — 0.4 mm short of U1's courtyard) and into B6's toe.
  3. Exit **D− rightward from B7's lane (y ≈ 76.75)** and **D+ from B6's lane (y ≈ 78.25)**. Each lane clears the neighboring pads by 0.25 mm, and the two lanes land almost exactly on U1's pin 1 (76.55) and pin 3 (78.45) — they flow straight into the ESD chip.
  These first ~2 mm run as two parallel traces ~1.5 mm apart rather than a tight pair — at Full Speed that is completely irrelevant. The tight coupled pair begins at U1's output side. *Fallback only if this fights me in practice:* one ~1.5 mm hop to L4 for the B6→A6 tie, via pair plus a companion GND via — acceptable, but the all-L1 version is cleaner and now known to fit.
- *The run:* A6/A7 → U1 pins 1/3, out pins 6/4 → R1/R2 → module pins 13/14. Route with the differential-pair tool (it will engage now that the nets are named `…DP/…DN`), **all on L1**, side-by-side at 0.25/0.2, matched within a millimetre (that's generous at FS), no further vias, other copper ≥ 0.5 mm away. The corridor from U1 to R1/R2 passes below the LED cluster — route it before the LED lines exist.

**3.2 VBUS in copper order (LAW 7).** J1's VBUS pads → **D1 first** → F1 → onward as +5V_PROT. 0.5–0.8 mm wide, stubs measured in millimetres — the TVS only protects what sits *behind* it in copper, and every millimetre of stub to D1 is ~0.6 nH of clamp delay. Tap C1 off at U1's pin 5, drop C2 right after F1. Then R3/R4 CC drops: short stubs to the CC pads, other ends straight to ground vias.

**3.3 The power spine.** All on L1, ≥ 0.5 mm (the Power class enforces it), wider (0.8 mm) where it's short and easy:

- **+5V_PROT:** from F1 two branches — south-east along the board bottom to C15 → U6 VDD, and north to D4's anode, with the R16/Q3-gate spur off it.
- **VSYS (LAW 13):** the hand-over node — D4 cathode, Q3 source, C18, C5, C6, into U2 VIN. Keep it the fat, compact star it already is in placement; this is the one net where "wide and short" is the entire spec.
- **+3V3:** out of U2 through C7, then **flow past the caps into the pin** (STRONG 33): trunk east along the top to C9 → C10 → module pin 2 — the supply enters the big cap, then the small cap, then the pin, in that order, as one continuous path rather than caps hanging off stubs. Second branch south-east to the sensor corner (R8/R9, C13/U5, C11/C12/U4), with spurs to R5, R7, R6, R10, Q1.
- **VBAT:** J3 pin 1 → Q2 → C16 → U6 VBAT (already a straight line in placement), plus the sense tap north along x ≈ 80 to R14. 

**3.4 Analog (LAW 18).** The quiet pair, routed while the board is still empty enough to give them space:

- **ADC_SOIL:** J2 pin 1 → past my TP6 → up the right side → C14's pad → pin 39. Solid plane under it the whole way (free now), ≥ 0.5 mm from power trunks, nowhere near the USB corridor or the top-edge strip.
- **BAT_SENSE:** R14/R15 junction → C17 → pin 38 — 4 mm total. The divider's VBAT feed routes as ordinary power.

**3.5 Slow signals** — EN (R7/C8 → pin 3, spur to SW2 and TP9), IO0 (R6 → pin 27, spurs to SW1 and my TP10 at (83, 92)), SENS_PWR_EN (pin 23 → Q1's gate — fine to hop to L4 to cross the middle; companion via), SOIL_PWR (Q1 → J2 pin 2), I²C (pins 38/39 → R8/R9 → both sensors; route SCL/SDA loosely as a pair for tidiness — electrically relaxed at 100–400 kHz), LED lines (R5 → D2, R12 → D3 ← U6 STAT — long and slow, route them last through whatever's left), UART (pins 36/37 down the right side and west along the lower board to TP11/TP12 — LAW 34: the path matters, the length doesn't), R13 PROG.

**3.6 GND — the net I don't route.** The pads where a dedicated via *at the pad* is required (LAW 12 plus the heavy hitters): **all ~20 decoupler ground pads** (C1–C18's GND ends — this is the one Espressif calls out explicitly), U1 pin 2 (ESD strikes need the shortest possible path into the planes), the LDO and charger grounds (thermal + return), J1's four shield holes *and* its GND pads (they take the cable yank — solid ties), and TP7/TP8. The module's centre pad already carries its 12. Truly trivial grounds — the 100 k pull-down ends (R11, R15's bottom), R13's ground end, the switch ground pads — don't *need* personal vias; letting them join a well-stitched L1 pour is fine. A via there is still free and harmless, so don't agonize — the only real rule is: never let a trivial pad's only connection be a long skinny pour neck (DRC's unconnected check plus a glance at the filled pour catches this). On this stackup each of those vias is a ~0.25 mm hop to the plane — my decoupling loops land well under 5 nH (pocket-number target: <5 nH = good) almost by default. This is the payoff of the whole 4-layer decision.

**3.7 Pours and stitching.** After routing: GND pour on L1 and L4, then stitch — every decoupler already has its via; add a **perimeter fence** of GND vias around the board edge (~3 mm pitch along the antenna-end edge, ~5 mm elsewhere), vias tying the L1 pour down wherever it forms islands or long peninsulas (LAW 21's ~5 mm grid), and the ring **around** the antenna keep-out — never inside it (LAW 3). With the antenna fully overhanging, the on-board keep-out is automatically satisfied; the fence along that top edge is my RF hygiene.

**3.8 Cleanup.** Refill zones → DRC → fix → repeat until clean; delete dead islands; then the silkscreen pass (LAW 27: +/− at J3, cathode marks, pin-1 marks, BOOT/RESET, TP names by function, nothing on pads or the BME vent).

---

## 4 · Via craft

- **One size fits this board:** 0.6/0.3 for everything. Drop to 0.45/0.2 only where geometry forces me.
- **Fast-signal via ⇒ companion GND via** within 1–2 mm (Section 1). Slow-signal vias can lean on the stitching grid; layer-hop clusters share one companion.
- **Power layer-hops get doubled vias** (STRONG 39) — a 0.3 mm drill is good for over an amp, so this is hygiene, not necessity, at my ≤ 500 mA.
- **No via-in-pad** — a via inside a solder pad drinks the solder down its barrel during reflow and starves the joint. The module's thermal pad is the designed exception (its paste windows account for it).
- **Don't perforate the planes:** a tight row of vias is a perforated tear line — the antipads merge into a slot that blocks return current. Keep ≥ 0.5 mm between barrels and stagger rows. Ten scattered ground vias beat ten in a line.
- **Tent everything** (default): mask over via = no accidental shorts under probe clips. Test *points* are pads, not vias — they stay open by design.
- **Teardrops** (Edit → Fill/Teardrops): optional; mildly nicer for 0.3 mm drills on 0.25 mm traces. Fine to skip.

---

## 5 · Power and heat on four layers

The LDO's pour plan improves for free: L1 copper on its GND pin, 4–6 vias, and now those vias land in **two full-board copper sheets** — a far better heatsink than the 2-layer plan for its ~0.26 W worst case. Same for the charger's ~0.2 W. Keep both pours generous.

The flip side, worth knowing: solid planes conduct heat *everywhere*, including toward the BME280. Distance is still my tool (it's 33–45 mm from all three sources) and the planes also *dilute* hot spots, so the net effect at my power levels is a small, roughly uniform rise — expect the BME280 to read maybe a degree high during long Wi-Fi sessions. Don't slot the Rev A planes for it (plane integrity is worth more); characterize the offset at bring-up with the thermocouple step my review already prescribes, and correct in firmware. Rev B can add thermal slots if the data says so.

---

## 6 · KiCad zone mechanics

Four zones total: GND on L1, GND1, GND2, L4. Same net, so priorities don't matter. Settings that matter:

- Clearance 0.3 / min width 0.25 / **remove islands: below area limit** (kills orphan slivers automatically).
- Pad connection: **thermal reliefs** — critical for J2/J3 and the THT test points, because a pin welded straight into two internal planes is a heat sink my iron can't win against (LAW: hand-solderable stays hand-solderable). SMD decoupler pads work fine through their adjacent via regardless. The module pad's solid connection is set inside the footprint and overrides the zone — leave it.
- **Refill before every DRC** (`B`) — zones don't refill themselves, and DRC on stale fills lies to me.
- Pour L1/L4 *after* routing, not before — routing through existing pour means every edit re-triggers fill churn.

---

## 7 · Interactive routing, practically

Work in **shove mode** (Route → Interactive Router Settings → Shove) — it nudges finished tracks aside instead of blocking me. `X` route, `V` drop a via mid-route, `/` swap posture, `D` drag to tidy, `E` set width mid-route. Highlight-collisions mode is for experts having a bad day; shove is for making progress.

Rhythm that keeps me sane: route one section from §3's list → refill → quick DRC → commit to git. DRC every half hour, not at the end — a clearance error found early is a nudge; found at the end it's an excavation. Lock the USB pair and the VBUS chain once they're perfect so shove can't disturb them. And if the ratsnest looks knotted in some corner, stop routing and stare — the fix is almost always rotating a part (recheck its courtyard gaps after; I have pairs at 0.015 mm that predate me adding breathing room).

Two habits from the pros: color my critical nets (right-click net in the Nets panel → color) so USB/VSYS/analog read at a glance; and when a trace fights me for the third time, delete it and come from the other end — traces routed *from* the fussy pad outward almost always land cleaner.

---

## 8 · Definition of done

Routing is finished when: unconnected items = **0** · DRC = **0** with the real constraint values (no waivers I can't explain in one sentence) · all four zones filled, stitched, no orphan islands · every GND pad has its via · every signal via has a companion · antenna end visually clean with its fence · 3D view pass (connector overhangs, nothing tall by the plug, button reach) · silk pass done · then the pre-order gauntlet from the placement review stands: JLC assembly preview for every polarized part, C3/C4 + TPs + holes excluded from BOM/placement, live stock re-check, **order as 4 layers, stackup JLC04161H-7628, impedance control "no"**, freeze into `fabrication/revA/`, commit, push.

---

## 9 · Advanced corner cases (know these exist; most won't bite)

- **Acute angles & slivers:** never let two traces meet below 90°, and don't leave copper slivers thinner than ~0.2 mm between pours and pads — etchant pools in acute wedges ("acid traps"). 45° habits (STRONG 38) prevent all of it.
- **Annular ring math:** my 0.6/0.3 via leaves (0.6−0.3)/2 = 0.15 mm of ring — exactly the minimum my own DRC enforces (`min_via_annular_width 0.15`). That's why I never shrink the pad while keeping the drill.
- **Mask slivers at the USB pads:** the 0.5 mm-pitch middle pads leave ~0.2 mm mask webs — at JLC's capability, fine; don't add mask expansion there.
- **Plane pullback at the edge:** my 0.5 mm copper-edge rule (LAW 23) applies to the inner planes too — KiCad's zone clearance handles it; just don't override it to zero.
- **Silk discipline:** silkscreen over a via gets drilled into confetti and over a pad gets scraped off — DRC's "silk over pads" check catches it; run it.
- **Fiducials:** JLC's assembly doesn't require board fiducials at prototype scale (they use panel marks). Skip for Rev A.
- **The corner arcs:** copper and courtyards must respect the R4.25 arcs, not the old rectangle corners — the 0.5 mm edge clearance follows the arc. KiCad measures to the actual outline, so trust DRC, not my eyes.
- **Don't chase prettiness into risk:** a routed, DRC-clean, slightly ugly board beats a beautiful one I re-ripped four times. Rev A's job is to work and to teach; Rev B gets to be pretty.

---

*Board state measured from disk, not screenshots · LAW/STRONG references are to `Hard_Rules_Layout_RevA.md`, which remains in force except where Section 1 explicitly retires the 2-layer-specific mechanics.*

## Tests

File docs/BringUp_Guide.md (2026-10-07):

# Bring-Up Guide — ESP32-S3 Plant Monitor Rev A
*Replaced the original bring-up checklist PDF on 2026-07-20 (it referenced test points and a soil divider that no longer exist); that PDF was retired. Designators match the schematic, not the design doc.*

**Bench kit:** multimeter, current-limited USB source if available (set ~700 mA), oscilloscope (needed for step 9), the buzzed-out probe cable, a metered battery.

---

## 0. Rules before anything touches the board

1. **Battery polarity ritual (non-negotiable).** Meter the pack's plug before it ever meets J3: pin 1 = positive, pin 2 = GND. LiPo pigtails have no color standard, and PKCell packs have shipped with "reversed" plugs relative to JST convention.
2. **The charge LED does NOT prove polarity.** With USB plugged in and a *reversed* battery, the charger's precondition current turns the reverse-protection FET on and trickles ~10 mA backwards into the cell — while D3 glows a steady, normal-looking "charging." Reverse protection is only complete with USB absent. Meter first, always.
3. **Protected cells only** (pack must contain a PCM). The board has no protection IC of its own.
4. **Never store the board with a flat battery plugged in.** Sleep floor is ~210 µA; a 500 mAh cell hits the PCM's 2.5 V cutoff in ~100 days, and the PKCell spec lists 0 V-recovery charging as *Unavailable* — a fully dead cell is scrap.
5. Charge only between 0–45 °C (pack spec).

## 1. Quirks to keep in mind (what's "normal" for this board)

* **USB-unplug hand-over (the R16 story).** Q3 (battery switch) is held OFF by its gate sitting on the +5V_PROT rail, which carries ~14.7 µF of capacitance. When USB is pulled, that stored charge keeps Q3 off while the board is fed through Q3's *body diode* at a 0.65 V penalty — with the original 100 k pull-down this lasted 0.5–1 s, dropping the 3.3 V rail to ~2.9–3.1 V on a mid-charge battery and tripping the ESP32-S3's ~2.98 V brown-out reset. **R16 is now 10 k (changed 2026-07-20)**, shrinking the window to ~50–100 ms, which the VSYS capacitors and the brown-out margin ride through. Cost: 0.5 mA extra draw from USB only (5 V ÷ 10 k), zero on battery. *Step 9 verifies this on real hardware.*
* **Power LED (D2) is deliberately dim.** 10 k series resistor ⇒ ~120 µA. Faint in daylight is expected. It is also the single largest sleep-mode drain — unsolder it for battery-life measurements.
* **Charge LED (D3) flickers faintly with no battery connected.** Charger STAT pin tri-states; cosmetic, expected.
* **BAT_SENSE lies when USB is present with no battery:** the charger floats VBAT to ~4.2 V, so the ADC reads "full battery." Firmware should gate battery-% reporting on USB absence.
* **LDO gets warm on USB during sustained Wi-Fi** (~0.26 W). Fine for bursts; watch it during long OTA sessions (thermal shutdown at ~160 °C protects it).
* **Firmware must enforce two battery thresholds** (the hardware only *reports*):
  * **~3.5 V — stop transmitting.** Regulator rule: the AP2112K needs ~0.2 V headroom to hold 3.3 V during a 355 mA TX peak. Sensors + sleep still fine below this.
  * **3.0 V — deep sleep, stop everything.** Battery rule (PKCell discharge floor). The pack's own PCM doesn't trip until 2.5 V — that half-volt gap is firmware's responsibility.

## 2. Probe points (TP1–TP12 fitted 2026-07-22; backup pads for tight spots)

| Net | TP | Backup pad | Net | TP | Backup pad |
|---|---|---|---|---|---|
| +5V_PROT | TP1 | C2 (+) / F1 pin 2 | BAT_SENSE | TP5 | C17 (+) |
| VSYS | TP2 | C5 / C18 (+) | ADC_SOIL | TP6 | C14 (+) / R11 top |
| +3V3 | TP3 | C7 / C9 (+) | EN | TP9 | C8 / R7 junction |
| VBAT | TP4 | C16 (+) | IO0 | TP10 | R6 / SW1 junction |
| GND | TP7, TP8\* | USB shell / J3 pin 2 | TXD0 / RXD0 | TP11\*, TP12\* | — (module pins 37/36) |
| USB_VBUS | — | C1 (+) | | | |

\* Through-hole 1.0 mm pads — a header pin or DuPont jumper end fits and holds. **Recovery UART / early-boot logs:** adapter TXD→TP12 (RXD0), adapter RXD→TP11 (TXD0), GND→TP8; 115200 baud; to flash, hold BOOT (SW1) and tap RESET (SW2). 3.3 V logic only — never connect an adapter's 5 V / 3V3 power pins.

## 3. Sequence

**A — no power**
1. Visual: orientation of U1–U6, D1–D4, Q1–Q3; no bridges; polarity marks.
2. Meter resistance GND↔ each of +5V_PROT / VSYS / +3V3 / VBAT: no shorts (all ≥ kΩ-range and climbing as caps charge).

**B — USB only (no battery)**

3. Plug USB. Expected: **USB_VBUS ≈ 5.0 V · +5V_PROT ≈ 4.87–4.96 V · VSYS ≈ 4.45–4.65 V · +3V3 = 3.30 V**. Power LED faintly on. Input current at idle: tens of mA.
4. Board enumerates as a USB serial device; flash a hello/blink build. (Native USB — no bridge chip. If it won't enumerate: try another cable, check D+/D− aren't swapped at U1, re-check the J1 GND-pin fix.)
5. I²C scan finds **0x76** (BME280) and **0x10** (VEML7700).
6. Read all sensors; sanity-check values.

**C — battery**

7. **Meter the pack plug** (rule 0.1), then connect at J3 with USB still in. Charge LED on; VBAT (C16) climbs toward 4.20 V; charge current ≈ 90–110 mA (my as-received cell measured 3.95 V, so expect a shortish CC phase then taper).
8. BAT_SENSE = VBAT ÷ 2 (±1 %). Firmware reading ×2 should match the meter at C16.
9. **Hand-over test (scope).** Battery at ~3.7–3.9 V for a worthwhile test. Scope on VSYS (TP2; C18 (+) works too), trigger single, ~50 ms/div. Pull USB.
   * **PASS:** VSYS steps down and rides at ≈ VBAT − 0.65 V for **≤ ~100 ms**, then snaps up to ≈ VBAT and stays; board keeps running, no reset, +3V3 never drops below ~3.0 V.
   * **FAIL (old behavior):** the notch lasts ~0.5–1 s and the board reboots → R16 isn't the 10 k part, or the gate node has extra capacitance.
10. Battery-only cold boot: unplug USB, press reset (SW2) — board must boot and run from battery alone.

**D — sensors, sleep, soak**

11. Buzz out the probe cable, plug into J2. Power the probe from firmware (GPIO21 LOW), wait ≥ 200 ms, read. Record **dry (in air)** and **in water** raw values; breadboard reference (direct, no divider, 12 dB attenuation): **wet ≈ 1465, dry ≈ 2900 counts (~1.1 V / ~2.2 V)**. On-board values should land close; re-record them as the board's calibration constants.
12. Sleep current in series with the battery: expect **~210 µA** as built (D2 120 µA + LDO 55 µA + divider 21 µA + ESP32 ~10 µA), or **~90 µA with D2 removed**.
13. Wi-Fi range sanity check, then a 24 h soak: charge behavior, readings every wake, no resets (check reset-reason register in logs).

## 4. Troubleshooting quick table

| Symptom | First suspects |
|---|---|
| No enumeration | Cable (try several), J1 GND pins, D+/D− continuity through R1/R2, drivers |
| Resets when USB unplugged | R16 value (must be 10 k), battery too low, scope the VSYS notch |
| Charge LED never lights | Battery polarity (meter it!), R12/D3 orientation, VBAT wiring |
| Charge never terminates | Load on VBAT during charge shouldn't exist on this design — check Q3 isolation (Vgs at USB-present should be ≈ +0.4 V) |
| ADC values noisy | Average 8–16 samples; keep probe leads short; confirm C14/C17 fitted |
| BME280 missing at 0x76 | SDO must be at GND; check CSB at 3V3 |
| LDO very hot | Sustained TX on USB is the worst case (~0.26 W) — airflow/copper; brief is fine |

## 5. Record sheet

### Board #1 — 2026-09-08 (session in progress)

**Pre-power resistance checks (rail ↔ GND, meter in Ω mode).** Not in the original sequence — added this session because the values are derivable from the board file and one of them verifies R16 without a scope.

| Item | Expected | Derivation | Measured | Pass |
|---|---|---|---|---|
| +5V_PROT ↔ GND | ≈ 10 kΩ | R16 is the only resistive path on the rail — **this reading _is_ the R16 value check** | in range | ✅ |
| VSYS ↔ GND | MΩ / OL | no resistor on the net; D4 and Q3 both reverse-biased, U2 below startup | in range | ✅ |
| +3V3 ↔ GND | MΩ (range-dependent) | R5's path is blocked by D2 in series (LED sub-threshold) | in range | ✅ |
| VBAT ↔ GND | ≈ 200 kΩ | R14 + R15 in series — pre-validates the BAT_SENSE divider | in range | ✅ |

**Visual inspection (step 1):** all clear. C3/C4 correctly unpopulated (DNP), U1 at 45° as designed.

### Main sheet

| Item | Expected | Measured | Pass |
|---|---|---|---|
| +5V_PROT (USB) | 4.87–4.96 V | in range | ✅ |
| VSYS (USB) | 4.45–4.65 V | in range | ✅ |
| +3V3 | 3.30 V ± 2 % | in range | ✅ |
| Q3 V_GS, USB present | ≈ +0.4 V (Q3 off, battery path isolated) | in range | ✅ |
| Charge current | 90–110 mA | | |
| VBAT at termination | 4.168–4.232 V | | |
| BAT_SENSE ÷ VBAT | 0.50 ± 1 % | | |
| Hand-over notch | ≤ ~100 ms, no reset | | |
| Soil dry / wet raw | ≈ 2900 / ≈ 1465 | | |
| Sleep current | ~210 µA (~90 µA no LED) | | |
| I²C scan | 0x76 + 0x10 | **both found** — BME280 0x76, VEML7700 0x10 | ✅ |

### Sensor readings, board #1, 2026-09-08 (USB only, no battery, no probe)

| Reading | Value | Note |
|---|---|---|
| Temperature | 26.42 → 26.62 °C over ~30 s | Rising then flat — U4 self-heating, as expected |
| Humidity | 50.5 % → settles 45.6 % | Falls as the die warms; see observation 1 below |
| Pressure | 1019.2 hPa, ±0.03 | Rock steady. Best evidence the I²C bus is clean |
| Light | ~145 → ~167 lux, ±3 | Room light, sensible response |
| Soil raw | 0 | Correct — nothing in J2, R11 pulls the input down |
| BAT_SENSE | 2411–2453 raw, **cycling** | Not static. See observation 2 below |

**Observation 1 — humidity falls during warm-up, and that is physics, not drift.**
Relative humidity is temperature-dependent. As U4 self-heats ~0.2 °C the air at the
die holds more moisture at saturation, so the same absolute humidity reads as a lower
percentage. The 5-point drop from 50.5 % to 45.6 % settles as the die reaches thermal
equilibrium. Consequence: **this board reads humidity slightly low**, and the offset
is proportional to the self-heating. Worth a fixed correction in firmware, and worth
noting that the LDO's proximity to U4 sets the size of it (Rev B placement item).

**Observation 2 — BAT_SENSE is not static with no battery fitted. Mechanism corrected 2026-09-09.**

*First analysis was wrong and is kept here as a warning.* It claimed a ~12–13 s charge/terminate
cycle, read straight off the serial log. **That period was an aliasing artifact.** The sketch samples
BAT_SENSE about every 1.25 s, and sampling a fast oscillation slowly produces a convincing but fake
slow beat. The physics rules 12 s out: the only load on VBAT with no cell is the R14/R15 divider
(~21 µA at 4.2 V), and 21 µA draining C16's 4.7 µF across a 70 mV window takes roughly **16 ms**, not
6 seconds. Lesson: do not read a frequency off a log sampled near that frequency.

*Real mechanism.* The MCP73831 has **no battery-detection circuit at all** — it never looks for a
battery and is never "confused." It just runs its fixed routine: push 100 mA until 4.2 V, hold, declare
complete when current falls below ~7.5 mA (7.5 % of the 100 mA that R13 programs), auto-recharge when
the voltage later sags. With a 500 mAh cell each stage takes tens of minutes. With only C16's 4.7 µF to
fill and a 21 µA leak through the divider, the identical routine completes in milliseconds and repeats
forever. **The divider is the leak that makes it repeat** — without it the charger would top up once and
stay terminated.

*D3's brightness is the duty cycle, and it is a usable field indicator.* Confirmed on hardware 2026-09-09:

| D3 appearance | State |
|---|---|
| Dim but lit, no visible blink | Fast cycling on an empty node — STAT low only part of the time |
| **Full bright, steady** | Continuously charging a real cell — STAT held low |
| Off | Terminated, or no USB |

So §1's "flickers faintly" wording is right; its *explanation* (STAT tri-states, cosmetic) is not the
whole story. The exact on/off ratio is still unmeasured — **scope BAT_SNS with the cell disconnected**
to settle it. D3 still proves nothing about polarity: rule 0.2 stands unchanged.

Neither observation affects pass/fail. Both are recorded because the firmware gates
battery reporting on USB absence anyway, so the cycling is invisible in normal use.

> **Rail voltages logged as "in range" — exact figures not captured at the bench.** Worth recording real numbers on the remaining four boards: unit-to-unit spread on +3V3 and on D4's drop (+5V_PROT − VSYS) is the kind of baseline that makes a Rev B decision easy later.

**Observation 3 — step 11's "buzz out the probe cable" caught a real fault, and the failure has a specific signature worth knowing.**
The J2 cable was wired **reversed**: board SIG → probe GND, board GND → probe analog out. VCC was
unaffected, because on a 3-pin connector reversed end-for-end **the middle pin maps to itself** — which is
exactly why this is easy to miss and easy to dismiss.

*Signature:* soil reads a **high, constant, unresponsive** value (~2973–2981 here), not a dead one. The probe
still powers up, so the number looks plausible — it just never moves. Mechanism: the probe's ground return
lands on ADC_SOIL and has to reach ground through R11's 100 kΩ, which pins the node near the top of the ADC
range. Contrast with **no probe fitted**, which reads a clean 0.

*No damage.* Everything stayed within 0–3.3 V (nothing on that connector is fed from higher), the probe was
never reverse-powered thanks to the middle-pin property, and R11 limited current to microamps. Verified after
the fix: probe responds normally.

**Step 11 in progress — first readings after the cable fix, not yet calibration-grade:**
probe resting on a desk read ~2265, wet hands read 1209–1911. Neither is valid: a desk has a far higher
dielectric constant than air (biases "dry" low), and a hand couples its own capacitance into the blade
(hence the ~700-count swing). **Calibration must be taken blade-in-free-air and submerged-in-water, hands
off both times.** Also note `sensor_check.ino` takes a *single* ADC sample for soil where `config.h` assumes
16 — average before recording.

**Deferred — gear not on the bench 2026-09-08:** steps 7–10 (battery), step 9 (scope), step 11 (soil probe), step 12 (sleep current). Multimeter-only fallback for step 9: pull USB and read the reset-reason register in the logs — gives pass/fail on the brown-out without measuring notch width.

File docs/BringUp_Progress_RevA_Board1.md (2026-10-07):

# Bring-Up Progress — Rev A, Board #1

*Living status doc. Started 2026-09-08, last updated 2026-09-13.*
*Companion to [`BringUp_Guide.md`](BringUp_Guide.md) — the guide is the procedure, this is where board #1 actually got to.
Detailed measurements and the numbered observations live in the guide's §5 record sheet.*

---

## RESUME HERE

**State as of 2026-09-13.** Step 11 is closed — real dry/wet numbers taken on this probe and cable, and
`config.h` updated. The board has since run an 11-hour battery soak (249 wake cycles, no resets) and now
runs the full cycle on a 30-minute interval, publishing to ThingSpeak channel 3492276. Steps 9 and 12
are the outstanding ones and both still need gear that is not on the bench.

The note below was written 2026-09-09 and the procedure is still correct, but **the cell is no longer in
the 3.7–3.9 V window the test wants** — it will have to be caught mid-charge again, or run down.

**Board is charging, cell is at ~4.0 V and climbing. The next action is step 9, and it is time-sensitive.**

Step 9 wants the battery at **3.7–3.9 V**, because the notch bottoms at roughly VBAT − 0.65 V and the test
only means something when that lands near the LDO's limit. At 4.2 V the notch bottoms around 3.55 V and
proves nothing. Every minute on the charger makes the test weaker.

**The trap:** the only way to stop charging is to pull USB, and *pulling USB is the step 9 event itself*.
There is one clean shot per charge state. So:

1. Scope probe on the pad marked **`VSYS`**, ground clip to **`GND`**. DC coupled.
2. ~50 ms/div, single-shot trigger, falling edge, level a few hundred mV below the resting VSYS (~4.7 V).
3. Serial monitor open so the reset reason is visible afterwards.
4. **Then** pull USB.

**PASS:** VSYS steps down to ≈ VBAT − 0.65 V, rides there **≤ ~100 ms**, snaps up to ≈ VBAT and stays.
Board keeps running, no reset, `3V3` never drops below ~3.0 V.
**FAIL:** notch lasts ~0.5–1 s and the board reboots → R16 is not the 10 k part, or the gate node has extra
capacitance. (R16 was already verified at ~10 kΩ cold — see step 2 below — so a fail here would be surprising.)

After step 9: step 10 (battery-only cold boot), then let it charge to termination to close out step 7.

---

## Status by step

| Step | What | Status |
|---|---|---|
| 1 | Visual inspection | **PASS** — all clear |
| 2 | Resistance / shorts, no power | **PASS** — all four rails in range |
| 3 | Rails on USB | **PASS** |
| 4 | USB enumeration + first flash | **PASS** — blank-flash boot loop diagnosed, not a fault |
| 5 | I²C scan | **PASS** — 0x76 and 0x10 both found |
| 6 | Sensor sanity | **PASS** |
| 0.1 | Battery plug polarity ritual | **PASS** — red = +, aligns with J3 pin 1, pack is protected |
| 7 | Battery connect + charge | **IN PROGRESS** — charging confirmed; termination check outstanding |
| 8 | BAT_SENSE ratio | **PASS** — ratio 0.4975; `BAT_TRIM` measured 2026-09-09 = **1.000** |
| 9 | Hand-over notch (scope) | **NEXT — do this now** |
| 10 | Battery-only cold boot | Pending |
| 11 | Soil calibration | **PASS** — dry/wet/threshold recorded 2026-09-13; `config.h` constants replaced |
| 12 | Sleep current | **BLOCKED** — still needs a µA meter. Partial: whole-cycle draw now derived from the battery curve, see finding 8 |
| 13 | Wi-Fi range + 24 h soak | **PARTIAL** — 11 h soak 2026-09-12/13, 249 cycles, counter unbroken. Bench RSSI −34 to −48 dBm. Range at the plant's location not yet checked |

## Measurements recorded

| Item | Expected | Measured | Verdict |
|---|---|---|---|
| +5V_PROT ↔ GND, cold | ≈10 kΩ (R16 — *this is the R16 value check*) | in range | PASS |
| VSYS ↔ GND, cold | MΩ / OL | in range | PASS |
| +3V3 ↔ GND, cold | MΩ | in range | PASS |
| VBAT ↔ GND, cold | ≈200 kΩ (R14+R15) | in range | PASS |
| +5V_PROT (USB) | 4.87–4.96 V | in range | PASS |
| VSYS (USB, no batt) | 4.45–4.65 V | in range | PASS |
| **VSYS (USB + charging)** | 4.45–4.65 V | **4.7 V** | PASS — see finding 5 |
| +3V3 | 3.30 V ±2 % | in range | PASS |
| Q3 V_GS, USB present | ≈ +0.4 V (Q3 off) | in range | PASS |
| **VBAT (charging)** | rising to 4.20 V | **3.9 → 4.0 V** | PASS |
| **BAT_SENSE ÷ VBAT** | 0.50 ±1 % | **1.99 / 4.00 = 0.4975** (−0.5 %) | **PASS** |
| I²C scan | 0x76 + 0x10 | both found | PASS |
| Charge current | 90–110 mA | *not measured — no inline current meter* | — |
| **BAT_TRIM** | 1.0 ±few % | **1.000** — meter and firmware agreed to the meter's resolution (±~0.3 %) | **PASS** |
| **Soil raw — probe in open air** | — | **2267** | calibration point, defines 0 % |
| **Soil raw — soil that wants watering** | — | **2011** | calibration point, = 24.7 %; sets `ALERT_SOIL_DRY_PCT` at 25 % |
| **Soil raw — soil just watered** | — | **1229** | calibration point, defines 100 % |
| **`SOIL_RAW_DRY` / `SOIL_RAW_WET`** | breadboard ≈2900 / ≈1465 | **2267 / 1229** | **PASS** — breadboard values were unusable, see finding 7 |
| **Wake cycle duration** | — | **4.04 s** — sensors + fast-path association + one POST | from the firmware's own `awake for` line |
| **Wake-cycle average current** | 80 mA (firmware's working assumption) | **≈135 mA** | derived, see finding 8 — the assumption is ~70 % optimistic |

Rail voltages were confirmed in-band but exact figures were not written down. **Record real numbers on
boards #2–#5** — unit-to-unit spread on +3V3 and on D4's drop (5V − VSYS) is the baseline that makes a
Rev B decision easy.

## Findings — things the guide did not say

1. **Silk labels are net names, not TP numbers.** The guide's §2 probe table uses TP1–TP12, but the
   silkscreen reads `5V` `VSYS` `3V3` `VBAT` `BAT_SNS` `SIG` `GND` `EN` `IO0` `TX` `RX`. Mapping:
   TP1=5V, TP2=VSYS, TP3=3V3, TP4=VBAT, TP5=BAT_SNS, TP6=SIG, TP7=GND, TP9=EN, TP10=IO0,
   TP11=TX, TP12=RX, TP8=the GND pad in the UART row of three.
2. **R16 can be verified cold with a multimeter — no scope needed.** It is the *only* resistive path
   from +5V_PROT to GND, so that rail's cold resistance reads its value directly. ~10 kΩ = the fix is
   fitted; ~100 kΩ = the old part. Catches the step 9 failure before power is ever applied.
3. **There is no GPIO-controlled LED on this board.** D2 is hardwired to +3V3 through R5; D3 belongs to
   the charger. Step 4's "flash a hello/blink build" is impossible as written — use a serial hello.
4. **A blank module makes the USB port connect/disconnect about once a second.** Erased flash reads as
   `0xFFFFFFFF`, the ROM finds no application, resets, and retries forever; because USB is the ESP32's own
   peripheral, every reset re-enumerates. Sounds alarming, is normal on a new board. **Fix: hold SW1 (BOOT)
   while plugging USB in**, hold two more seconds, release — that forces ROM download mode, which runs no
   application code and cannot loop. Flash once and it never happens again.
5. **VSYS reads ~4.7 V, above the documented 4.45–4.65 V band.** Not a fault — VSYS is 5V minus D4's forward
   drop, and a Schottky's V_f is smaller at light load than the guide assumed. The band is pessimistic.
6. Observations 1–3 in the guide's §5: humidity self-heating offset, the corrected charger-cycling
   mechanism plus D3-as-duty-cycle-indicator, and the reversed-probe-cable signature.
7. **The breadboard soil constants were not imprecise, they were unusable — and the scale failed
   silently.** `config.h` shipped with `SOIL_RAW_DRY 2900` from the breadboard. This probe on this board
   reads **2267 in open air**, and air is as dry as anything ever gets. Through
   `pct = (DRY − raw) / (DRY − WET) × 100` that put the floor of the scale at
   `(2900 − 2267) / 1435 = 45.7 %`: the reported percentage could not physically go below 45.7 %, so a
   dry-soil alert set at 30 % was unreachable no matter how parched the pot. Nothing warns about this.
   The percentage looks plausible, moves in the right direction, and is simply missing its bottom half —
   which is exactly the failure a week of unattended logging would not reveal. **Never carry a soil
   constant across from a breadboard; the probe, the cable and the board are all part of the divider.**
8. **The battery discharge curve is a current meter, and step 12 does not strictly need one.** An 11-hour
   soak at one-minute wakes took the cell 4.170 V → 4.076 V. Discarding the first ~30 minutes (surface
   charge off the charger, visibly twice as steep as everything after), the settled slope is ≈1.75 %/h,
   which on the 500 mAh pack is **≈8–9 mA average**. With a 4.04 s wake in a 64 s cycle — 6.3 % duty — and
   the documented 210 µA floor assumed for the other 93.7 %, the wake cycle averages **≈135 mA**. That
   figure is robust: doubling the assumed sleep floor only moves it to ≈130 mA. The sleep term is what a
   single whole-cycle measurement cannot separate out — but run the same experiment at a 30-minute
   interval, where the duty cycle is 0.2 %, and the slope is almost entirely sleep. **Two soaks at two
   intervals give both numbers with no µA meter.**

## Guide corrections still to make

- §1: D3 explanation — wording ("flickers faintly") is right, mechanism is not. See §5 observation 2.
- §2: add the silk-label column so the probe table matches the board.
- §3 step 3: VSYS band runs low; consider 4.45–4.75 V.
- §3 step 4: remove "blink build" — no GPIO LED exists.
- §3 step 11: add the reversed-cable signature (high, constant, unresponsive — not dead).
- §3 step 11: state plainly that breadboard dry/wet numbers must not be carried onto the board, and say
  why — the failure is a scale with no bottom, not a wrong reading. See finding 7.
- §3 step 11: take **three** points, not two. Air and water bracket the range, but the number that
  actually matters is the raw value of soil that wants watering — that is what the alert threshold is set
  from, and it cannot be interpolated reliably from the other two.
- §3 section A: add the cold resistance checks as a numbered step, incl. the R16 trick.

## Files added this session

| File | Purpose |
|---|---|
| `firmware/sensor_check/sensor_check.ino` | The one in use. Reads BME280 + VEML7700 + soil + BAT_SENSE, never sleeps so the USB CDC port stays alive. **Correct I²C pins: SDA 38, SCL 39.** |
| `firmware/bringup_check/bringup_check.ino` | Fuller diagnostic — decodes the reset reason by name (incl. `BROWNOUT`), reports chip/flash/PSRAM, scans I²C. Useful for step 9 and step 10 |

**Known gap:** `sensor_check.ino` takes a *single* ADC sample for soil where `config.h` assumes 16.
Average before recording any calibration value.

## Blocked

- **Step 12, sleep current** — needs a meter resolving µA in series with the cell. Rework gear is on the
  bench so D2 can be lifted for the ~90 µA measurement, but nothing can read it. **Partially routed
  around:** finding 8 derives ≈135 mA for the wake cycle from the battery curve. A 30-minute-interval
  soak isolates the sleep term the same way, which would close this without buying anything.
- **Charge current (step 7)** — needs an inline current meter. R13 = 10 k programs 1000/10k = 100 mA by
  design; a sensibly-rising VBAT is decent circumstantial evidence.

## Context a fresh session needs

- **I²C is on IO38/IO39**, re-pinned during layout 2026-08-15. `Wire.begin(38, 39)` — SDA first. The old
  IO4/IO5 numbers appear in retired docs and will silently find nothing.
- **SW1 = BOOT, SW2 = RESET.**
- **Soil probe: GPIO21 LOW = probe ON**, wait ≥200 ms, read GPIO1. Higher raw count = drier.
- **Soil calibration is board #1's, taken 2026-09-13**: air 2267, wants-water 2011, just-watered 1229.
  These belong to this probe, this cable and this board — re-take all three on boards #2–#5.
- **BAT_SENSE lies whenever USB is present with no cell** — the charger holds VBAT near 4.2 V and the
  divider faithfully reports it. Firmware must gate battery reporting on USB absence. Rev A has **no VBUS
  sense line**, so firmware uses "has a host opened the CDC port" as a proxy — right at the bench, wrong on
  a phone charger. Rev B item.
- **Never store the board with a flat cell plugged in.** ~210 µA sleep floor; 0 V recovery is unavailable
  on these packs.

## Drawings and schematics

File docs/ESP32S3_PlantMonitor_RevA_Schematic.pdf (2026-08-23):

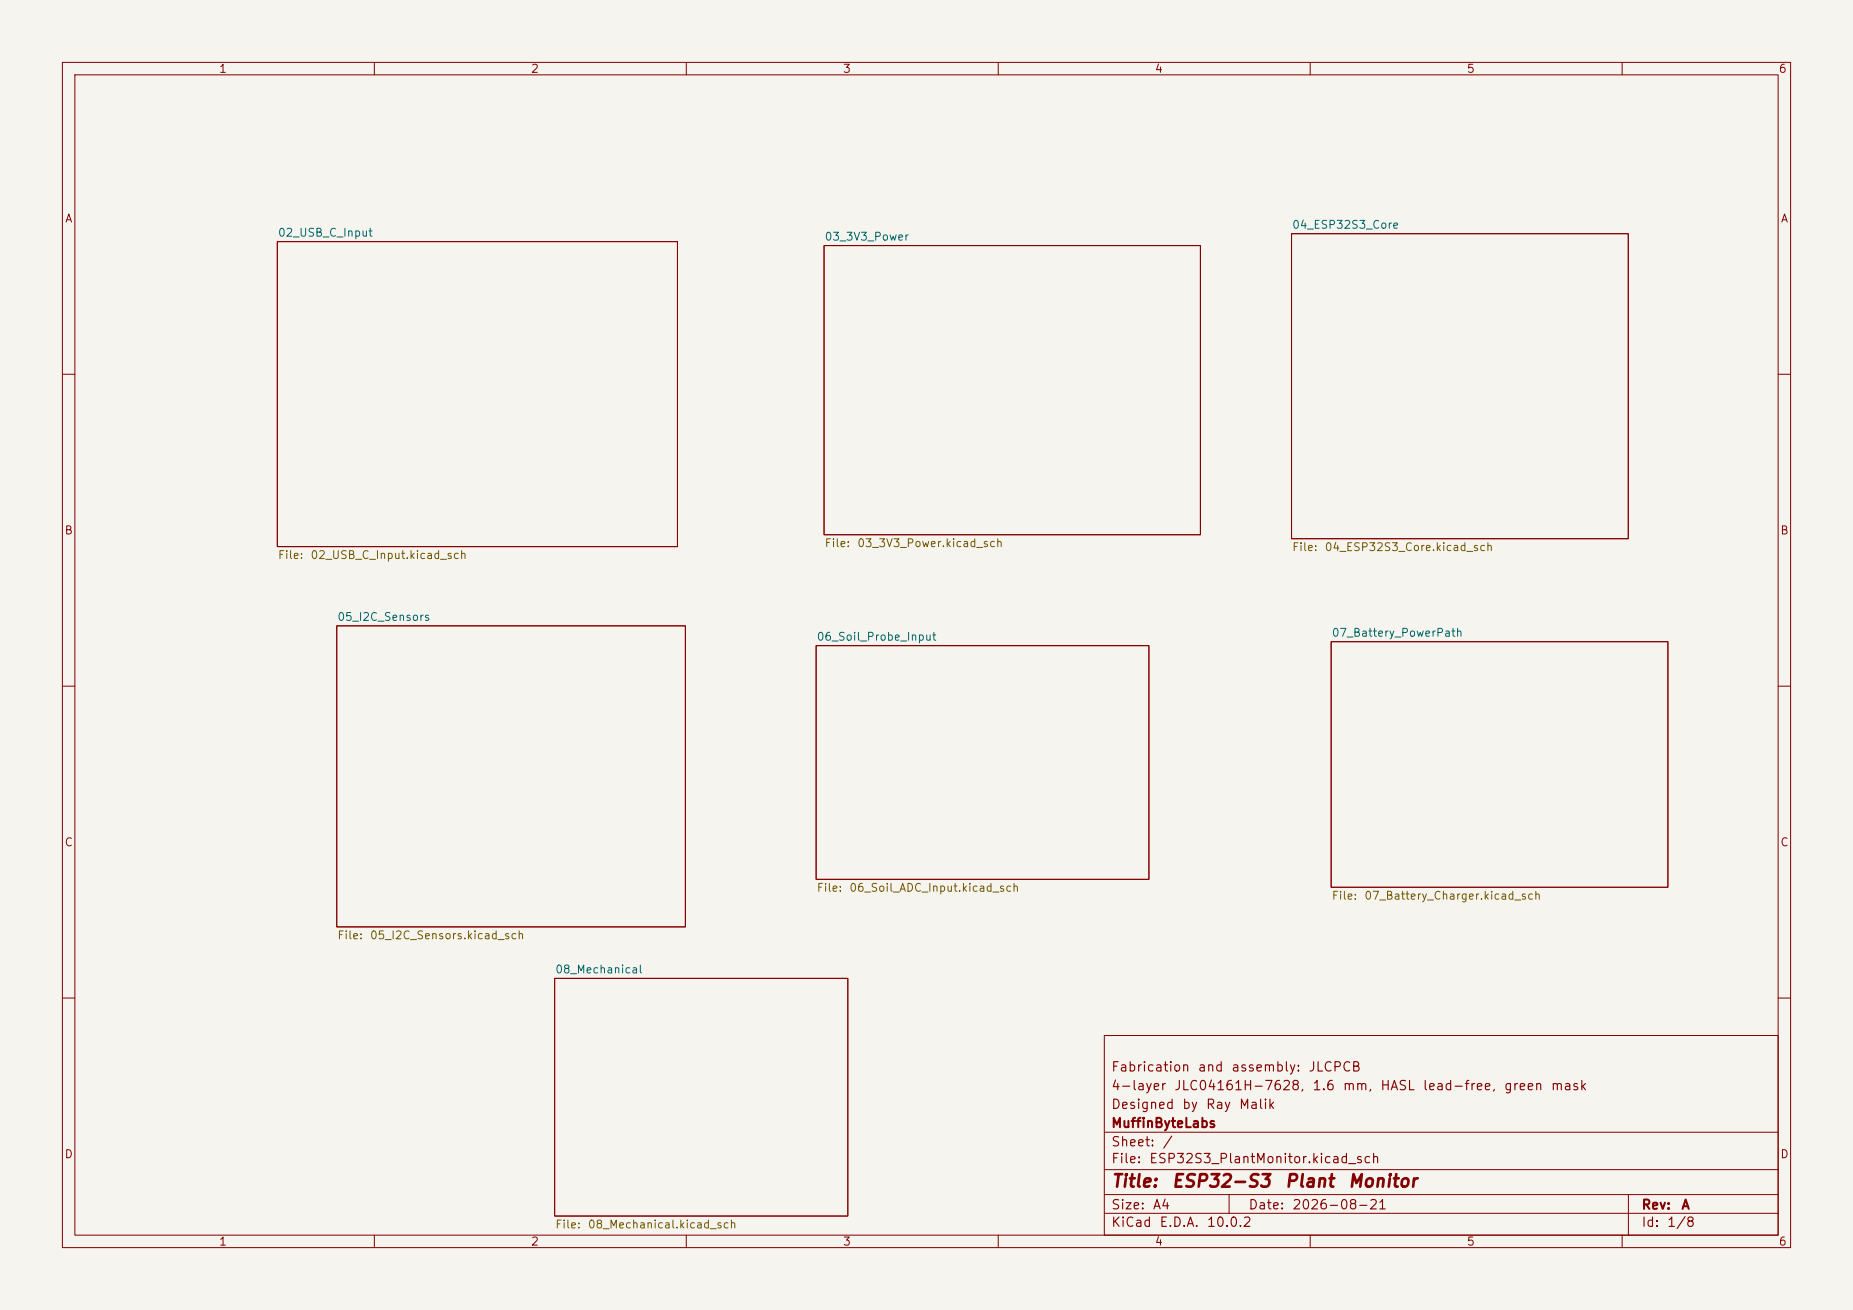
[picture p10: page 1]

Fabrication and assembly: JLCPCB
4-layer JLC04161H-7628, 1.6 mm, HASL lead-free, green mask
Designed by Ray Malik
MuffinByteLabs
Sheet: /
File: ESP32S3_PlantMonitor.kicad_sch
Title: ESP32-S3 Plant Monitor

Size: A4 | Rev: A
KiCad E.D.A. 10.0.2 | Id: 1/8

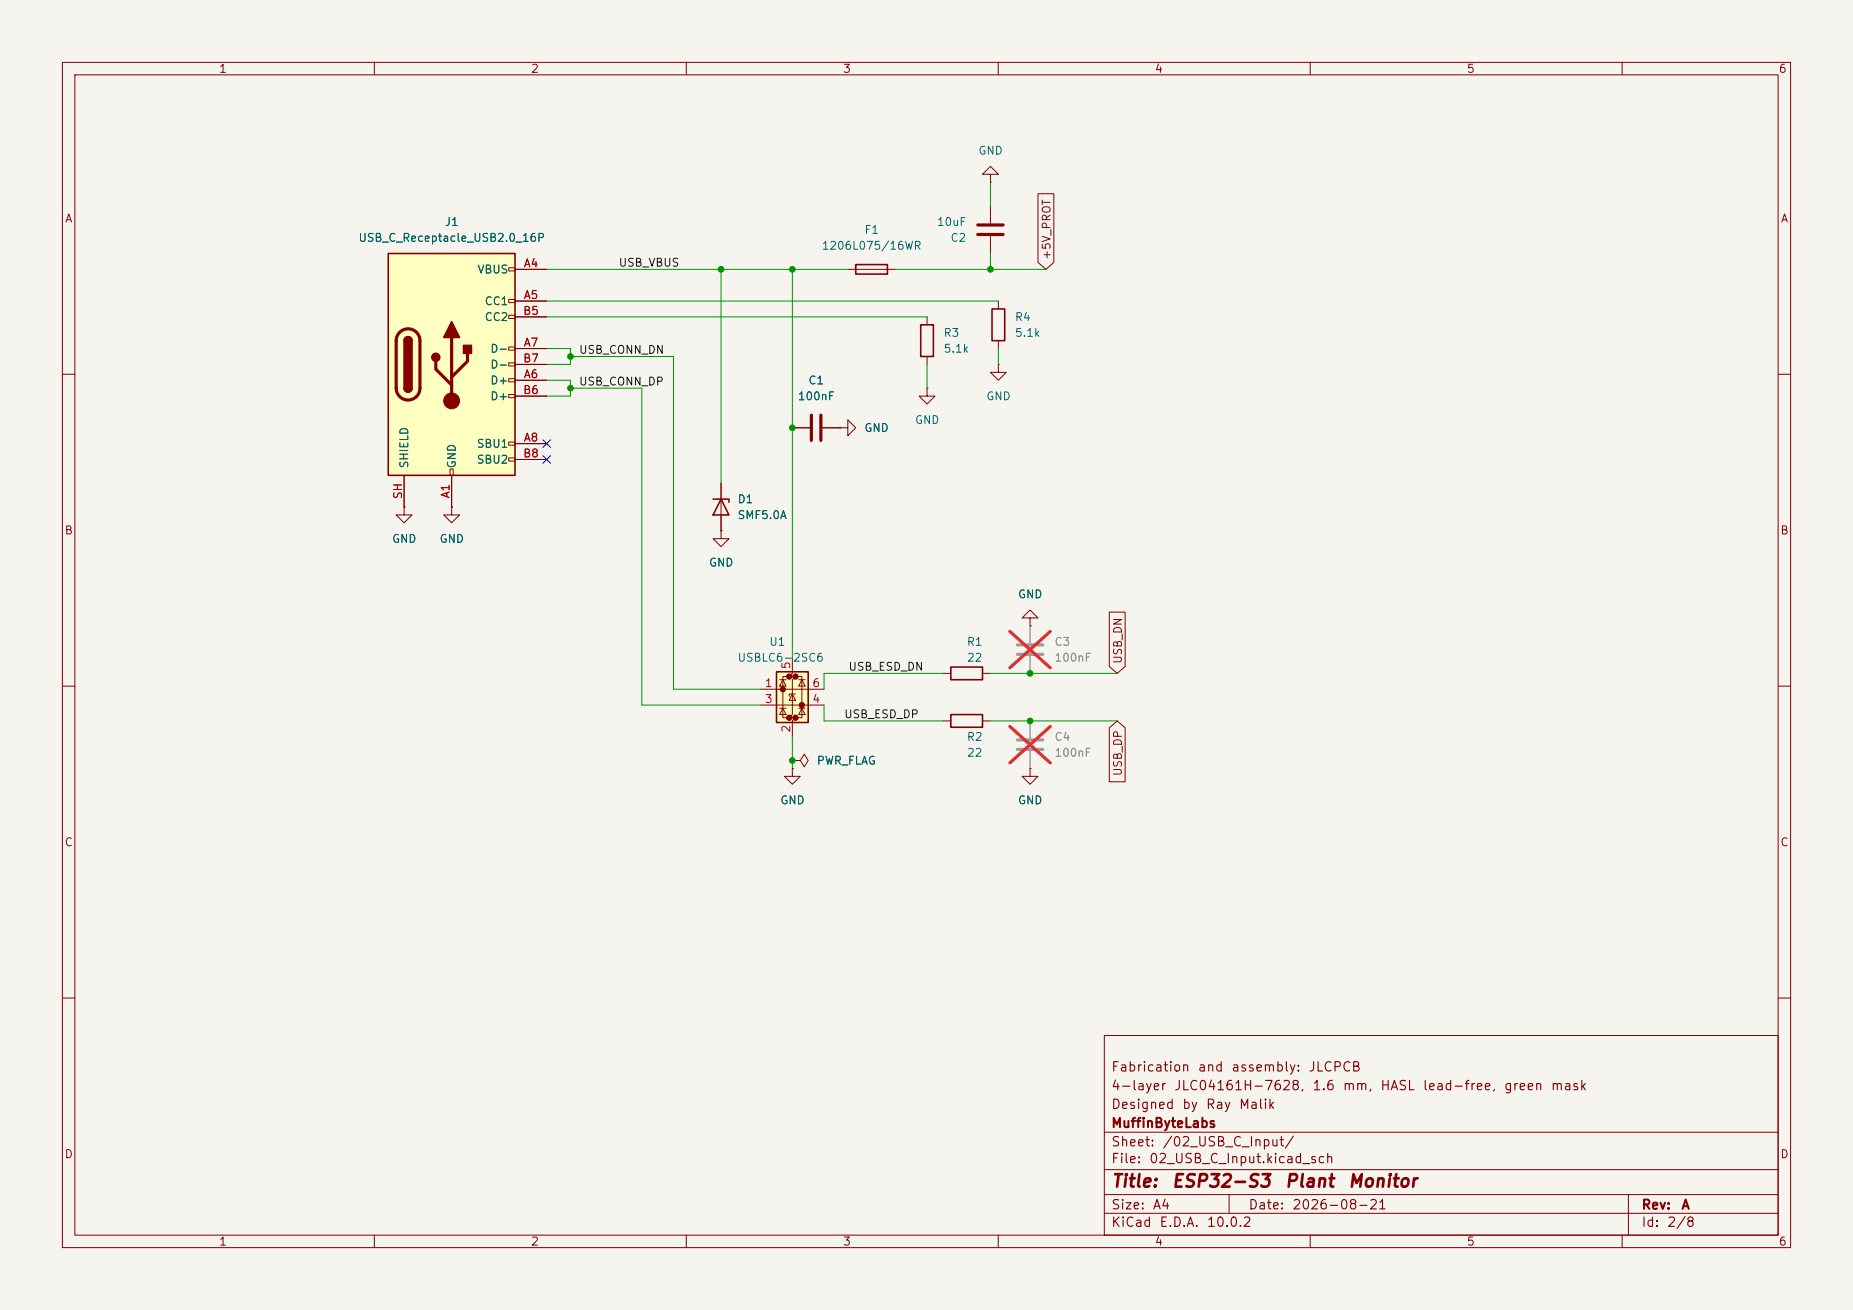
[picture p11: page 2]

Fabrication and assembly: JLCPCB
4-layer JLC04161H-7628, 1.6 mm, HASL lead-free, green mask
Designed by Ray Malik
MuffinByteLabs
Sheet: /02_USB_C_Input/
File: 02_USB_C_Input.kicad_sch
Title: ESP32-S3 Plant Monitor

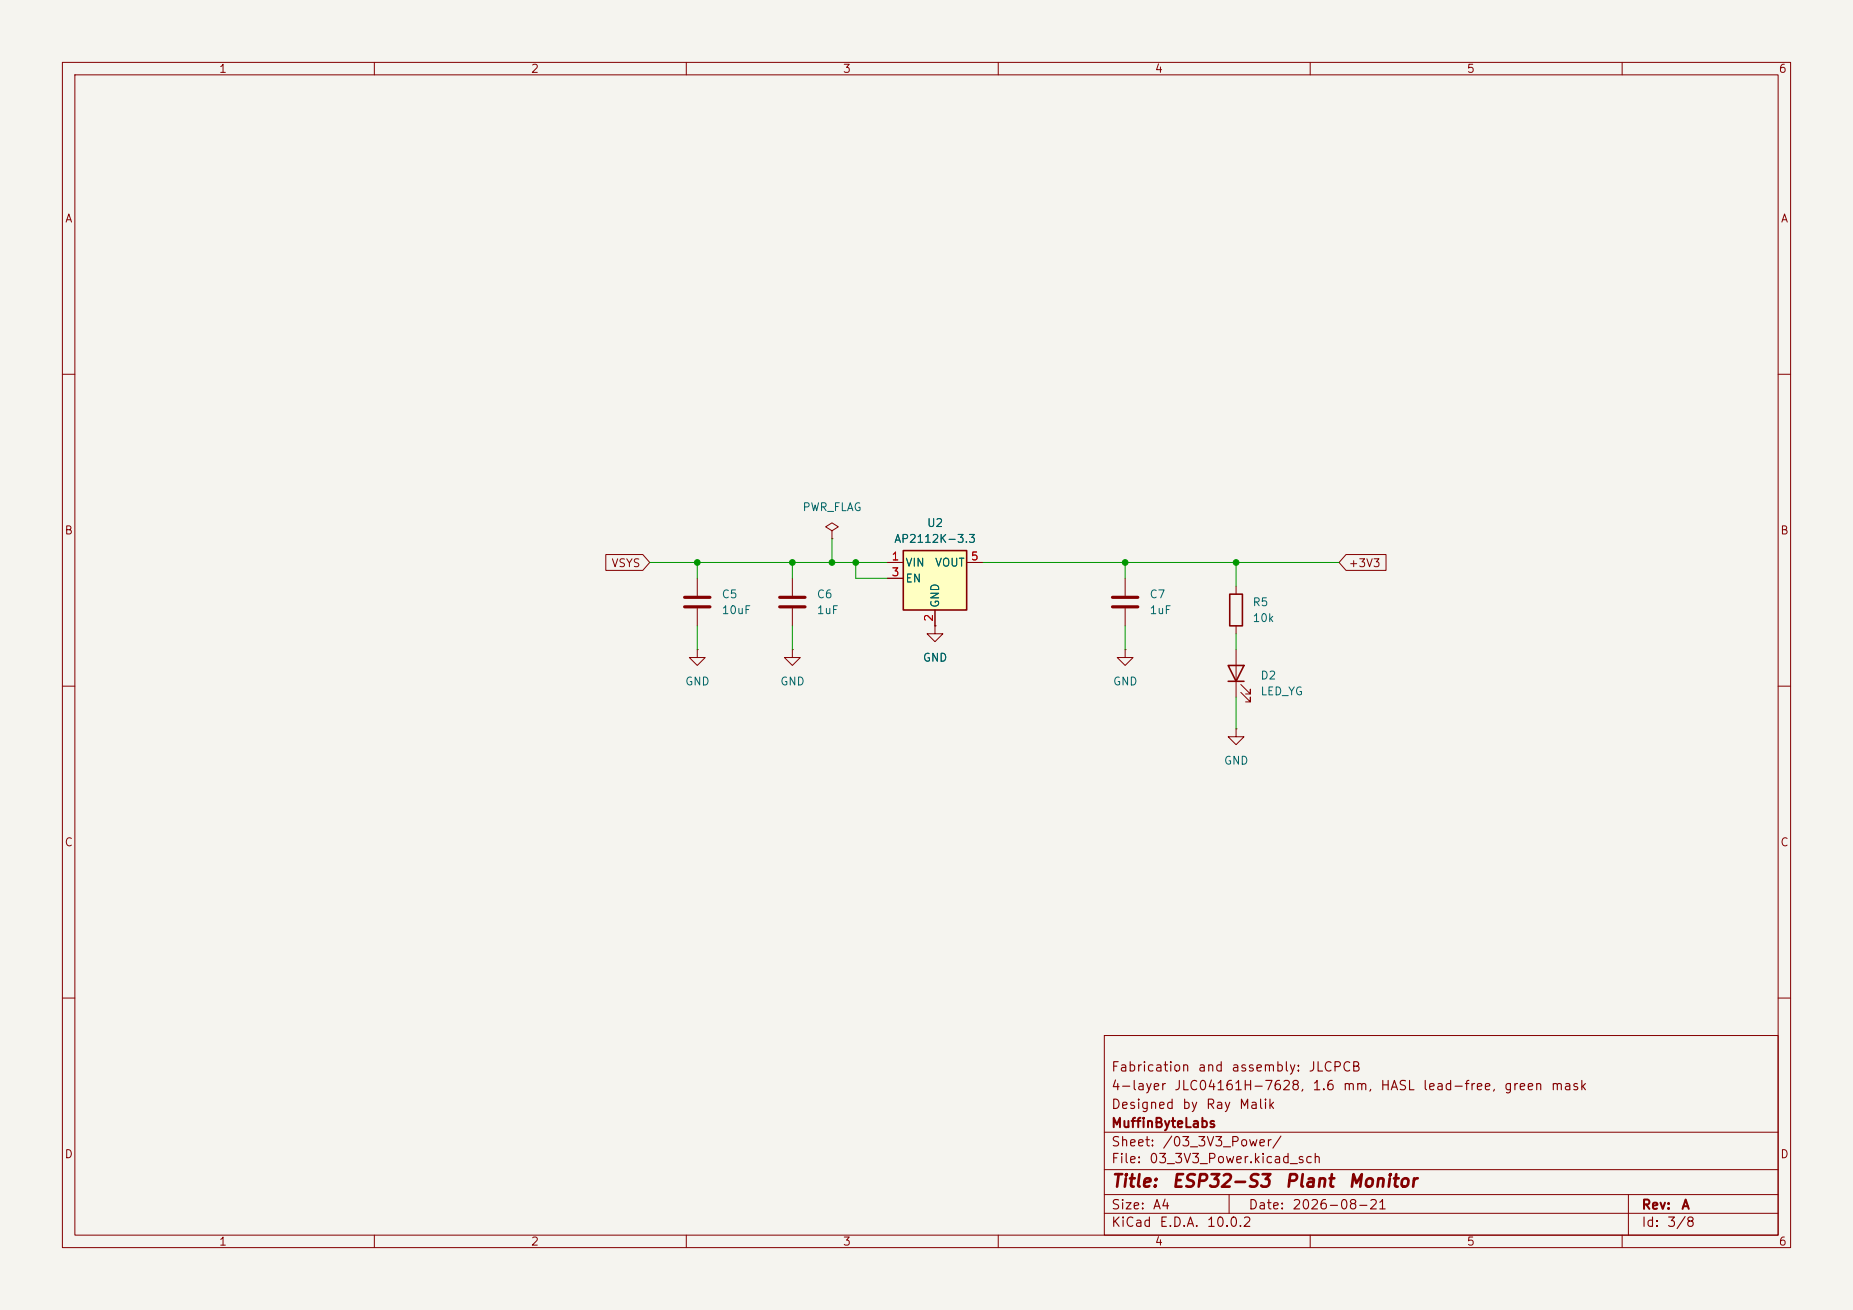
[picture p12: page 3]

Fabrication and assembly: JLCPCB
4-layer JLC04161H-7628, 1.6 mm, HASL lead-free, green mask
Designed by Ray Malik
MuffinByteLabs
Sheet: /03_3V3_Power/
File: 03_3V3_Power.kicad_sch
Title: ESP32-S3 Plant Monitor

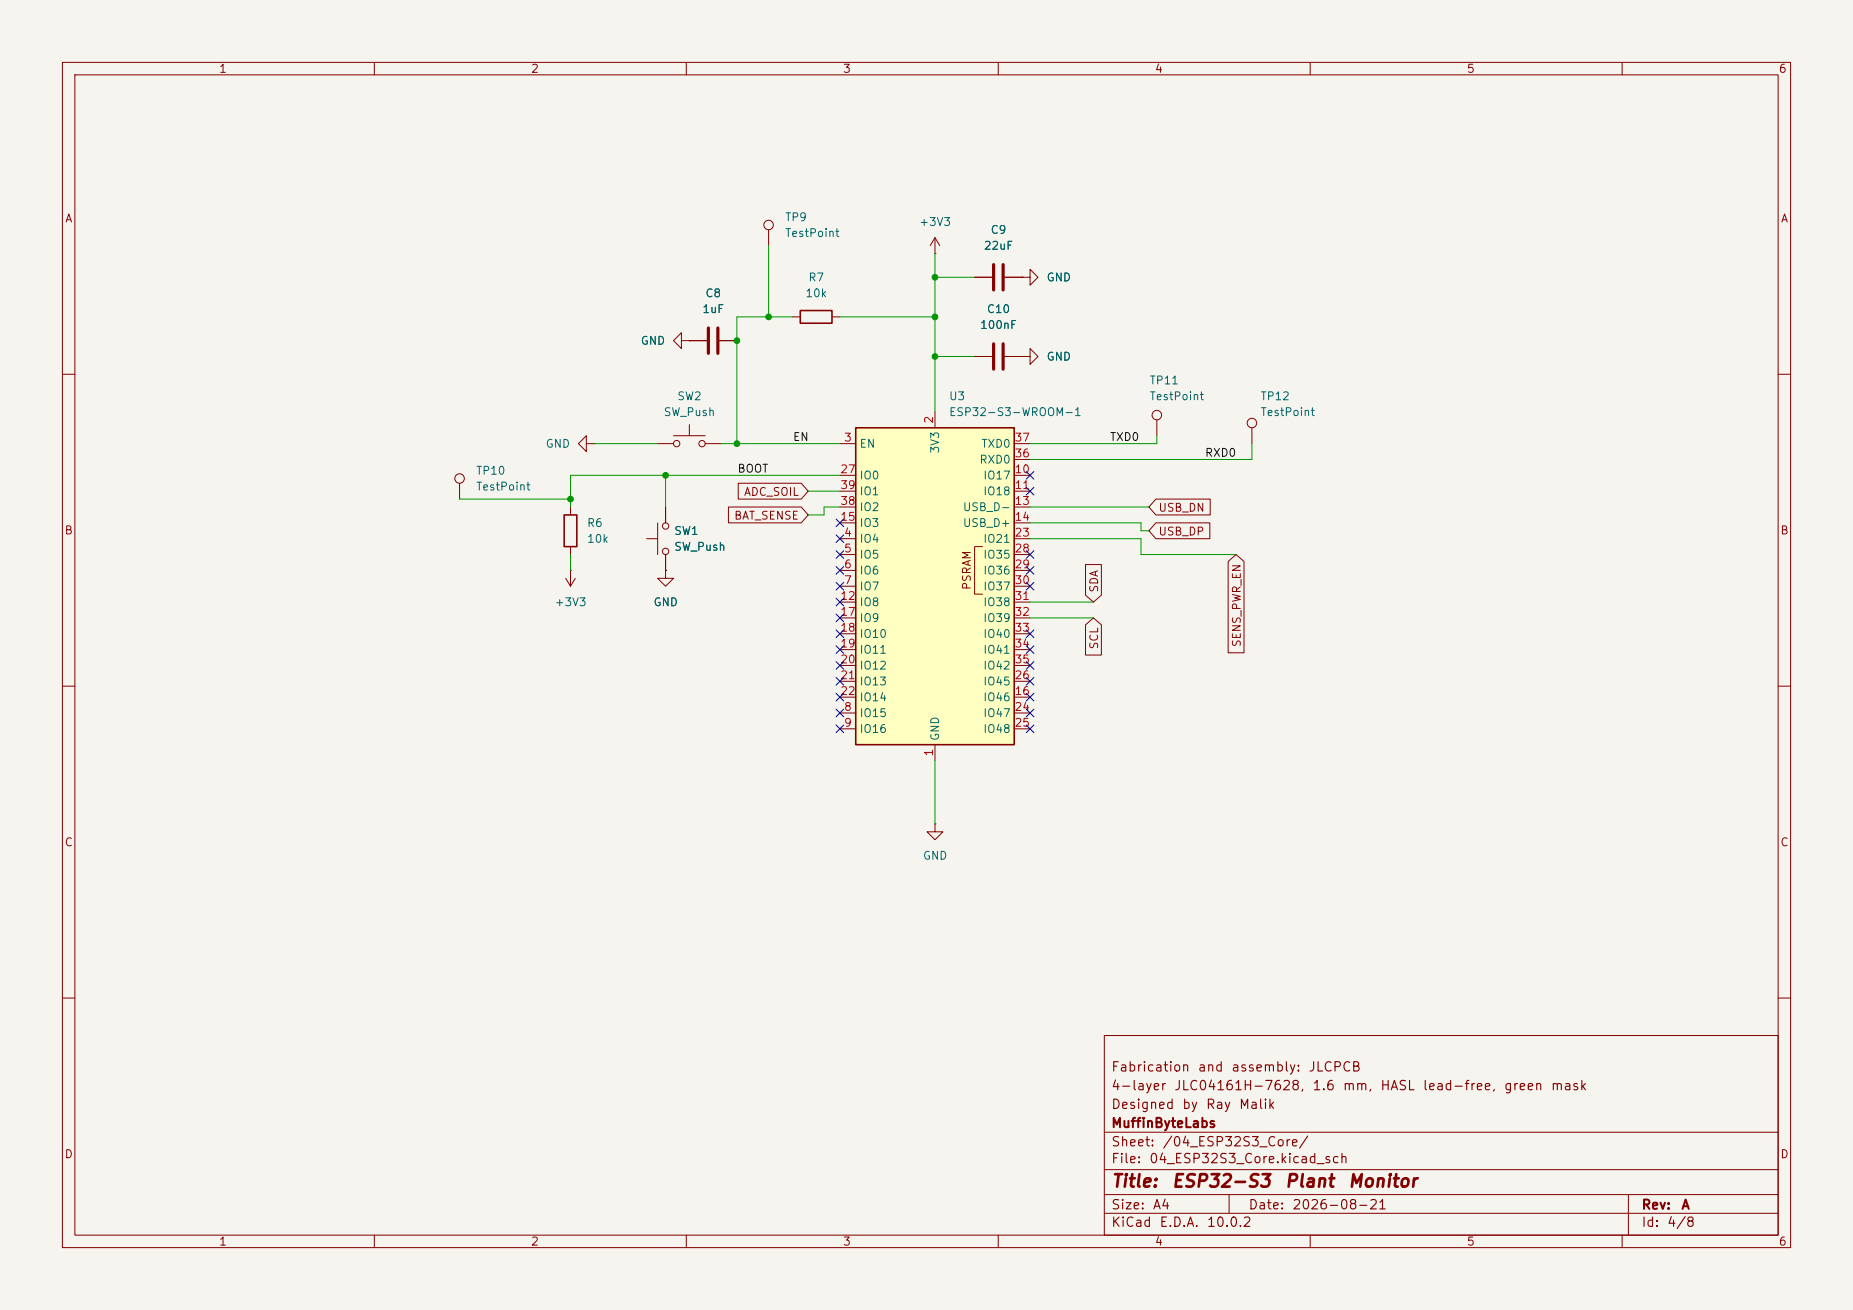
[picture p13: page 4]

Fabrication and assembly: JLCPCB
4-layer JLC04161H-7628, 1.6 mm, HASL lead-free, green mask
Designed by Ray Malik
MuffinByteLabs
Sheet: /04_ESP32S3_Core/
File: 04_ESP32S3_Core.kicad_sch
Title: ESP32-S3 Plant Monitor

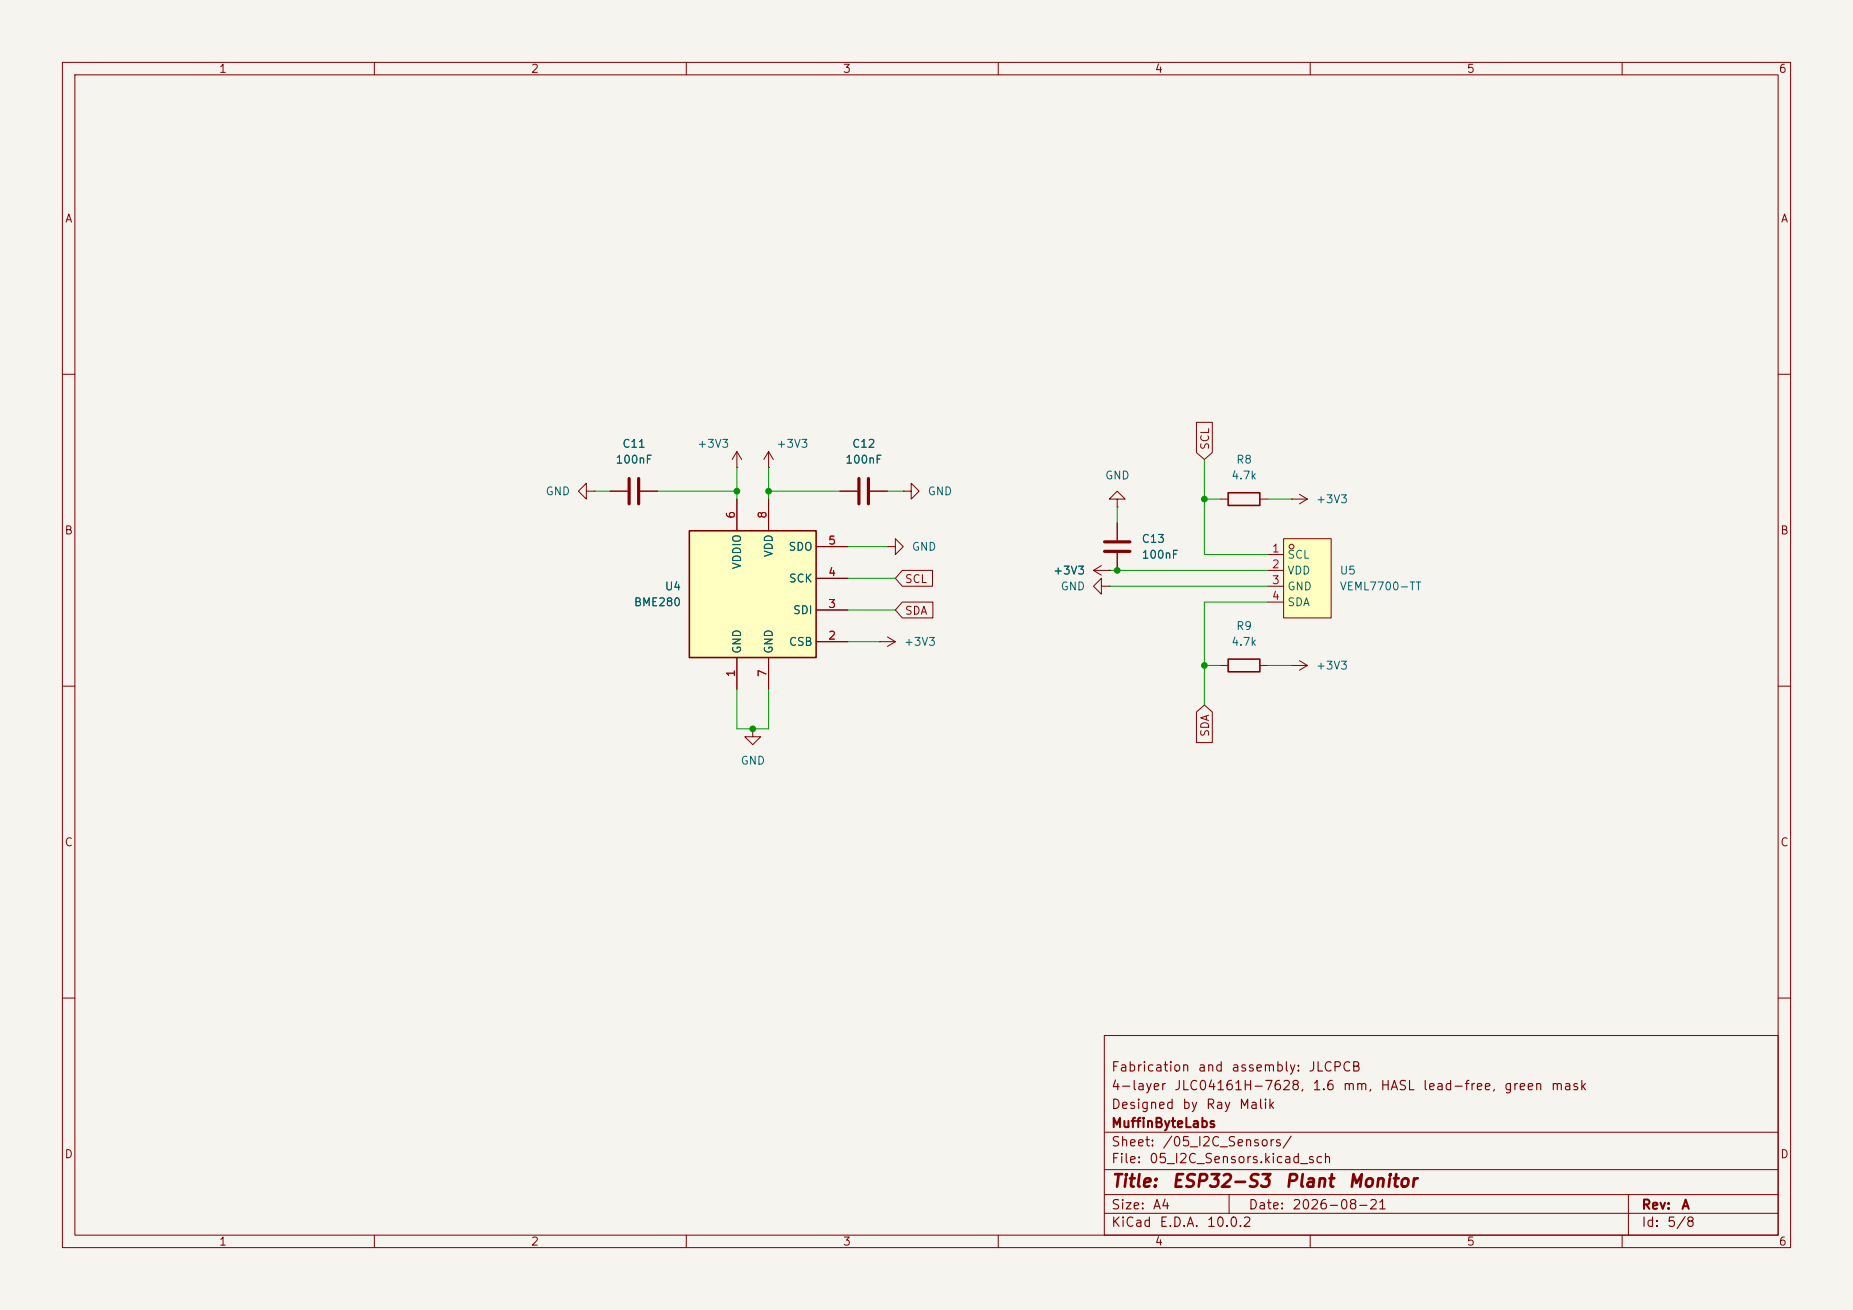
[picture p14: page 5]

8 U4 BME280 +3V3 GND +3V3 SDA SCL SCL SDA C13
100nF GND

Fabrication and assembly: JLCPCB
4-layer JLC04161H-7628, 1.6 mm, HASL lead-free, green mask
Designed by Ray Malik
MuffinByteLabs
Sheet: /05_I2C_Sensors/
File: 05_I2C_Sensors.kicad_sch
Title: ESP32-S3 Plant Monitor

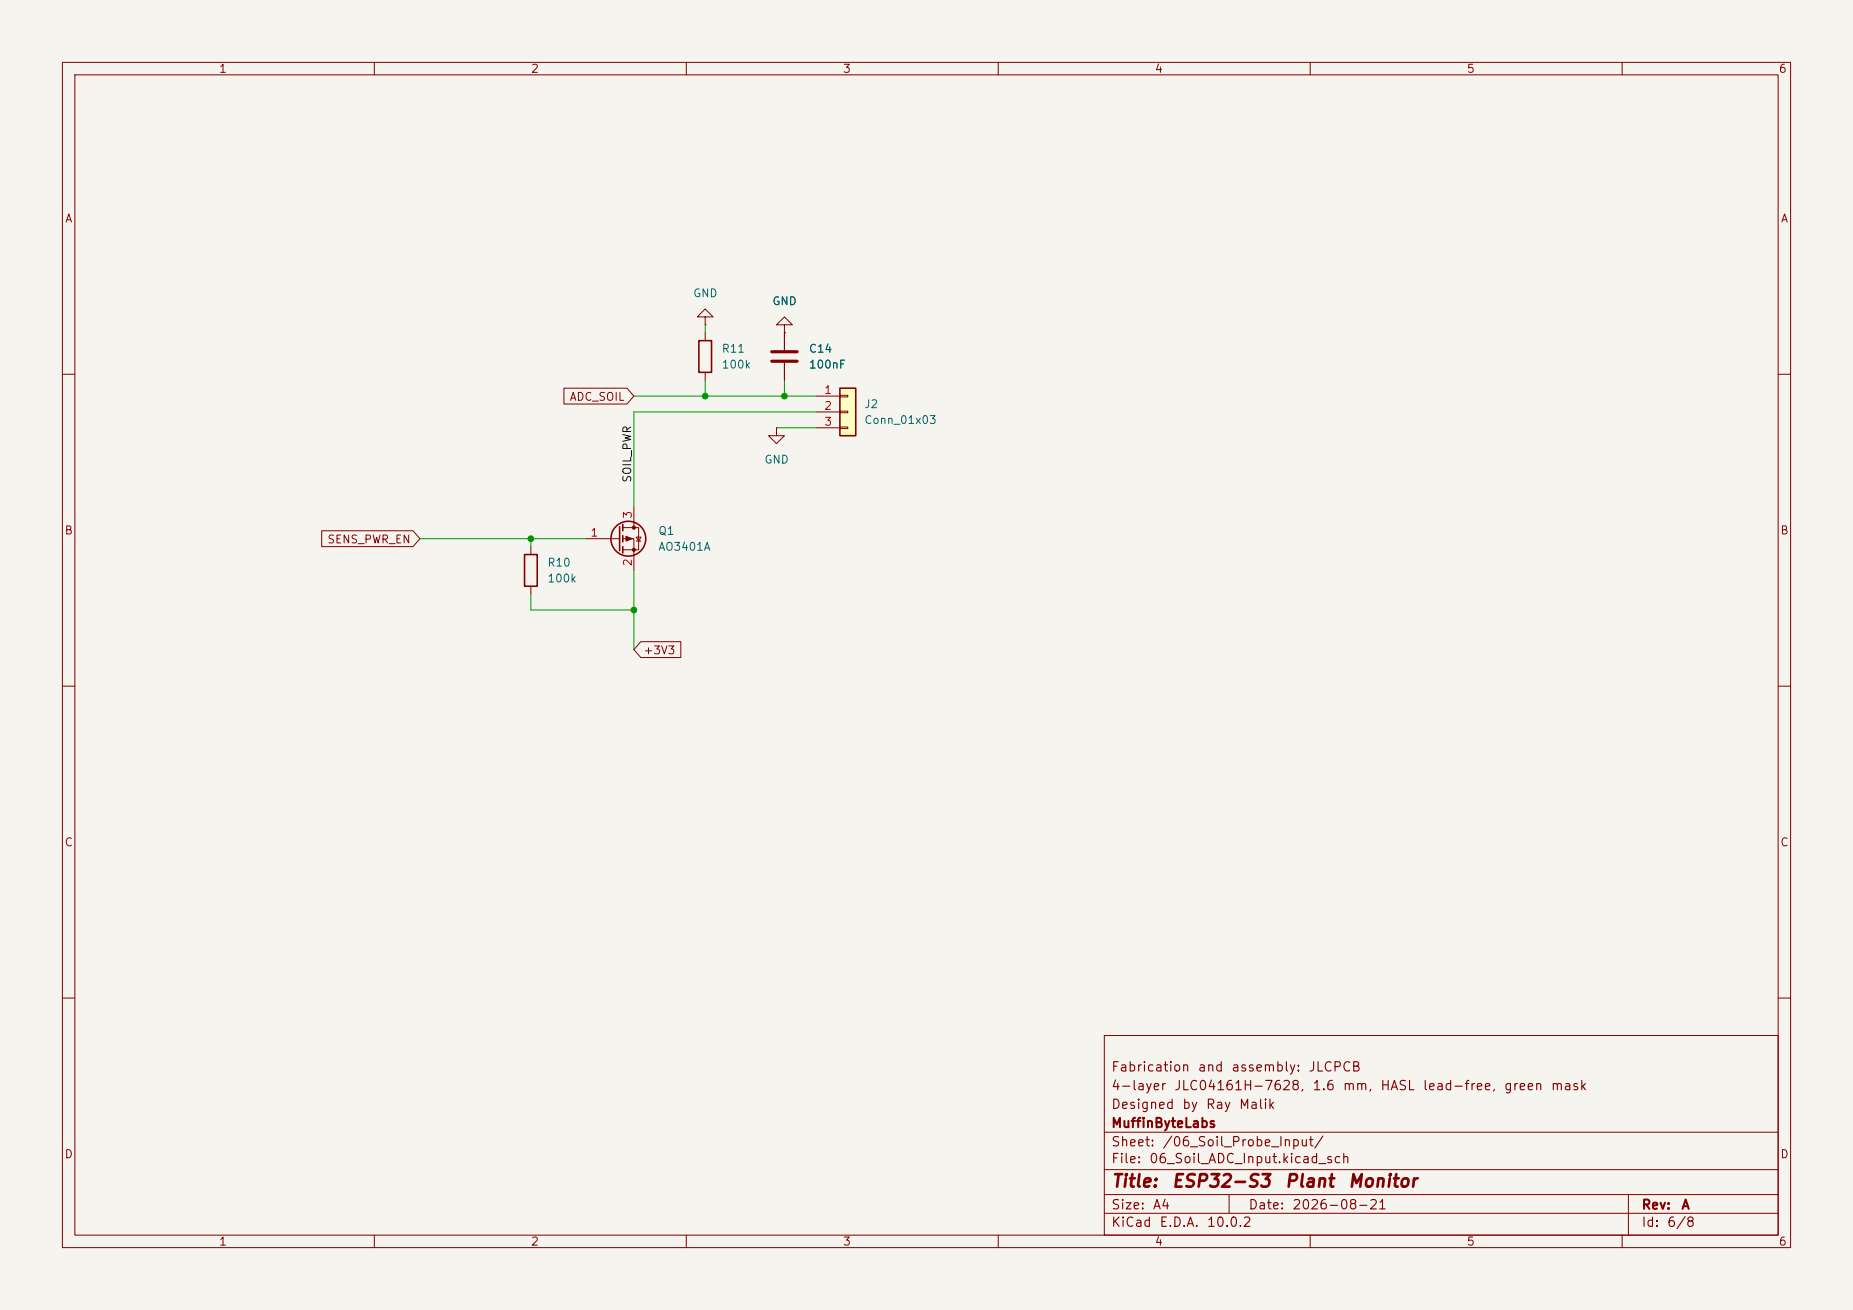
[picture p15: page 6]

Fabrication and assembly: JLCPCB
4-layer JLC04161H-7628, 1.6 mm, HASL lead-free, green mask
Designed by Ray Malik
MuffinByteLabs
Sheet: /06_Soil_Probe_Input/
File: 06_Soil_ADC_Input.kicad_sch
Title: ESP32-S3 Plant Monitor

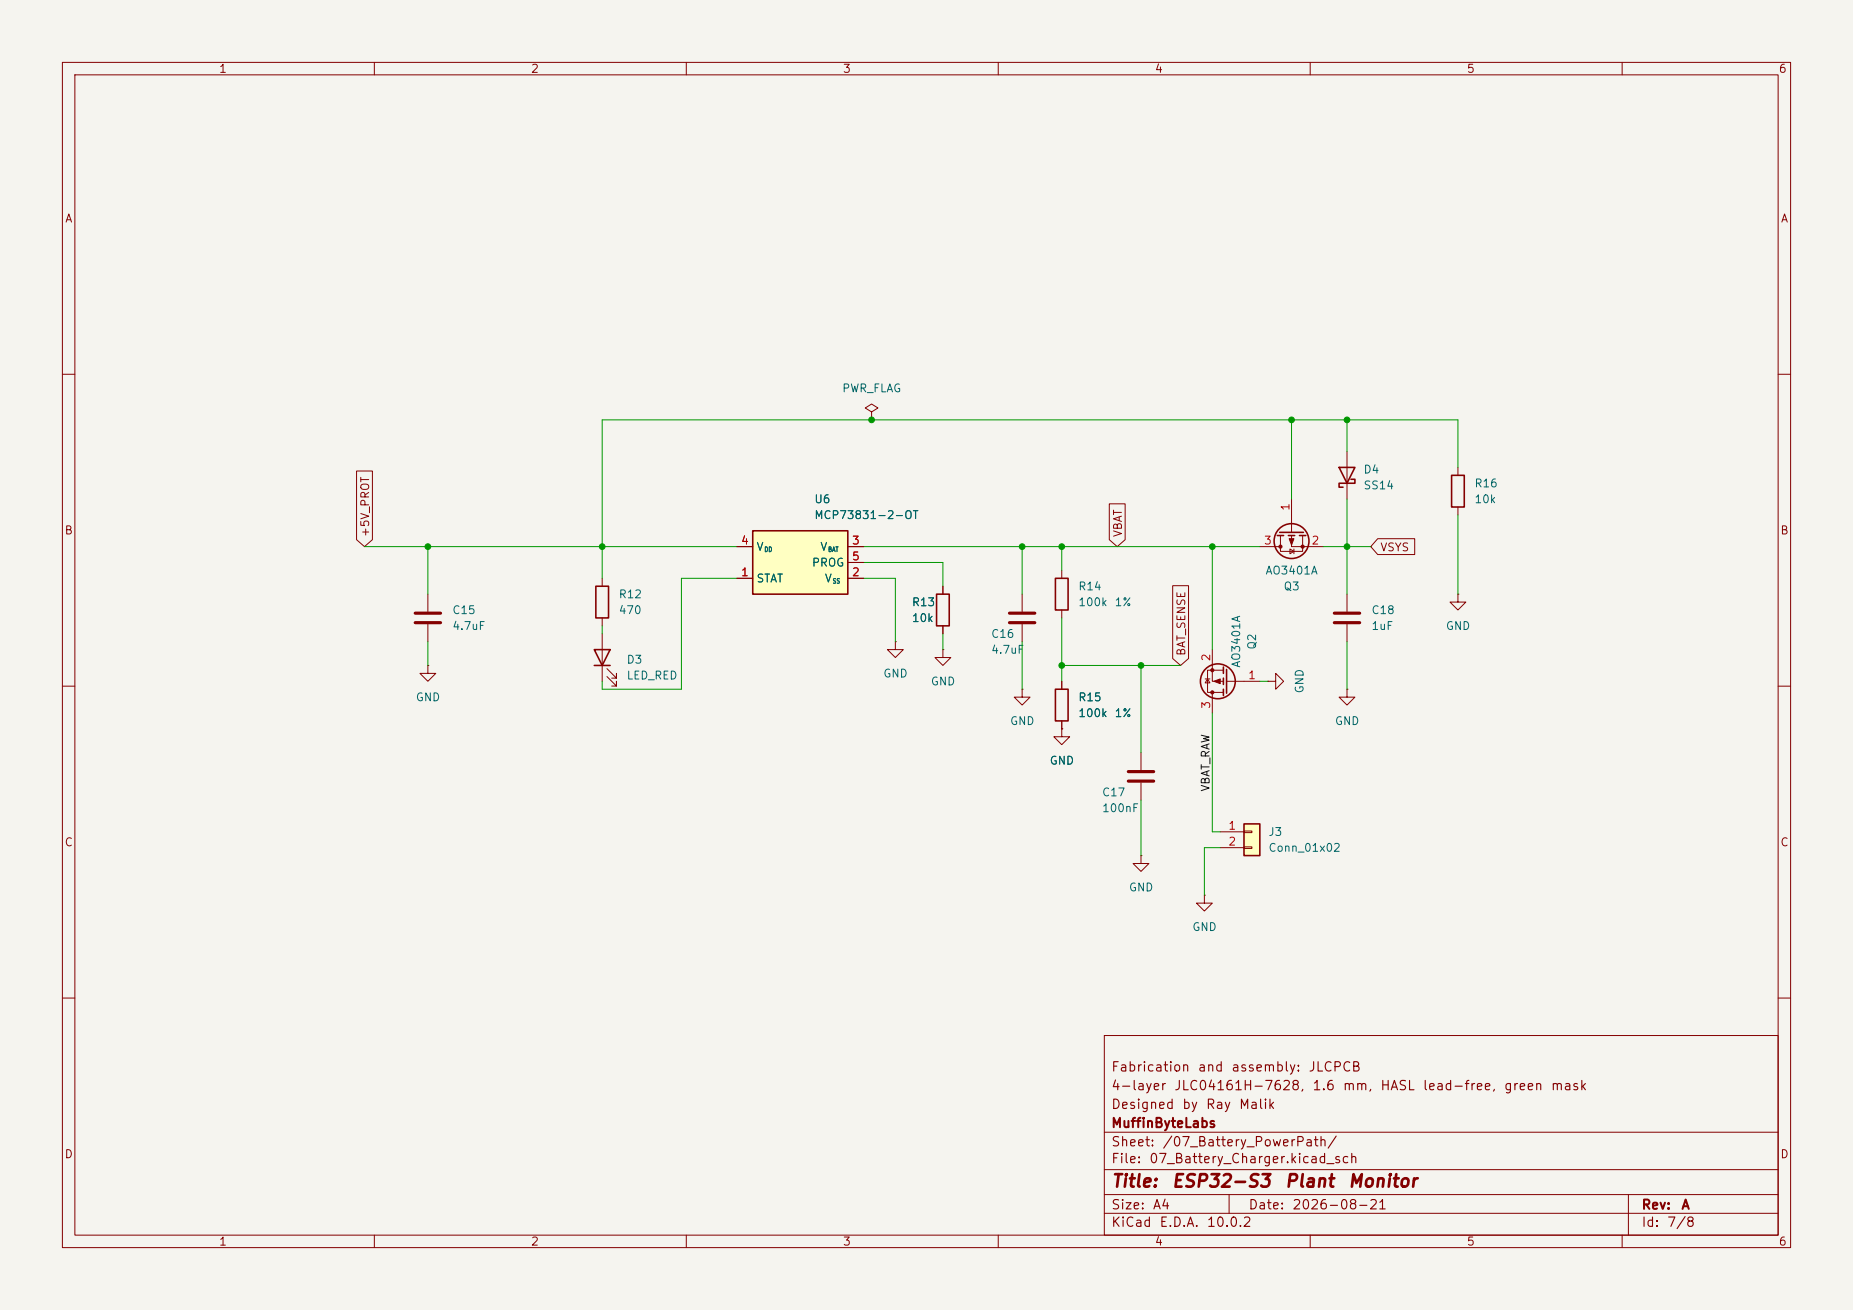
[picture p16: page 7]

Fabrication and assembly: JLCPCB
4-layer JLC04161H-7628, 1.6 mm, HASL lead-free, green mask
Designed by Ray Malik
MuffinByteLabs
Sheet: /07_Battery_PowerPath/
File: 07_Battery_Charger.kicad_sch
Title: ESP32-S3 Plant Monitor

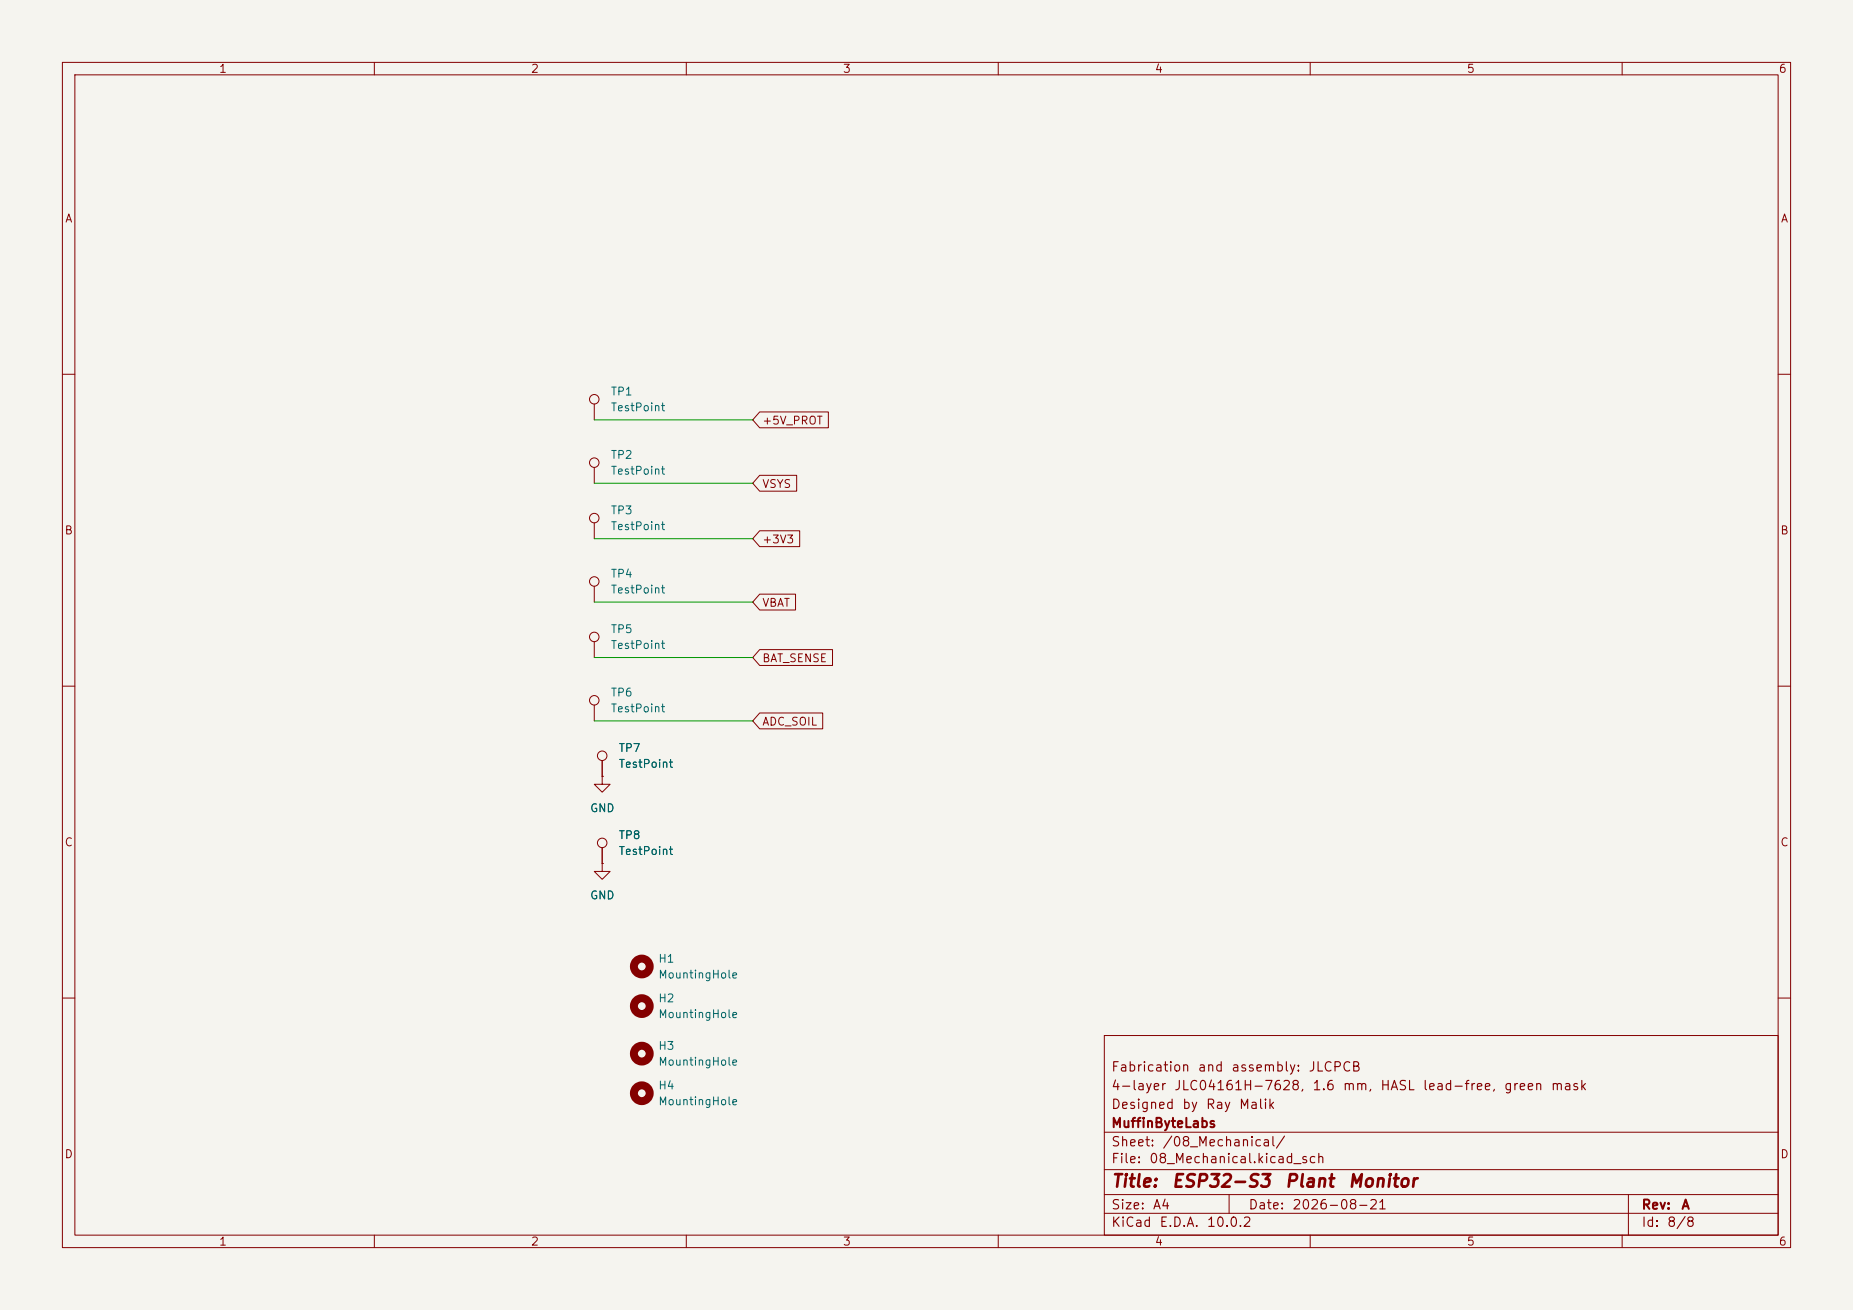
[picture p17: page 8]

Fabrication and assembly: JLCPCB
4-layer JLC04161H-7628, 1.6 mm, HASL lead-free, green mask
Designed by Ray Malik
MuffinByteLabs
Sheet: /08_Mechanical/
File: 08_Mechanical.kicad_sch
Title: ESP32-S3 Plant Monitor

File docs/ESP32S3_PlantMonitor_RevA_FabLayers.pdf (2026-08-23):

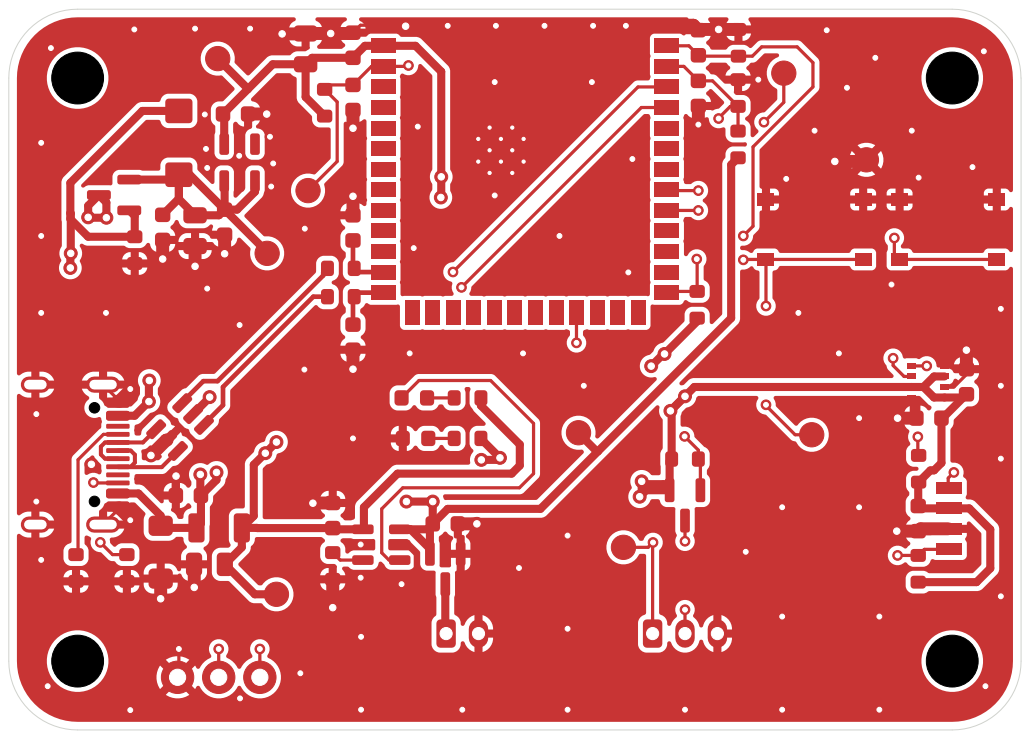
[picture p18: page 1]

Fabrication and assembly: JLCPCB
4-layer JLC04161H-7628, 1.6 mm, HASL lead-free, green mask
Designed by Ray Malik
MuffinByteLabs
Sheet:
File: ESP32S3_PlantMonitor.kicad_pcb
Title: ESP32-S3 Plant Monitor

Size: A4 | Rev: A
KiCad E.D.A. 10.0.2 | Id: 1/10

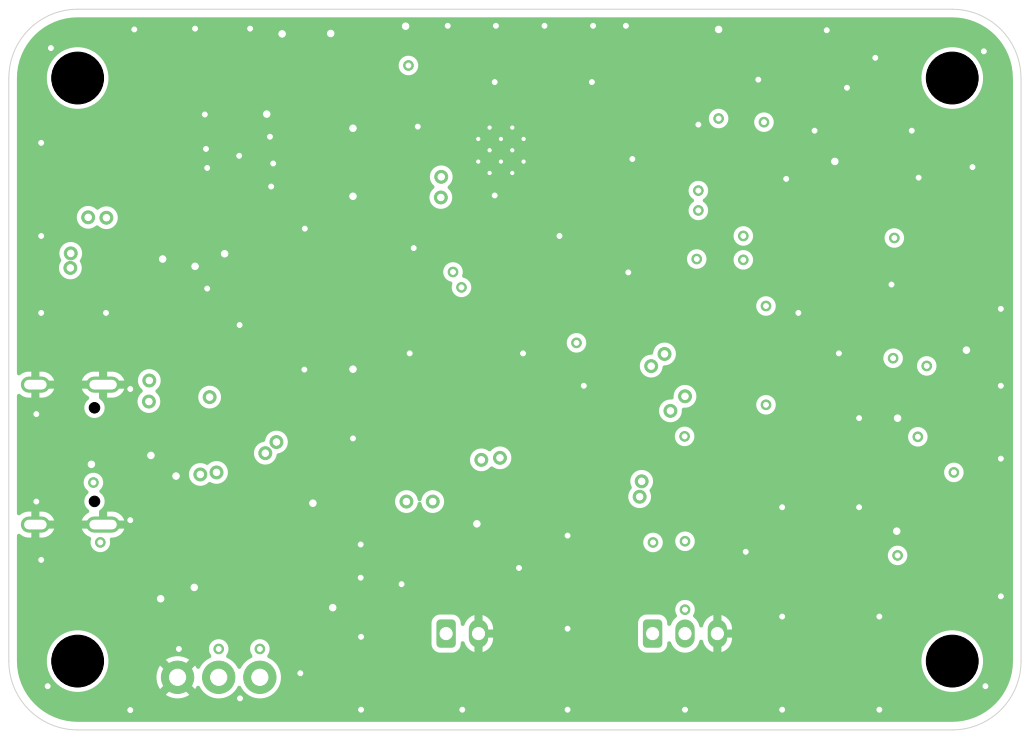
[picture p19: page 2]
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

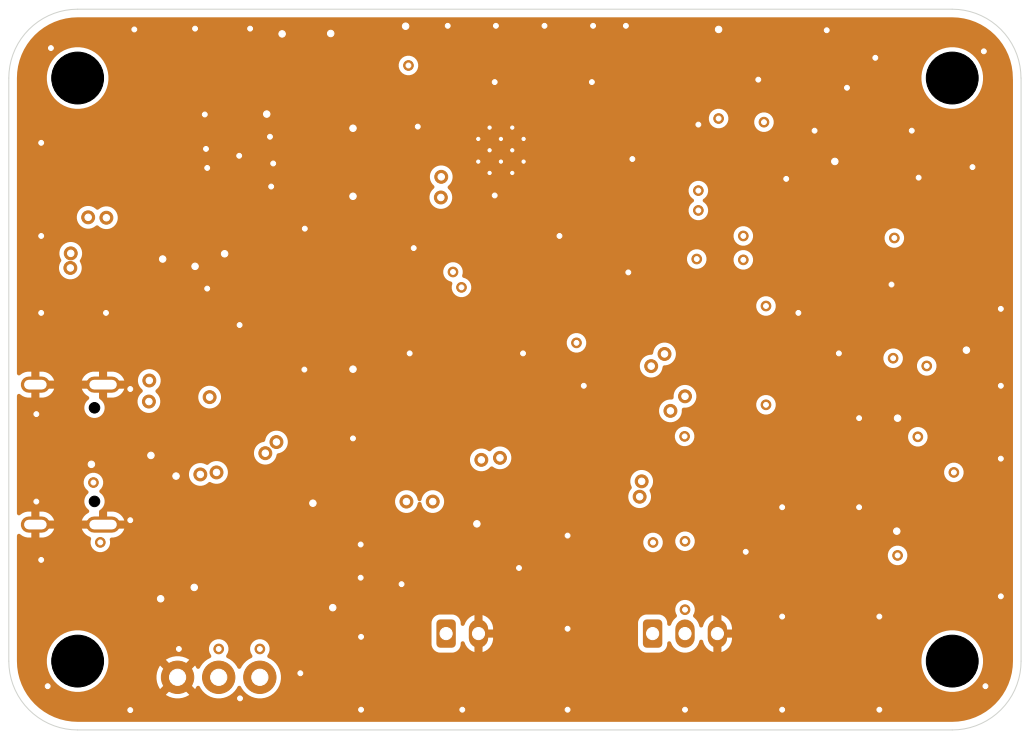
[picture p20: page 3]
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

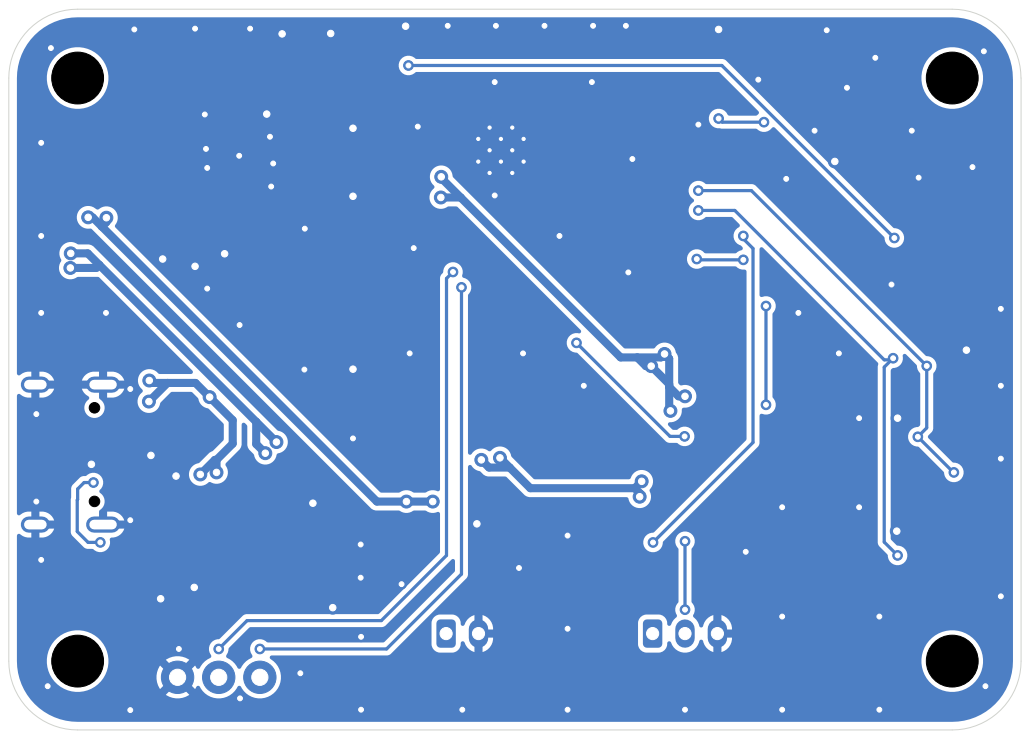
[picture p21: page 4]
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

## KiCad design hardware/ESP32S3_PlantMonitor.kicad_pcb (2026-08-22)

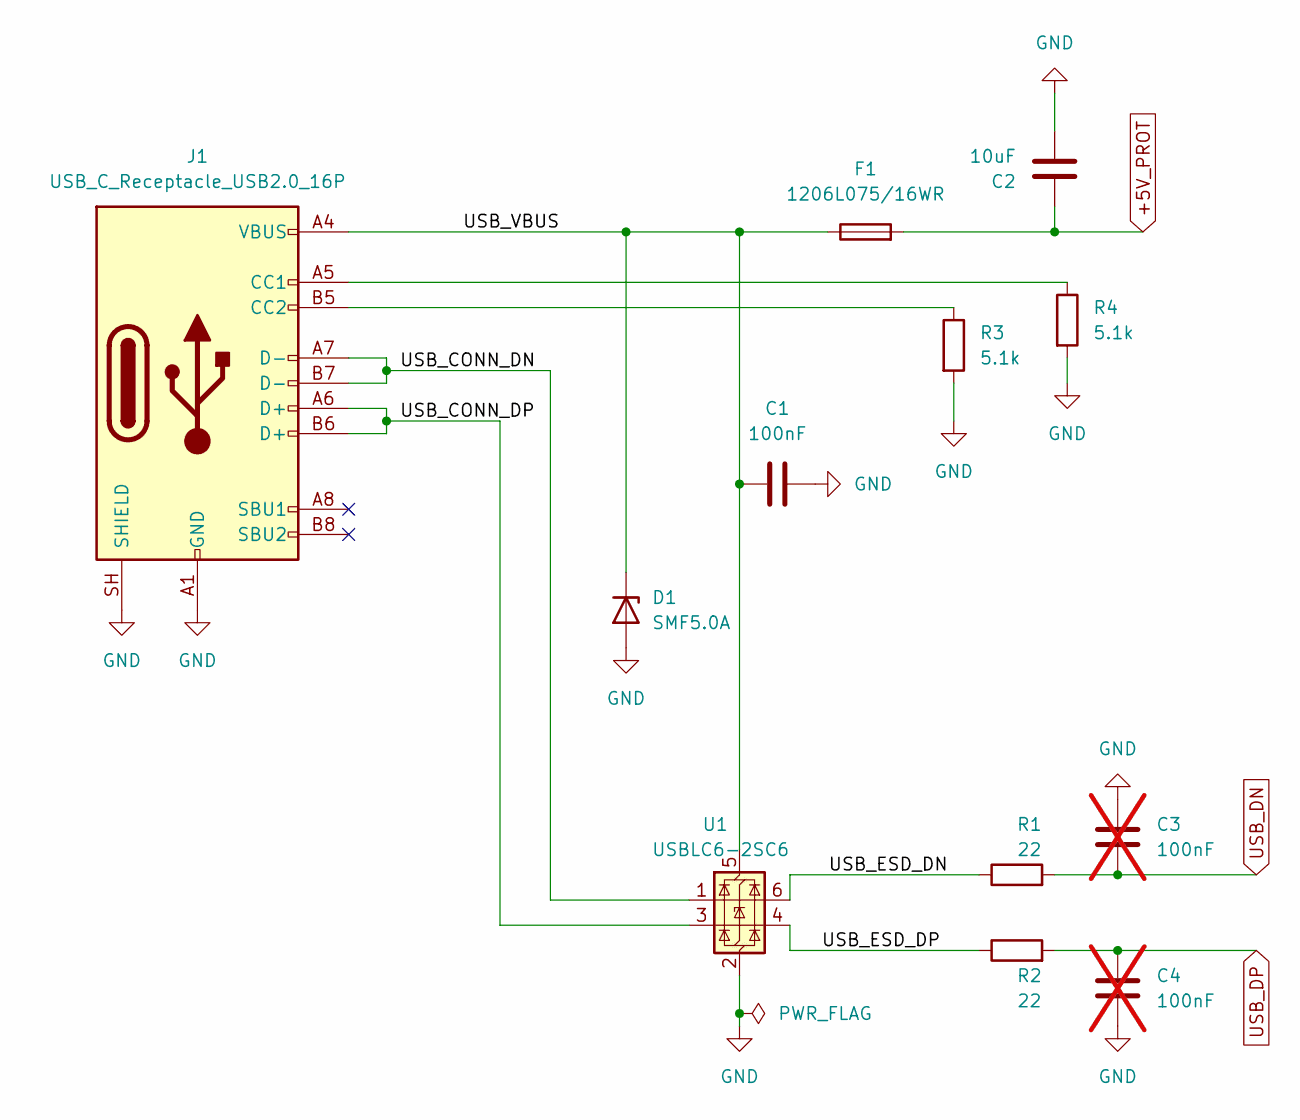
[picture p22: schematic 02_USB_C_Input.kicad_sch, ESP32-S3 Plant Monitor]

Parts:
C1: 100nF; C_0603_1608Metric; LCSC Part C14663
C2: 10uF; C_0805_2012Metric; LCSC Part C15850
C3, C4: 100nF; C_0603_1608Metric; LCSC Part C14663; not fitted
D1: SMF5.0A; D_SOD-123F; LCSC Part C2980403
F1: 1206L075/16WR; Fuse_1206_3216Metric; LCSC Part C371166
J1: USB_C_Receptacle_USB2.0_16P; USB_C_Receptacle_HRO_TYPE-C-31-M-12; LCSC Part C165948
R1, R2: 22; R_0603_1608Metric; LCSC Part C23345
R3, R4: 5.1k; R_0603_1608Metric; LCSC Part C23186
U1: USBLC6-2SC6; SOT-23-6; LCSC Part C7519

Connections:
+5V_PROT: C2.1, F1.2; also elsewhere on the board
/02_USB_C_Input/USB_CONN_DN: J1.A7 (D-), J1.B7 (D-), U1.1 (I/O1)
/02_USB_C_Input/USB_CONN_DP: J1.A6 (D+), J1.B6 (D+), U1.3 (I/O2)
/02_USB_C_Input/USB_ESD_DN: R1.1, U1.6 (I/O1)
/02_USB_C_Input/USB_ESD_DP: R2.1, U1.4 (I/O2)
/02_USB_C_Input/USB_VBUS: C1.1, D1.1 (K), F1.1, J1.A4 (VBUS), J1.A9 (VBUS), J1.B4 (VBUS), J1.B9 (VBUS), U1.5 (VBUS)
GND: C1.2, C2.2, C3.2, C4.1, D1.2 (A), J1.A1 (GND), J1.A12 (GND), J1.B1 (GND), J1.B12 (GND), J1.SH (SHIELD), R3.2, R4.2, U1.2 (GND); also elsewhere on the board
unnamed: J1.A5 (CC1), R4.1
unnamed: J1.B5 (CC2), R3.1
USB_DN: C3.1, R1.2; also elsewhere on the board
USB_DP: C4.2, R2.2; also elsewhere on the board

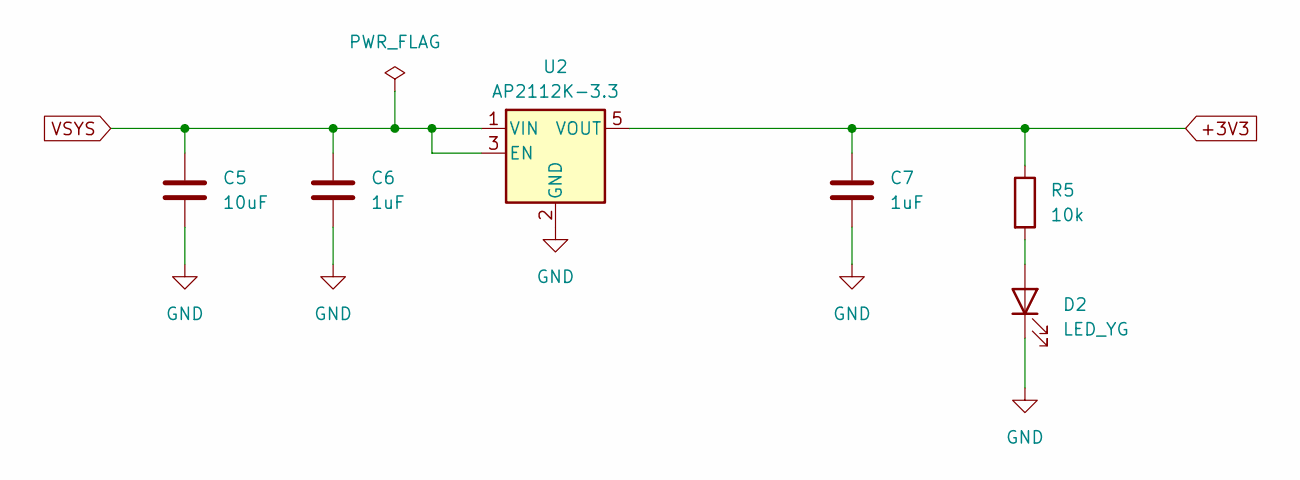
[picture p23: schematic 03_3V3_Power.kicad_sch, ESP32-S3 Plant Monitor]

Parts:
C5: 10uF; C_0805_2012Metric; LCSC Part C15850
C6, C7: 1uF; C_0603_1608Metric; LCSC Part C15849
D2: LED_YG; LED_0603_1608Metric; LCSC Part C2289
R5: 10k; R_0603_1608Metric; LCSC Part C25804
U2: AP2112K-3.3; SOT-23-5; LCSC Part C51118

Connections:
+3V3: C7.1, R5.1, U2.5 (VOUT); also elsewhere on the board
GND: C5.2, C6.2, C7.2, D2.1 (K), U2.2 (GND); also elsewhere on the board
unnamed: D2.2 (A), R5.2
VSYS: C5.1, C6.1, U2.1 (VIN), U2.3 (EN); also elsewhere on the board

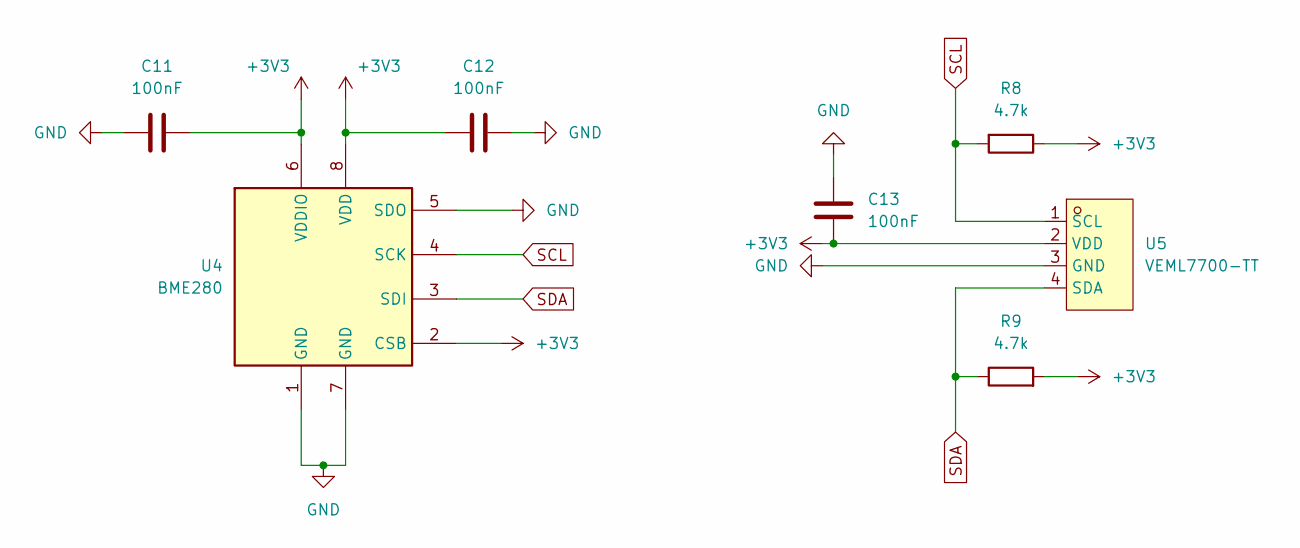
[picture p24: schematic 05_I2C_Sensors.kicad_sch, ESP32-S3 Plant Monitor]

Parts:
C11, C12, C13: 100nF; C_0603_1608Metric; LCSC Part C14663
R8, R9: 4.7k; R_0603_1608Metric; LCSC Part C23162
U4: BME280; Bosch_LGA-8_2.5x2.5mm_P0.65mm_ClockwisePinNumbering; LCSC Part C92489
U5: VEML7700-TT; SENSOR-SMD_EML7700-TT; MPN VEML7700-TT; LCSC Part C1850416

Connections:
+3V3: C11.2, C12.2, C13.2, R8.1, R9.2, U4.2 (CSB), U4.6 (VDDIO), U4.8 (VDD), U5.2 (VDD); also elsewhere on the board
GND: C11.1, C12.1, C13.1, U4.1 (GND), U4.5 (SDO), U4.7 (GND), U5.3 (GND); also elsewhere on the board
SCL: R8.2, U4.4 (SCK), U5.1 (SCL); also elsewhere on the board
SDA: R9.1, U4.3 (SDI), U5.4 (SDA); also elsewhere on the board

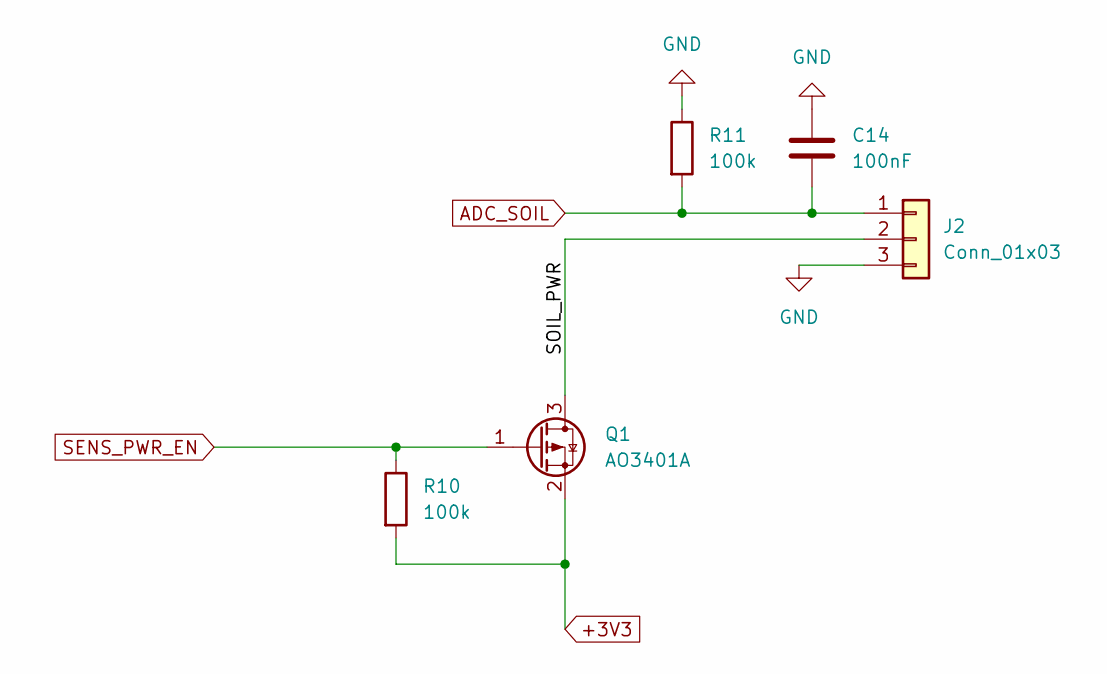
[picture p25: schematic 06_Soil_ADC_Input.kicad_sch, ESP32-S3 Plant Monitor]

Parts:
C14: 100nF; C_0603_1608Metric; LCSC Part C14663
J2: Conn_01x03; JST_PH_S3B-PH-K_1x03_P2.00mm_Horizontal; LCSC Part C157929
Q1: AO3401A; SOT-23; LCSC Part C15127
R10, R11: 100k; R_0603_1608Metric; LCSC Part C25803

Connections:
+3V3: Q1.2 (S), R10.2; also elsewhere on the board
/06_Soil_Probe_Input/SOIL_PWR: J2.2, Q1.3 (D)
ADC_SOIL: C14.2, J2.1, R11.2; also elsewhere on the board
GND: C14.1, J2.3, R11.1; also elsewhere on the board
SENS_PWR_EN: Q1.1 (G), R10.1; also elsewhere on the board

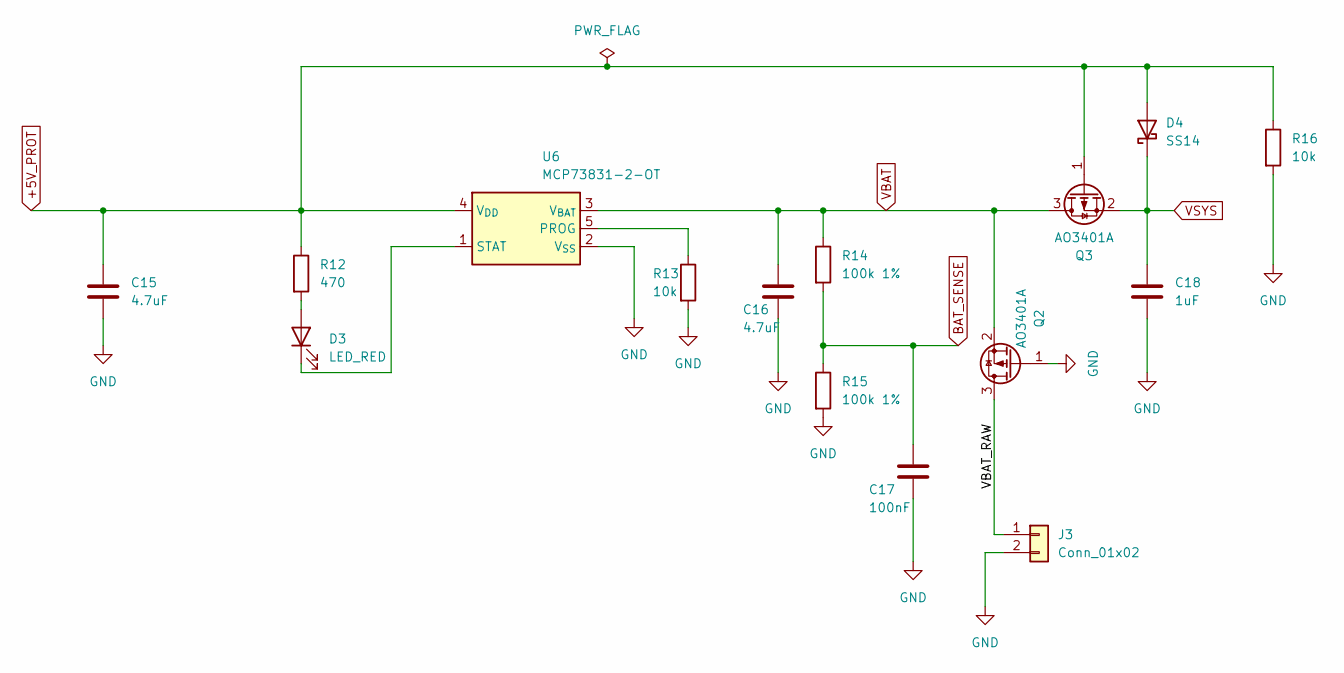
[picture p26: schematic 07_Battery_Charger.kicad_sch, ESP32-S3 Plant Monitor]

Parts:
C15, C16: 4.7uF; C_0603_1608Metric; LCSC Part C19666
C17: 100nF; C_0603_1608Metric; LCSC Part C14663
C18: 1uF; C_0603_1608Metric; LCSC Part C15849
D3: LED_RED; LED_0603_1608Metric; LCSC Part C2286
D4: SS14; D_SMA; LCSC Part C2480
J3: Conn_01x02; JST_PH_S2B-PH-K_1x02_P2.00mm_Horizontal; LCSC Part C173752
Q2, Q3: AO3401A; SOT-23; LCSC Part C15127
R12: 470; R_0603_1608Metric; LCSC Part C23179
R13, R16: 10k; R_0603_1608Metric; LCSC Part C25804
R14, R15: 100k 1%; R_0603_1608Metric; LCSC Part C25803
U6: MCP73831-2-OT; SOT-23-5; LCSC Part C424093

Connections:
+5V_PROT: C15.1, D4.2 (A), Q3.1 (G), R12.1, R16.1, U6.4 (V_{DD}); also elsewhere on the board
/07_Battery_PowerPath/VBAT_RAW: J3.1, Q2.3 (D)
BAT_SENSE: C17.1, R14.2, R15.1; also elsewhere on the board
GND: C15.2, C16.2, C17.2, C18.2, J3.2, Q2.1 (G), R13.2, R15.2, R16.2, U6.2 (V_{SS}); also elsewhere on the board
unnamed: D3.2 (A), R12.2
unnamed: D3.1 (K), U6.1 (STAT)
unnamed: R13.1, U6.5 (PROG)
VBAT: C16.1, Q2.2 (S), Q3.3 (D), R14.1, U6.3 (V_{BAT}); also elsewhere on the board
VSYS: C18.1, D4.1 (K), Q3.2 (S); also elsewhere on the board

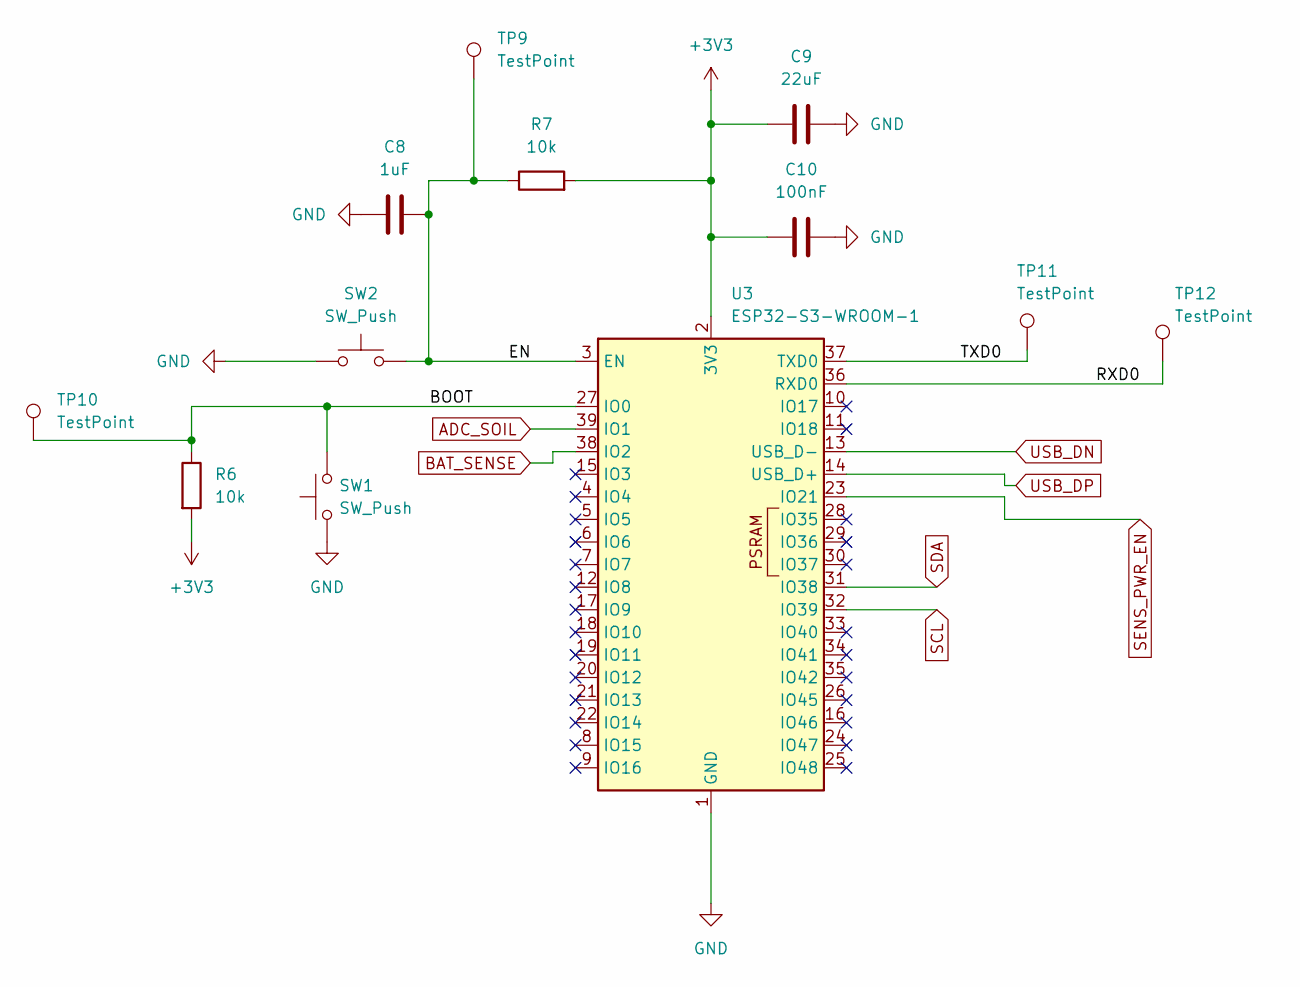
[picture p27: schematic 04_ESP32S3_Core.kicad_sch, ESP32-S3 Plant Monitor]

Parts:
C8: 1uF; C_0603_1608Metric; LCSC Part C15849
C9: 22uF; C_0805_2012Metric; LCSC Part C45783
C10: 100nF; C_0603_1608Metric; LCSC Part C14663
R6, R7: 10k; R_0603_1608Metric; LCSC Part C25804
SW1, SW2: SW_Push; SW-SMD_4P-L5.1-W5.1-P3.70-LS6.5-TL_H1.5; LCSC Part C318884
TP9, TP10: TestPoint; TestPoint_Pad_D1.5mm
TP11, TP12: TestPoint; TestPoint_THTPad_D2.0mm_Drill1.0mm
U3: ESP32-S3-WROOM-1; LCSC Part C2913198

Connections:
+3V3: C9.1, C10.1, R6.2, R7.2, U3.2 (3V3); also elsewhere on the board
/04_ESP32S3_Core/BOOT: R6.1, SW1.2, TP10.1 (1_1), U3.27 (IO0)
/04_ESP32S3_Core/EN: C8.2, R7.1, SW2.2, TP9.1 (1_1), U3.3 (EN)
/04_ESP32S3_Core/RXD0: TP12.1 (1_1), U3.36 (RXD0)
/04_ESP32S3_Core/TXD0: TP11.1 (1_1), U3.37 (TXD0)
ADC_SOIL: U3.39 (IO1); also elsewhere on the board
BAT_SENSE: U3.38 (IO2); also elsewhere on the board
GND: C8.1, C9.2, C10.2, SW1.1, SW2.1, U3.1 (GND), U3.40 (GND), U3.41 (GND); also elsewhere on the board
SCL: U3.32 (IO39); also elsewhere on the board
SDA: U3.31 (IO38); also elsewhere on the board
SENS_PWR_EN: U3.23 (IO21); also elsewhere on the board
USB_DN: U3.13 (USB_D-); also elsewhere on the board
USB_DP: U3.14 (USB_D+); also elsewhere on the board

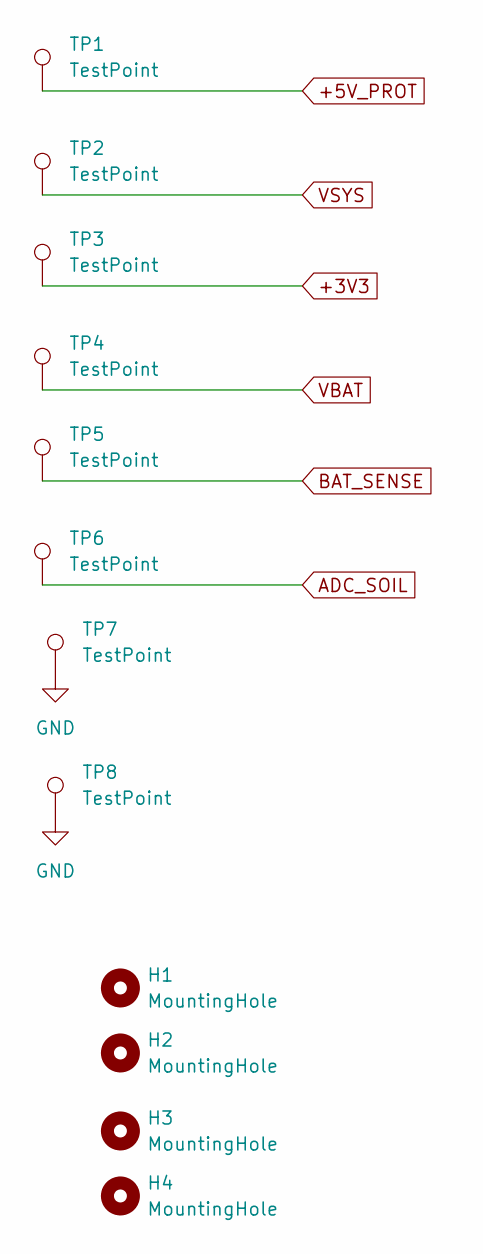
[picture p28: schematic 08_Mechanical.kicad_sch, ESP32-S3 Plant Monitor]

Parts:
H1, H2, H3, H4: MountingHole; MountingHole_3.2mm_M3
TP1, TP2, TP3, TP4, TP5, TP6, TP7: TestPoint; TestPoint_Pad_D1.5mm
TP8: TestPoint; TestPoint_THTPad_D2.0mm_Drill1.0mm

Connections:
+3V3: TP3.1 (1_1); also elsewhere on the board
+5V_PROT: TP1.1 (1_1); also elsewhere on the board
ADC_SOIL: TP6.1 (1_1); also elsewhere on the board
BAT_SENSE: TP5.1 (1_1); also elsewhere on the board
GND: TP7.1 (1_1), TP8.1 (1_1); also elsewhere on the board
VBAT: TP4.1 (1_1); also elsewhere on the board
VSYS: TP2.1 (1_1); also elsewhere on the board

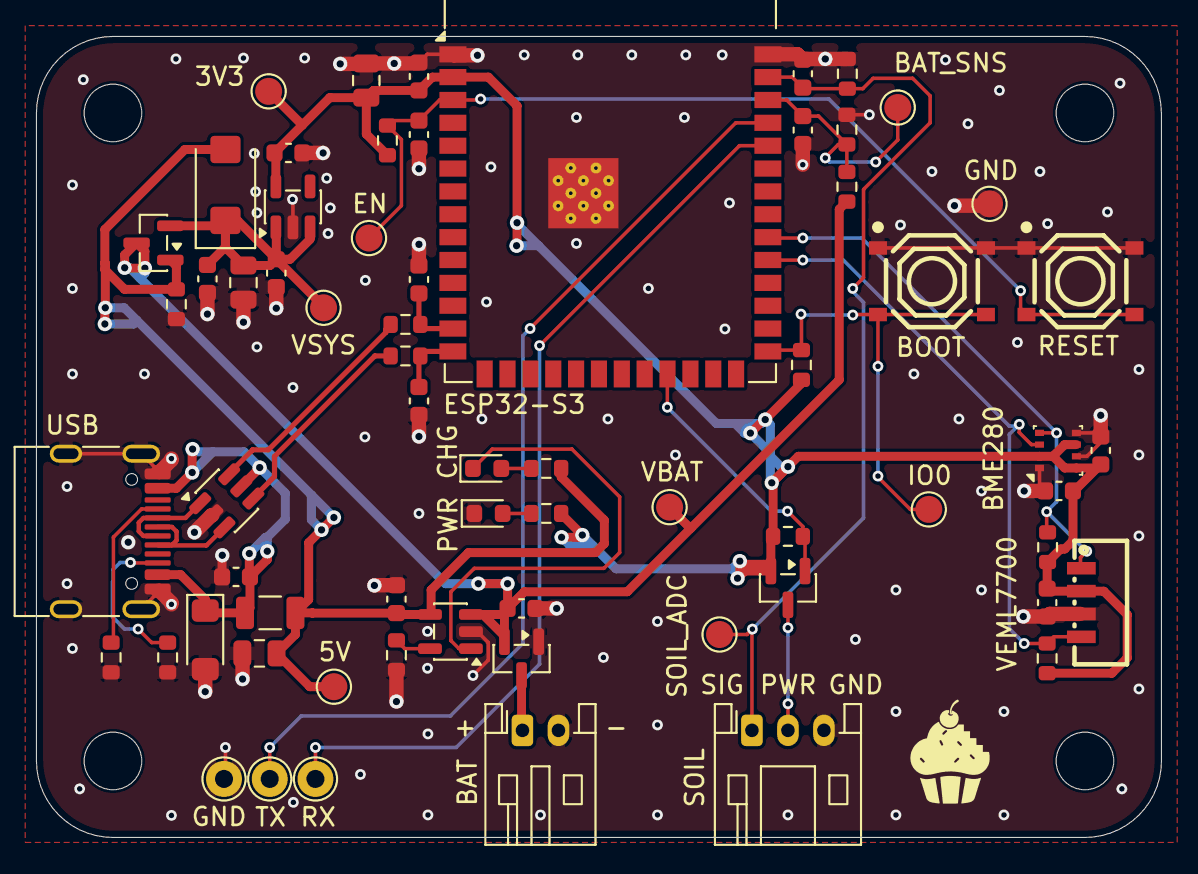
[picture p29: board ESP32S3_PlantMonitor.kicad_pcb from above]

Board: 4 copper layers, 62.5 x 44.5 mm, 70 parts (0 on the bottom side), 29 nets.

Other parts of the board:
G1: muffinByteLogo_2x

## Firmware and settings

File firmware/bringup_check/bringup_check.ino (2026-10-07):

// bringup_check.ino — Rev A hardware bring-up helper
//
// Covers BringUp_Guide.md steps 4, 5 and 6 in one flash, and pre-loads the
// numbers step C-8 needs. Deliberately DOES NOT sleep: the USB port on this
// board is the ESP32-S3's own USB Serial/JTAG peripheral, not a bridge chip,
// so a board in deep sleep has no COM port and every upload after that needs
// the hold-BOOT / tap-RESET dance. This sketch stays awake and keeps the port.
//
// There is no GPIO-controlled LED on Rev A — D2 is hardwired to +3V3 through
// R5 and D3 belongs to the charger — so "is it alive?" is answered over serial.
//
// Pins from docs/PinMap_CheatSheet.md (I2C re-pinned to IO38/IO39 2026-08-15).

#include <Wire.h>
#include "esp_system.h"

#define PIN_SDA          38
#define PIN_SCL          39
#define PIN_ADC_SOIL      1   // ADC1_CH0, direct, no divider
#define PIN_BAT_SENSE     2   // ADC1_CH1, VBAT / 2 via R14/R15
#define PIN_SENS_PWR_EN  21   // LOW = probe on. Left released here.
#define ADC_SAMPLES      16

static const char *resetReasonName(esp_reset_reason_t r) {
  switch (r) {
    case ESP_RST_POWERON:  return "POWERON  (cold start / battery connect)";
    case ESP_RST_EXT:      return "EXT      (RESET button, SW2)";
    case ESP_RST_SW:       return "SW       (software restart)";
    case ESP_RST_PANIC:    return "PANIC    (exception / crash)";
    case ESP_RST_INT_WDT:  return "INT_WDT  (interrupt watchdog)";
    case ESP_RST_TASK_WDT: return "TASK_WDT (task watchdog)";
    case ESP_RST_WDT:      return "WDT      (other watchdog)";
    case ESP_RST_DEEPSLEEP:return "DEEPSLEEP(woke from deep sleep)";
    case ESP_RST_BROWNOUT: return "BROWNOUT <-- THIS IS THE STEP 9 FAILURE";
    case ESP_RST_SDIO:     return "SDIO";
    default:               return "UNKNOWN";
  }
}

static uint32_t readAvgRaw(int pin) {
  uint32_t acc = 0;
  for (int i = 0; i < ADC_SAMPLES; i++) { acc += analogRead(pin); delay(2); }
  return acc / ADC_SAMPLES;
}

static uint32_t readAvgMv(int pin) {
  uint32_t acc = 0;
  for (int i = 0; i < ADC_SAMPLES; i++) { acc += analogReadMilliVolts(pin); delay(2); }
  return acc / ADC_SAMPLES;
}

void i2cScan() {
  Serial.println(F("  I2C scan on SDA=38 SCL=39:"));
  int found = 0;
  for (uint8_t addr = 1; addr < 127; addr++) {
    Wire.beginTransmission(addr);
    if (Wire.endTransmission() == 0) {
      found++;
      Serial.printf("    0x%02X  <-- %s\n", addr,
        addr == 0x76 ? "BME280   (expected)" :
        addr == 0x10 ? "VEML7700 (expected)" : "UNEXPECTED DEVICE");
    }
  }
  if (!found) Serial.println(F("    NOTHING FOUND. Check R8/R9 pull-ups, U4 SDO->GND, U5 solder."));
  else {
    Serial.printf("    %d device(s). Step 5 passes only with BOTH 0x76 and 0x10.\n", found);
  }
}

void setup() {
  // Probe stays off: released, so R10's pull-up holds Q1's gate high.
  pinMode(PIN_SENS_PWR_EN, INPUT);

  Serial.begin(115200);
  uint32_t t0 = millis();
  while (!Serial && (millis() - t0) < 3000) { delay(10); }
  delay(200);

  Serial.println();
  Serial.println(F("================================================"));
  Serial.println(F(" ESP32-S3 Plant Monitor Rev A - bring-up check"));
  Serial.println(F("================================================"));

  esp_reset_reason_t r = esp_reset_reason();
  Serial.printf("  Reset reason : %s\n", resetReasonName(r));
  Serial.printf("  Chip         : %s rev %d, %d core(s)\n",
                ESP.getChipModel(), ESP.getChipRevision(), ESP.getChipCores());
  Serial.printf("  Flash        : %u MB  (expect 8 for WROOM-1-N8)\n",
                (unsigned)(ESP.getFlashChipSize() / (1024 * 1024)));
  Serial.printf("  PSRAM        : %u bytes (expect 0 on N8)\n", (unsigned)ESP.getPsramSize());
  Serial.println();

  Wire.begin(PIN_SDA, PIN_SCL, 100000UL);
  i2cScan();
  Serial.println();

  analogReadResolution(12);
  analogSetPinAttenuation(PIN_ADC_SOIL,  ADC_11db);
  analogSetPinAttenuation(PIN_BAT_SENSE, ADC_11db);

  Serial.println(F("  Streaming ADC every 2 s. Ctrl-click reset (SW2) to re-run header."));
  Serial.println();
}

void loop() {
  uint32_t batRaw = readAvgRaw(PIN_BAT_SENSE);
  uint32_t batMv  = readAvgMv(PIN_BAT_SENSE);
  uint32_t soRaw  = readAvgRaw(PIN_ADC_SOIL);
  uint32_t soMv   = readAvgMv(PIN_ADC_SOIL);

  Serial.printf("BAT_SENSE %4u raw  %4u mV  -> VBAT ~%u mV   |   ADC_SOIL %4u raw  %4u mV\n",
                (unsigned)batRaw, (unsigned)batMv, (unsigned)(batMv * 2),
                (unsigned)soRaw, (unsigned)soMv);
  delay(2000);
}

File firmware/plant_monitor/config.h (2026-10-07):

// config.h — every number this board imposes on the firmware, in one place.
//
// Most of these are not arbitrary. Each one falls out of a measurement I took or
// a limit in a datasheet, and both are written up in docs/. Where that is true I
// have named the document, so when I come back to this in a year I can re-read
// the argument instead of guessing whether a constant is safe to move.
//
// Pin numbers are GPIO numbers, and they match docs/PinMap_CheatSheet.md. If the
// two ever disagree, the cheat sheet is right — it was re-extracted from the
// board netlist after the I2C re-pin on 2026-08-15.

#pragma once

// ---------------------------------------------------------------------------
// Identity
// ---------------------------------------------------------------------------

// Goes into the MQTT topics and the Home Assistant unique_ids. Change it per
// board if I ever build more than one, otherwise two boards will fight over the
// same entities.
#define NODE_ID          "plant-01"
#define NODE_NAME        "Plant Monitor"
#define NODE_MODEL       "ESP32-S3 Plant Monitor Rev A"
#define NODE_MANUFACTURER "MuffinByte Labs"
#define FIRMWARE_VERSION "1.0.0"

// ---------------------------------------------------------------------------
// Pins — see docs/PinMap_CheatSheet.md
// ---------------------------------------------------------------------------

// I2C moved from IO4/IO5 to IO38/IO39 during layout so the bus could leave the
// module on the side that faces the sensors. Wire.begin() takes SDA first, and I
// have got that the wrong way round before, so: 38 is data, 39 is clock.
#define PIN_SDA           38
#define PIN_SCL           39

// Both analogue inputs sit on ADC1, and that matters: ADC2 is unusable on the
// ESP32-S3 while the radio is up. Nothing here has to be re-ordered around Wi-Fi
// because of it, but I still read both ADCs before the radio starts.
#define PIN_ADC_SOIL       1   // ADC1_CH0, direct from the probe, no divider
#define PIN_BAT_SENSE      2   // ADC1_CH1, VBAT / 2 through R14/R15

// Q1 is a high-side P-FET with a 100k pull-up (R10) on its gate. LOW turns the
// probe on; anything else — driven high, or the pin released entirely — leaves
// R10 holding it off. That pull-up is what keeps the probe dark through deep
// sleep and through the boot window before this code runs.
#define PIN_SENS_PWR_EN   21
#define PROBE_ON          LOW
#define PROBE_OFF         HIGH

// ---------------------------------------------------------------------------
// I2C addresses
// ---------------------------------------------------------------------------

// BME280 is at 0x76 because I tied SDO to GND (CSB to 3V3). VEML7700's address
// is fixed in silicon.
#define I2C_ADDR_BME280   0x76
#define I2C_ADDR_VEML7700 0x10
#define I2C_CLOCK_HZ      100000UL   // 100 kHz. Nothing here is in a hurry and
                                     // the probe cable is a metre of antenna.

// ---------------------------------------------------------------------------
// Battery thresholds — the half-volt that belongs to firmware
// ---------------------------------------------------------------------------
//
// The pack's own protection module (S-8261AAJMD) does not disconnect until
// 2.5 V, but PKCell's discharge floor for the cell is 3.0 V. Everything in that
// gap is wear, not disaster, and nothing on this board is watching it except
// this file. See docs/Engineering_Notes.md section 4.

// Stop transmitting below this. This is a regulator rule, not a battery rule:
// the AP2112K needs roughly 200 mV of headroom to hold 3.3 V through a 355 mA
// Wi-Fi TX peak. Waking, reading sensors and going back to sleep are all still
// fine below it — only the radio is banned.
#define TX_CUTOFF_MV      3500

// Stop everything below this. The battery rule. Below here I read nothing and
// send nothing, I just go back to sleep on the long interval and wait to be
// charged.
#define SLEEP_CUTOFF_MV   3000

// A little hysteresis so a board sitting exactly on a threshold does not flap
// between "transmit" and "do not transmit" on consecutive wakes.
#define CUTOFF_HYSTERESIS_MV 50

// ---------------------------------------------------------------------------
// Battery sense chain
// ---------------------------------------------------------------------------

// R14/R15 are 100k 1% each, so BAT_SENSE is exactly half of VBAT and reads
// 2.10 V at a full 4.20 V cell — comfortably inside the ADC's usable range at
// 12 dB attenuation.
#define BAT_DIVIDER_RATIO 2.0f
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

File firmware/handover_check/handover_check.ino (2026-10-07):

// handover_check.ino — Rev A bring-up steps 9 and 10
//
// WHY THIS EXISTS
// bringup_check.ino prints the reset reason once, in setup(). That is fine on
// the bench and useless for step 9, because step 9's event IS pulling USB, and
// this board's serial port is the ESP32-S3's own USB peripheral. Pull USB and
// the COM port vanishes. If the board then browns out and reboots, it prints
// "BROWNOUT" into a port nobody is attached to, and by the time USB is back the
// header has already scrolled past.
//
// So this sketch does two things differently:
//   1. It latches the reset reason at boot and repeats it on EVERY line.
//   2. It prints uptime on every line. Uptime is an independent reset detector
//      that needs no reset-reason register at all: if the number jumped back to
//      about zero while USB was out, the board rebooted. If it kept counting,
//      it rode through. UPTIME IS THE RELIABLE SIGNAL - trust it over the
//      boot counter, which lives in RTC memory and is reloaded from flash by
//      the bootloader on most reset types, so it may read 1 after a reboot
//      instead of incrementing.
//   3. It mirrors everything to UART0 (TP11 = TXD0, TP12 = RXD0, TP8 = GND).
//      Attach a 3.3 V USB-serial adapter there and the log keeps flowing while
//      the board's own USB is unplugged. That is what those pads are for.
//      NEVER connect the adapter's 5 V or 3V3 power pin. TX/RX/GND only.
//
// READING THE RESULT after you plug USB back in: look at the first line.
//   uptime kept climbing, reason unchanged  -> PASS, board rode through
//   uptime restarted near 0, reason BROWNOUT -> FAIL, R16 or gate capacitance
//   uptime restarted near 0, reason POWERON  -> rail collapsed completely
//
// Pins per docs/PinMap_CheatSheet.md. I2C is IO38/IO39 (re-pinned 2026-08-15).

#include <Wire.h>
#include <stdarg.h>
#include "esp_system.h"

#define PIN_SDA           38
#define PIN_SCL           39
#define PIN_ADC_SOIL       1   // ADC1_CH0, direct, no divider
#define PIN_BAT_SENSE      2   // ADC1_CH1, VBAT / 2 via R14/R15
#define PIN_SENS_PWR_EN   21   // Q1 gate. LOW = probe ON, released = off.
#define ADC_SAMPLES       16   // config.h assumes 16. Match it.
#define LINE_INTERVAL_MS 500   // fast enough to catch the moment of the event

// Soil probe. Set to 0 to skip it and get a faster line rate.
// The probe MUST be powered before reading, or R11 pulls ADC_SOIL to ground
// and you read ~0 regardless of what is in the pot. LOW on Q1 = probe ON.
#define SOIL_ENABLED       1
#define SOIL_SETTLE_MS   250   // matches sensor_check.ino

// With "USB CDC On Boot" enabled, Serial is the USB port and Serial0 is UART0.
// With it disabled, Serial already IS UART0 and mirroring would double-print.
#if ARDUINO_USB_CDC_ON_BOOT
  #define MIRROR_TO_UART0 1
#else
  #define MIRROR_TO_UART0 0
#endif

RTC_DATA_ATTR static uint32_t bootCount = 0;   // survives most resets

static esp_reset_reason_t g_resetReason;
static const char *g_resetName;

static const char *resetReasonName(esp_reset_reason_t r) {
  switch (r) {
    case ESP_RST_POWERON:   return "POWERON";
    case ESP_RST_EXT:       return "EXT";
    case ESP_RST_SW:        return "SW";
    case ESP_RST_PANIC:     return "PANIC";
    case ESP_RST_INT_WDT:   return "INT_WDT";
    case ESP_RST_TASK_WDT:  return "TASK_WDT";
    case ESP_RST_WDT:       return "WDT";
    case ESP_RST_DEEPSLEEP: return "DEEPSLEEP";
    case ESP_RST_BROWNOUT:  return "BROWNOUT";
    case ESP_RST_SDIO:      return "SDIO";
    default:                return "UNKNOWN";
  }
}

// Print to the USB port and to UART0 at the same time.
static void out(const char *fmt, ...) {
  char buf[220];
  va_list ap;
  va_start(ap, fmt);
  vsnprintf(buf, sizeof(buf), fmt, ap);
  va_end(ap);
  Serial.print(buf);
#if MIRROR_TO_UART0
  Serial0.print(buf);
#endif
}

static uint32_t readAvgRaw(int pin) {
  uint32_t acc = 0;
  for (int i = 0; i < ADC_SAMPLES; i++) { acc += analogRead(pin); delay(2); }
  return acc / ADC_SAMPLES;
}

static uint32_t readAvgMv(int pin) {
  uint32_t acc = 0;
  for (int i = 0; i < ADC_SAMPLES; i++) { acc += analogReadMilliVolts(pin); delay(2); }
  return acc / ADC_SAMPLES;
}

void setup() {
  // Park the probe off at boot: released, so R10's pull-up holds Q1's gate
  // high. loop() powers it on demand when SOIL_ENABLED.
  pinMode(PIN_SENS_PWR_EN, INPUT);

  // Latch the reset reason FIRST, before anything can disturb it.
  g_resetReason = esp_reset_reason();
  g_resetName   = resetReasonName(g_resetReason);
  bootCount++;

  Serial.begin(115200);
#if MIRROR_TO_UART0
  Serial0.begin(115200);   // TP11 = TXD0 (GPIO43), TP12 = RXD0 (GPIO44)
#endif

  // Do NOT block forever waiting for a host: on battery there is no host.
  uint32_t t0 = millis();
  while (!Serial && (millis() - t0) < 2000) { delay(10); }
  delay(100);

  out("\n=================================================\n");
  out(" Rev A hand-over check - bring-up steps 9 and 10\n");
  out("=================================================\n");
  out("  Reset reason : %s\n", g_resetName);
  out("  Boot count   : %u (best effort - uptime is the reliable signal)\n",
      (unsigned)bootCount);
  out("  Chip         : %s rev %d\n", ESP.getChipModel(), ESP.getChipRevision());
  if (g_resetReason == ESP_RST_BROWNOUT) {
    out("  *** BROWNOUT - this is the step 9 FAILURE signature ***\n");
  }
  out("\n");

  Wire.begin(PIN_SDA, PIN_SCL, 100000UL);

  analogReadResolution(12);
  analogSetPinAttenuation(PIN_ADC_SOIL,  ADC_11db);
  analogSetPinAttenuation(PIN_BAT_SENSE, ADC_11db);

  out("  up(s) | reset    | boot | VBAT     | BAT raw | SOIL raw\n");
  out("  ------+----------+------+----------+---------+---------\n");
}

void loop() {
  // Battery first, with the probe still off, so the probe's current draw
  // cannot disturb the reading.
  uint32_t batRaw = readAvgRaw(PIN_BAT_SENSE);
  uint32_t batMv  = readAvgMv(PIN_BAT_SENSE);

  // Soil: power the probe, let it settle, average, then release the gate.
  // 16 samples here, unlike sensor_check.ino's single sample - this is the
  // averaging config.h assumes, so these numbers are calibration-grade.
  uint32_t soRaw = 0;
#if SOIL_ENABLED
  pinMode(PIN_SENS_PWR_EN, OUTPUT);
  digitalWrite(PIN_SENS_PWR_EN, LOW);      // LOW = probe ON
  delay(SOIL_SETTLE_MS);
  soRaw = readAvgRaw(PIN_ADC_SOIL);
  pinMode(PIN_SENS_PWR_EN, INPUT);         // release; R10 holds Q1 off
#endif

  // Uptime is the reset detector that needs no register: watch this number.
  // Formatted with integer math on purpose - no %f, so it cannot be defeated
  // by a printf build without float support.
  uint32_t ms = millis();
  out("  %4u.%01u | %-8s | %4u | %4u mV  | %7u | %7u\n",
      (unsigned)(ms / 1000), (unsigned)((ms % 1000) / 100),
      g_resetName, (unsigned)bootCount,
      (unsigned)(batMv * 2), (unsigned)batRaw, (unsigned)soRaw);

  delay(LINE_INTERVAL_MS);
}

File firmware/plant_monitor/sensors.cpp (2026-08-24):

#include "sensors.h"

#include <Wire.h>
#include <Adafruit_BME280.h>
#include <Adafruit_VEML7700.h>

#include "adc.h"
#include "config.h"
#include "log.h"

static Adafruit_BME280   bme;
static Adafruit_VEML7700 veml;

static bool     bmePresent  = false;
static bool     vemlPresent = false;
static bool     busStarted  = false;
static uint32_t probeOnAtMs = 0;

// ---------------------------------------------------------------------------

bool sensorsBegin() {
  // SDA first. The signature is Wire.begin(sda, scl) and I have transposed it
  // before, which produces a bus that scans as completely empty and looks for
  // all the world like a soldering fault.
  Wire.begin(PIN_SDA, PIN_SCL, I2C_CLOCK_HZ);
  busStarted = true;

  bmePresent = bme.begin(I2C_ADDR_BME280, &Wire);
  if (bmePresent) {
    // Forced mode is the whole reason this sensor suits a battery node: it takes
    // one measurement when asked and then parks itself at about 0.1 uA. In
    // normal mode it would keep sampling in the background all the way through
    // deep sleep and quietly wreck the current budget.
    //
    // x1 oversampling on all three. This is a plant pot, not a barometer, and
    // heavier oversampling only lengthens the conversion I have to stay awake
    // for. The IIR filter is off for the same reason — it needs a run of
    // samples to converge, and I take exactly one every half hour.
    bme.setSampling(Adafruit_BME280::MODE_FORCED,
                    Adafruit_BME280::SAMPLING_X1,   // temperature
                    Adafruit_BME280::SAMPLING_X1,   // pressure
                    Adafruit_BME280::SAMPLING_X1,   // humidity
                    Adafruit_BME280::FILTER_OFF);
  } else {
    LOGLN("bme280: no answer at 0x76 - check SDO is at GND and CSB at 3V3");
  }

  vemlPresent = veml.begin(&Wire);
  if (vemlPresent) {
    // Gain and integration time only matter here as a starting point, because
    // the automatic mode below re-picks both to suit the actual light level.
    // Left as-is this would saturate on a bright windowsill and read zero in a
    // dim room, which between them covers most of where this board will live.
    veml.setGain(VEML7700_GAIN_1);
    veml.setIntegrationTime(VEML7700_IT_100MS);
  } else {
    LOGLN("veml7700: no answer at 0x10");
  }

  return bmePresent || vemlPresent;
}

// ---------------------------------------------------------------------------

void soilProbePowerOn() {
  pinMode(PIN_SENS_PWR_EN, OUTPUT);
  digitalWrite(PIN_SENS_PWR_EN, PROBE_ON);
  probeOnAtMs = millis();
}

void soilProbePowerOff() {
  // Driving it high would work, but releasing the pin is better: R10's 100k
  // pull-up holds Q1's gate at 3V3 with no drive current at all, and it goes on
  // holding it through deep sleep and through the next boot, before this code
  // has had a chance to run. That is what R10 is for.
  digitalWrite(PIN_SENS_PWR_EN, PROBE_OFF);
  pinMode(PIN_SENS_PWR_EN, INPUT);
  probeOnAtMs = 0;
}

// ---------------------------------------------------------------------------

void sensorsReadClimateAndLight(Readings &r) {
  if (bmePresent) {
    // Ask for the one measurement, then read it out. This blocks for a few
    // milliseconds at x1 oversampling.
    if (bme.takeForcedMeasurement()) {
      r.temperatureC = bme.readTemperature();
      r.humidityPct  = bme.readHumidity();
      r.pressureHpa  = bme.readPressure() / 100.0f;

      // A dead BME280 on a live bus reads a plausible-looking 0 C / 0 %, so I
      // check rather than trust. -40 C is the part's own lower limit.
      r.climateValid = !isnan(r.temperatureC) && r.temperatureC > -40.0f &&
                       !isnan(r.humidityPct)  && r.humidityPct >= 0.0f;
    }
  }

  if (vemlPresent) {
    // Automatic mode walks gain and integration time until the raw count sits
    // in a sensible part of the range, so one call covers a dark room and a
    // south-facing sill without me choosing a compromise between them.
    float lux = veml.readLux(VEML_LUX_AUTO);
    if (!isnan(lux) && lux >= 0.0f) {
      r.lux        = lux;
      r.lightValid = true;
    }
  }
}

// ---------------------------------------------------------------------------

void sensorsReadSoil(Readings &r) {
  if (probeOnAtMs == 0) return;   // nobody switched the probe on

  // Whatever the I2C reads did not use up of the settle time, spend it here.
  // The probe is a slow analogue thing on the end of a metre of cable and it
  // needs the full quarter-second before its output means anything.
  uint32_t elapsed = millis() - probeOnAtMs;
  if (elapsed < SOIL_SETTLE_MS) delay(SOIL_SETTLE_MS - elapsed);

  r.soilRaw = adcAverageRaw(PIN_ADC_SOIL, ADC_SAMPLES);

  // Output falls as moisture rises, so dry is the larger raw number and the
  // subtraction runs the way it does on purpose.
  float span = (float)(SOIL_RAW_DRY - SOIL_RAW_WET);
  float pct  = ((float)(SOIL_RAW_DRY - r.soilRaw) / span) * 100.0f;

  // I clamp rather than reject. A probe pushed into wetter soil than the water
  // glass I calibrated in genuinely does read below my wet constant, and that
  // is 100 %, not an error. What it is not is 104 %.
  if (pct < 0.0f)   pct = 0.0f;
  if (pct > 100.0f) pct = 100.0f;

  r.soilPct = pct;

  // A raw value pinned at either rail is not soil, it is a fault: 0 or nearly 0
  // means the probe is unpowered or its signal line is shorted, and the top of
  // the range means nothing is connected and R11 is the only thing on the pin.
  r.soilValid = (r.soilRaw > 100) && (r.soilRaw < 4000);
  if (!r.soilValid) {
    LOGF("soil: raw %d is out of range - check J2 and the probe cable\n", r.soilRaw);
  }
}

// ---------------------------------------------------------------------------

void sensorsSleep() {
  // The BME280 parked itself the moment its forced measurement finished. The
  // VEML7700 sits at about 45 uA until it is told otherwise, and my whole sleep
  // budget is 210 uA, so this line is worth a fifth of it.
  if (vemlPresent) veml.enable(false);

  // Only if it was ever started. A cycle that bailed out at the 3.0 V floor
  // never touched the bus, and tearing down something that was never brought up
  // is how a low-battery wake turns into a crash.
  if (busStarted) {
    Wire.end();
    busStarted = false;
  }
}

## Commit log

2026-07-15 Initial Rev A schematic capture (sheets 01-05)
    [02_USB_C_Input.kicad_sch, 03_3V3_Power.kicad_sch, 04_ESP32S3_Core.kicad_sch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]
2026-07-16 Start soil probe input schematic (sheet 06)
    [04_ESP32S3_Core.kicad_sch, 05_I2C_Sensors.kicad_sch]
2026-07-17 Start battery charger schematic (sheet 07)
    [04_ESP32S3_Core.kicad_sch, 06_Soil_ADC_Input.kicad_sch]
2026-07-19 Continue battery charger schematic
    [07_Battery_Charger.kicad_sch]
2026-07-19 Complete battery charger schematic
    [07_Battery_Charger.kicad_sch]
2026-07-20 Final-stage schematic work
    [ESP32S3_PlantMonitor_RevA_BOM.xlsx]
2026-07-21 Rev A schematic review complete: fixes, documentation, repo reorganization
    Schematic (netlist-verified):
    - Ground USB-C GND pins A1/B1/A12/B12 (were no-connected)
    - Battery-sense chain saved: VBAT -> 100k/100k 1% -> BAT_SENSE (IO2) + 100nF
    - Q3 gate pull-down R16 100k -> 10k: USB-unplug hand-over now ~50-100ms
    (was 0.5-1s of body-diode sag causing brown-out resets at mid battery)
    Libraries:
    - sym/fp-lib-table converted from absolute paths to ${KIPRJMOD}-relative
    - logos.pretty registered project-side
    Repo reorganized to standard layout:
    - hardware/ (KiCad + libs), docs/, references/{datasheets,standards,
    reference-designs}, fabrication/, firmware/, README
    - removed superseded bring-up/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
    [02_USB_C_Input.kicad_sch, 03_3V3_Power.kicad_sch, 04_ESP32S3_Core.kicad_sch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]
2026-07-23 Pre-layout finalization and second design review pass (Rev A)
    [02_USB_C_Input.kicad_sch, 03_3V3_Power.kicad_sch, 04_ESP32S3_Core.kicad_sch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]
2026-08-02 J1: project-local USB-C footprint, lower shield-leg drill 1.2->1.4 per HRO drawing
    [02_USB_C_Input.kicad_sch, ESP32S3_PlantMonitor.kicad_pcb]
2026-08-05 Snapshot before 3D model path rework
    [02_USB_C_Input.kicad_sch, 07_Battery_Charger.kicad_sch, ESP32S3_PlantMonitor.kicad_pcb]
2026-08-05 Add 3D models for custom footprints
    [ESP32S3_PlantMonitor.kicad_pcb]
2026-08-09 Component placement: initial floorplan
    [04_ESP32S3_Core.kicad_sch, ESP32S3_PlantMonitor.kicad_pcb]
2026-08-11 Placement refinements
    [ESP32S3_PlantMonitor.kicad_pcb]
2026-08-12 Placement fixes; rounded board corners (R4.25)
    [02_USB_C_Input.kicad_sch, ESP32S3_PlantMonitor.kicad_pcb]
2026-08-15 Routing: bulk of nets complete
    [04_ESP32S3_Core.kicad_sch, ESP32S3_PlantMonitor.kicad_pcb]
2026-08-15 Routing complete pending cleanup
    [ESP32S3_PlantMonitor.kicad_pcb]
2026-08-15 Add stitching and remaining vias
    [ESP32S3_PlantMonitor.kicad_pcb]
2026-08-15 Snapshot before final cleanup
    [ESP32S3_PlantMonitor.kicad_pcb]
2026-08-17 DRC and ERC cleanup
    [02_USB_C_Input.kicad_sch, ESP32S3_PlantMonitor.kicad_pcb]
2026-08-17 Fab prep: board fixes, documentation refresh, order notes, license
    Board/schematic:
    - USB-C ground pads to solid zone connection with adjacent stitching vias
    - C3/C4 DNP + BOM/CPL exclusion flags synced between schematic and board
    - Silkscreen text cleanup
    Docs & repo:
    - PROJECT_STATUS and guides updated to as-built pre-order state
    - JLCPCB order notes added (fabrication/revA): settings, panel remark, stock check
    - CERN-OHL-P v2 license; board renders in README
    - JLC plugin cache untracked; standards texts referenced outside the repo
    [02_USB_C_Input.kicad_sch, 03_3V3_Power.kicad_sch, 04_ESP32S3_Core.kicad_sch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]
2026-08-21 pre-order baseline
    [02_USB_C_Input.kicad_sch, 03_3V3_Power.kicad_sch, 04_ESP32S3_Core.kicad_sch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]
2026-08-22 pcb ordered
    [BOM-ESP32S3_PlantMonitor.csv, ESP32S3_PlantMonitor.kicad_pcb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]
2026-08-23 docs: make the repo readable in a browser, and reconcile it with the board
    A client opening this repo could not see the schematic without installing
    KiCad, and the design document was a Word file whose reference designators
    disagreed with the board. This fixes both.
    Added, all viewable on GitHub without downloads:
    - ESP32S3_PlantMonitor_RevA_Schematic.pdf - all 8 sheets, plotted from the
    ordered board file
    - ESP32S3_PlantMonitor_RevA_FabLayers.pdf - four copper layers, both silks,
    mask and paste
    - board_bottom.png - shows the bottom-silk ID block
    - references/datasheets/README.md - part-to-datasheet index
    Converted to Markdown (Word and raw HTML render as downloads or source):
    - Final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
2026-08-24 docs: correct as-built numbers and prepare the repo for outside readers
    Corrections (each was contradicted elsewhere in the repo, or by the board file):
    - LDO worst-case dissipation 0.34 W -> 0.26 W: VSYS sits at ~4.6 V behind D4,
    not 5 V. Propagated to the rulebook, settings, routing and placement guides.
    - Design doc sleep floor ~100 uA -> ~210 uA as built; the ~100 uA figure
    predated the power LED, as the 07-20 review already noted.
    - Power LED note: 1.5 mA was a leftover from the 1 k draft; it is ~120 uA.
    - Battery line now separates the 1000 mAh class part from the 500 mAh PKCell
    actually used for bring-up.
    - Coupon subtraction made self-consistent: 12.10 + 86.79 - 49.63 = 49.26.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
2026-08-24 firmware: write the Rev A sketch against the hardware contract
    Arduino IDE sketch in firmware/plant_monitor/, split across tabs. One wake
    cycle per boot: setup() runs, the board sleeps at the end of it, and there is
    no loop.
    Order of operations, and why:
    - Battery first, before anything has loaded the cell.
    - Below 3.0 V nothing else happens at all. That is PKCell's discharge floor,
    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
2026-09-14 Update README with current project status and components
    Removed outdated information about Rev A production status and added details about the components used.
2026-10-07 Board #1 bring-up: PCB soil calibration, ThingSpeak and ntfy alerts, README status
